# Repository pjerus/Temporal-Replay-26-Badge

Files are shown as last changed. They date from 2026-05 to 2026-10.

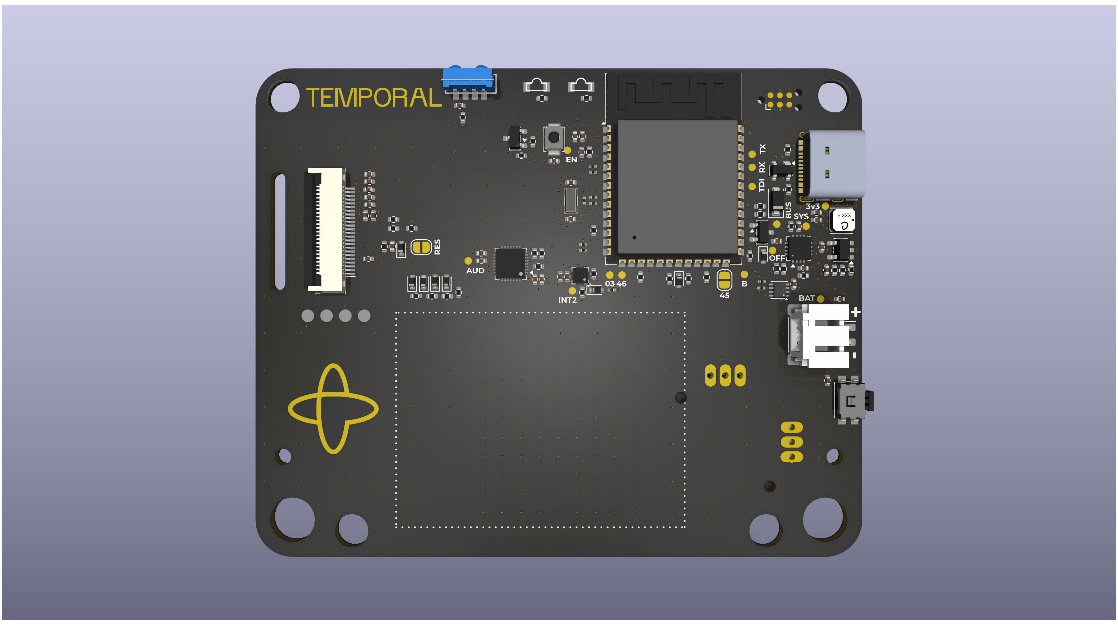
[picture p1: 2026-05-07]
hardware/BRAVO/export/V0_Temporal-BRAVO_Back.png

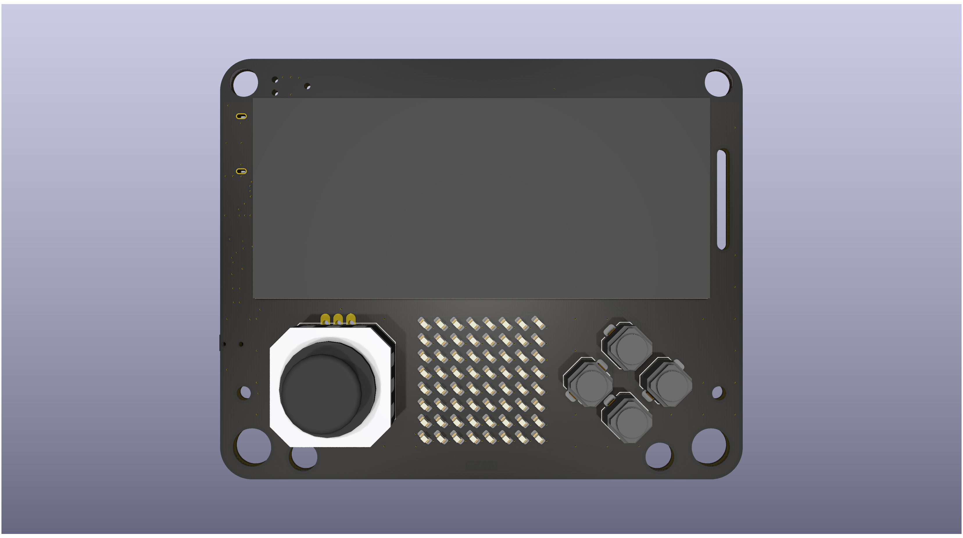
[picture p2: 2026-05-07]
hardware/BRAVO/export/V0_Temporal-BRAVO_Front.png

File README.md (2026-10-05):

# Temporal Badge

Conference badge for Temporal's events. The current build (`echo`) targets an
ESP32-S3-WROOM-1 (N16R8) on a custom board with a 128×64 SSD1309 OLED, IR TX/RX for
attendee pairing, joystick, tilt switch, and NVS-backed identity. (Earlier revisions —
see Hardware Targets below — used other modules; DELTA was an ESP32-S3-MINI-1 XIAO.)

## Hardware

- **MCU**: ESP32-S3 16r8, dual-core Xtensa LX7, 8 MB flash
- **Display**: SSD1309 128×64 OLED via hardware I2C (SDA=D4/GPIO5, SCL=D5/GPIO6)
- **IR**: NEC protocol TX (D2/GPIO3) + RX (D3/GPIO4)
- **Input**: 4 buttons (D7–D10), analog joystick (D0/D1), tilt switch (D6)

## Prerequisites

- Python 3.9+
- All other dependencies (PlatformIO, Temporal CLI, esptool) are installed by `ignition/setup.sh`

## Build & Flash (Ignition)

```bash
cd ignition
./setup.sh        # first time only — installs all dependencies
./start.sh        # build + flash all connected badges
./start.sh --build-and-flash  # explicit build + fresh filesystem + flash
./start.sh -y     # skip the pre-flash Enter prompt for a ready batch
```

Ignition treats each run as one connected hub batch. Temporal starts a parent
`FlashBadgesWorkflow` plus one human-readable `BadgeFlashWorkflow` child per
detected badge, so the UI shows per-badge flash/WiFi progress and results.

See [`ignition/README.md`](ignition/README.md) for full usage, including `--no-build`, `--build-only`, and `--firmware-dir` options.

## Build (Firmware)

```bash
cd firmware

# Echo badge (default)
./build.sh

# Charlie board
./build.sh charlie

# Non-interactive build (skip build-time network prompt)
./build.sh echo -n
```

Or directly via PlatformIO:
```bash
pio run -e echo
pio run -e charlie
```
Direct PlatformIO builds read `firmware/wifi.local.env` or `BADGE_*`
environment variables and fail if WiFi credentials or the server URL are
missing.

### Dev menu build

Normal firmware hides internal debug/test screens. To flash an Echo badge with
the dev menu enabled for diagnostics and badge-info editing:

```bash
cd firmware
pio run -e echo-dev -t upload --upload-port /dev/cu.usbmodem1101
```

`echo-dev` still uses the configured boop API; it only changes menu/debug
visibility. Use a local settings/server override if you need to avoid staging.

Normal firmware boots straight into the badge menu. Production builds show
Boop, Messages, Contacts, New Msg, Settings, and QR / Pair only while the
badge is unpaired; debug/test screens stay behind the dev menu build.

### MicroPython apps

MicroPython app source lives in `firmware/initial_filesystem/apps/` and is
embedded into firmware builds through `firmware/scripts/generate_startup_files.py`.
Use folder apps with a `main.py` entry point for anything larger than a demo.

Normal firmware does not show the generic Apps menu. Attendee-facing
MicroPython apps need a native `GUI.cpp` launcher and icon; diagnostics can
stay in the dev-menu Apps browser. See
[`firmware/initial_filesystem/apps/README.md`](firmware/initial_filesystem/apps/README.md)
for the full authoring, validation, and build workflow.

### Serial logging

To capture logs from every connected badge while testing hardware flows:

```bash
cd firmware
~/.platformio/penv/bin/python serial_log.py
```

The logger auto-detects USB serial ports, clears `firmware/logs/` by default,
and writes one log file per badge.

### Two-badge hardware test harness

The planned firmware hardware harness uses Ignition to build/flash two badges,
then drives them over USB serial for physical boop and clean-state tests.
See [`docs/hardware-test-harness.md`](docs/hardware-test-harness.md) and
[`specs/012-hardware-test-harness/tasks.md`](specs/012-hardware-test-harness/tasks.md).

## Power Management

The badge uses a 1000 mAh battery drawing ~10 mA in normal operation (~100 hours).
Power saving is tuned for multi-day conferences where WiFi reconnects (~400 mA
for several seconds) cost more than the deep sleep saves if triggered too often.

| State | Trigger | What happens |
|---|---|---|
| **Active** | Motion / button press | Full brightness, WiFi connected |
| **Dim** | 5 min no motion | LED matrix dims to brightness 3, WiFi stays connected |
| **Deep sleep** | 20 min no motion | 12 μA draw, WiFi disconnects, wakes on IMU motion |
| **Deep sleep (unpaired)** | 5 min no motion | Unpaired badges sleep sooner to save battery in storage |
| **Force sleep** | Hold **UP** button 5 seconds | Immediately enters deep sleep (disabled over USB) |

To wake from deep sleep, move or tilt the badge. After waking, WiFi reconnects
automatically.

## Configuration

Display, input, boop, and timing settings live in `settings.txt` on the
badge's FAT filesystem — no recompile needed. WiFi credentials and the server
URL are build-time secrets and are not written to the badge filesystem.

To configure a badge:
1. Copy `firmware/wifi.local.env.example` to `firmware/wifi.local.env`:
```
BADGE_WIFI_SSID=YourNetwork
BADGE_WIFI_PASS=YourPassword
BADGE_SERVER_URL=https://your-server.example.com
```
2. Build/flash from `firmware/`; the build embeds those values into the firmware.
3. Edit non-secret settings in `settings.txt` as needed:
```
[wifi]
ep_badge = /api/v1/badge
ep_boops = /api/v1/boops
```

`firmware/wifi.local.env` is ignored by git. Environment variables with the
same names override that file for one-off builds. Changing WiFi or backend URL
now requires rebuilding and reflashing the firmware.
Builds require `BADGE_WIFI_SSID`, `BADGE_WIFI_PASS`, and `BADGE_SERVER_URL`;
the badge depends on API connectivity for pairing, messaging, and schedule data.
Badge-facing API calls use MessagePack where supported. Schedule data uses a
compact MessagePack schema and is cached on-device with ETag sidecars. The
schedule app supports `MINE` and `ALL` modes, refreshes in the background on
open, and shows a ticket-page QR for editing an attendee's custom schedule.
Boop and ping list reads also use compact MessagePack arrays; see
[`firmware/src/README.md`](firmware/src/README.md#backend-wire-format) for the
wire contract and measured payload savings.

## Pairing QR

The on-device QR code encodes the badge's compact 12-character machine id,
uppercased for QR alphanumeric mode. The registration scanner uses that id to
attach the physical badge to an attendee record and the badge then fetches the
server-owned identity data.

## Serial Monitor

```bash
cd firmware
pio device monitor --port /dev/cu.usbmodem114101 --baud 115200
```

Or use `./flash.py` (default behavior) to flash and then auto-open monitor logs for one badge.

## Hardware Targets

| Target | Board | Defines file |
|---|---|---|
| `delta` | Temporal Badge DELTA (ESP32-S3-MINI-1, XIAO form factor) | `firmware/src/DeltaDefines.h` |
| `charlie` | Jumperless/Charlie board (ESP32-S3-DevKitC-1-N16R8V) | `firmware/src/CharlieDefines.h` |
| `echo` | Echo board production firmware | `firmware/src/EchoDefines.h` |
| `echo-dev` | Echo board with internal dev menu enabled | `firmware/src/EchoDefines.h` |

### Adding a new hardware target

1. Copy `firmware/src/DeltaDefines.h` → `firmware/src/MyBoardDefines.h`
2. Update pin numbers to match your schematic
3. Add `BADGE_HAS_*` flags for any optional peripherals your board has (see `firmware/src/CharlieDefines.h` for the full list)
4. Add a new `[env:myboard]` section to `firmware/platformio.ini` with `-DHARDWARE_MYBOARD`
5. Add `#include "MyBoardDefines.h"` to `firmware/src/HardwareConfig.h`

## Key Source Files

- [firmware/src/main.cpp](firmware/src/main.cpp) — setup() and loop()
- [firmware/src/HardwareConfig.h](firmware/src/HardwareConfig.h) — hardware target selector
- [firmware/src/DeltaDefines.h](firmware/src/DeltaDefines.h) — DELTA pin assignments
- [firmware/src/CharlieDefines.h](firmware/src/CharlieDefines.h) — Charlie pin assignments + feature flags
- [firmware/platformio.ini](firmware/platformio.ini) — build environments

## Repo Structure

| Directory | Contents |
|---|---|
| [`firmware/`](firmware/) | Arduino C++ firmware — active PlatformIO project |
| [`hardware/DELTA/`](hardware/DELTA/) | KiCad PCB — ESP32-S3-MINI-1 XIAO, SSD1309 OLED, IR, buttons |
| [`registrationScanner/`](registrationScanner/) | Quart + Temporal backend (badge enrollment + boop workflows) |
| [`specs/`](specs/) | Feature specs and implementation plans |
| [`assets/`](assets/) | Art and design resources |
| [`docs/`](docs/) | Design notes, photos, work log |

## Legacy Firmware

`firmware/Firmware-0308-modular/` and `firmware/Firmware-0308/` are previous Arduino IDE builds kept for reference. They use a different build system and are not maintained.

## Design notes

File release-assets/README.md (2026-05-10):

# Release-bundled assets

Files listed in [`manifest.json`](manifest.json) get attached to every
GitHub release of this repo as named assets, alongside the firmware
binary. They're served from a stable URL pattern that the badge's
Asset Library can fetch directly:

```
https://github.com/<owner>/<repo>/releases/latest/download/<name>
```

This is the right home for files that are **too large to bake into
the firmware image** (i.e. things `firmware/initial_filesystem/`
can't carry without inflating the OTA app slot — anything ≳ 100 KB,
realistically). The DOOM WAD lives here.

## Why not just initial_filesystem/?

`initial_filesystem/` files are embedded into the `.bin` via
`StartupFilesData.h` and ALSO copied to ffat on first boot. That's
fine for ≤ 100 KB things (a config file, a few PNGs). For a 4 MB
WAD it'd push the firmware off the OTA partition cliff. So we keep
the WAD out of the build, attach it to the release, and let the
badge pull it on demand into ffat.

## Adding a new bundled asset

1. Add an entry to `manifest.json`:

   ```json
   {
     "name": "soundpack-1.tar",
     "local_path": "firmware/data/soundpack-1.tar",
     "fallback_url": "",
     "registry_id": "soundpack-1",
     "description": "Optional sound pack for DOOM"
   }
   ```

   - `name`: the filename shown on the GitHub release (and the URL
     suffix the badge will GET).
   - `local_path`: where the file lives in the repo. Optional if
     `fallback_url` is set — CI will curl it instead.
   - `fallback_url`: used when `local_path` is missing (e.g. the
     file is gitignored). Optional.
   - `registry_id`: optional. If set, the staging script verifies
     that `registry/registry.json`'s entry with that id has a
     matching `sha256` and `size`. Mismatch fails the release build
     so you can't accidentally ship a stale manifest.

2. Add (or update) the matching entry in
   [`registry/registry.json`](../registry/registry.json) with the
   stable `/releases/latest/download/<name>` URL, the file's
   SHA-256, and its size in bytes.

3. PR + merge + cut a release. The
   [release-firmware.yml](../.github/workflows/release-firmware.yml)
   Action stages the file (local copy or download), verifies it
   against the registry, and uploads it to the release.

## Locally checking your changes

```
python3 scripts/stage_release_assets.py --check
```

`--check` runs the same verification CI does (sha256 / size match
between manifest, files, and registry) without writing any artifacts
or hitting the network if everything is local. Drop the `--check`
flag to actually stage files into `artifacts/release/`.

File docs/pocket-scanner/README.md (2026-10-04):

# Pocket Scanner

> Docs moved here from the retired `pjerus/temporal-badge-scanner` repo on 2026-10-04. Paths in the older specs, plans and checkpoints still say `upstream/firmware/...`; read that as `firmware/...` from the repo root.

A stripped-down fork of the Temporal Replay 26 badge firmware. Phase 1 ships a hardware-exercise demo that drives every I/O channel (joystick, buttons, IMU, OLED, 8×8 LED matrix). Phase 2 layers BLE / WiFi / IR scanning on top.

**Phase 1 status:** ✅ complete (4 commits on the `pocket-scanner-phase1` branch)

- **Spec:** `docs/pocket-scanner/superpowers/specs/2026-05-11-pocket-scanner-design.md`
- **Plan:** `docs/pocket-scanner/superpowers/plans/2026-05-11-pocket-scanner.md`
- **Upstream:** https://github.com/Architeuthis-Flux/Temporal-Replay-26-Badge (pinned to tag `0.2.4`)

## Hardware

ESP32-S3-WROOM-1 (16 MB flash, 8 MB octal PSRAM), 1.3" SSD1309 OLED on I²C, **8×8 IS31FL3731 monochrome LED matrix**, 2-axis analog joystick, 4 directional buttons, **LIS2DH12 3-axis IMU** (used as tilt/orientation sense), IR TX/RX (NEC), WiFi 2.4 GHz, Bluetooth 5 LE, 1000 mAh LiPo, USB-C.

## Build & flash

First-time setup (~5–10 min, ~500 MB):

```sh
cd ignition && ./setup.sh
```

Build + flash app partition:

```sh
cd firmware
~/.platformio/penv/bin/pio run -e echo-dev -t upload --upload-port /dev/cu.usbmodem2101
```

Flash FATFS data partition (required whenever `initial_filesystem/` changes — e.g. when adding or editing a MicroPython app):

```sh
~/.platformio/penv/bin/pio run -e echo-dev -t uploadfs --upload-port /dev/cu.usbmodem2101
```

Always use `~/.platformio/penv/bin/pio` directly — the system `pio` shim resolves to the wrong Python and fails with fatfs import errors.

## Restore to factory v0.2.4

```sh
~/Library/Arduino15/packages/esp32/tools/esptool_py/5.2.0/esptool \
  --port /dev/cu.usbmodem2101 --baud 921600 \
  write-flash 0x0 ../backups/firmware-v0.2.4/factory_echo_16MB.bin
```

This is a 16 MB full-chip image. Takes ~60 seconds. Wipes NVS-backed identity, so the badge boots as unpaired.

## What was changed from upstream

| Commit | Change |
|---|---|
| `feat(scanner)` | Added `/apps/scanner/main.py` — Phase 1 hardware demo |
| `chore: remove BADGE_HAS_DOOM` | Disabled DOOM build flag; deleted 4 MB `doom1.wad` |
| `feat: strip conference menu entries` | Removed Boop, Contacts, Badge Info, Map, Schedule, Sponsors, Credits |
| `feat: strip game menu entries` | Removed Draw, BreakSnake, Flappy, Synth, Tardigotchi |

Menu went from **24 curated + 6 dynamic** entries down to **12 curated + 6 dynamic**. Build size dropped from ~67.5% to ~60% of the OTA app slot (~290 KB saved on app + 4 MB on FATFS from the WAD).

Partition table is unchanged — upstream's CSV (`partitions_replay_16MB_doom.csv`) is OTA-frozen and must stay put for field-upgrade compatibility.

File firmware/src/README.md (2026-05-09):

# firmware/src — orientation map

The badge's C++ firmware. Domain-organized: each top-level folder owns one
subsystem. Pin / wire-protocol details and project-wide gotchas live in
`Temporal-Badge/CLAUDE.md`; this file is the "where do I look" map.

## Folder map

| Folder | Owns |
|---|---|
| `api/` | Explicit-only network helpers. `WiFiService.{h,cpp}` stays idle at boot and connects only when MicroPython `badge.http_get/post` asks for it. |
| `boops/` | Local IR contact exchange. Public facade in `BadgeBoops.h`. Implementation split: `BoopsJournal.cpp` (`/boops.json` + local writes), `BoopsProtocol.cpp` (state machine + frame codec), `BoopsHandlers.cpp` (per-type ops table for peer / exhibit / queue / kiosk / checkin / unknown), `BoopsFeedback.cpp` (marquee event ring, haptic/LED cues). `Internal.h` exposes intra-`boops/` symbols. |
| `hardware/` | Peripheral drivers + board-defines. `oled.cpp` (U8G2 wrapper), `LEDmatrix.{cpp,h}` + `LEDmatrixImages.h`, `Inputs.{cpp,h}`, `IMU.{cpp,h}`, `Haptics.{cpp,h}`, `Power.{cpp,h}`, `qrcode.{c,h}`, `HardwareConfig.h`, per-board `EchoDefines.h` / `CharlieDefines.h` / `DeltaDefines.h`. |
| `hw/` | Lower-level NEC IR protocol (RX/TX state machines, encoder/decoder). Used by `ir/BadgeIR.cpp`. Kept separate because the files are protocol-abstraction-pure with no other dependencies. |
| `identity/` | Per-badge state. `BadgeUID.{cpp,h}` (eFuse MAC + UUID v5), `BadgeInfo.{cpp,h}` (`/badgeInfo.json` defaults + read-only UI source), `BadgeVersion.h`. |
| `infra/` | Process plumbing. `Scheduler.{cpp,h}` (cooperative service loop), `Filesystem.{cpp,h}` (FAT helpers + atomic writes), `BadgeConfig.{cpp,h}` (settings + font-family table), `Bitops.h`, `DebugLog.h`. |
| `ir/` | High-level IR transport. `BadgeIR.{cpp,h}` (Core 0 task + python queue + multi-word frame API for boop pairing). |
| `led/` | Saved ambient LED matrix runtime. `LEDAppRuntime.{h,cpp}` owns the persisted LED mode, poster frames for OLED previews, native animations, Game of Life/custom patterns, and foreground override restoration. |
| `messaging/` | Reserved for future local messaging surfaces. Native ping-backed messaging was removed for the offline firmware. |
| `micropython/` | C++ side of the MicroPython bridge. `ReplayMicropythonAPI.cpp` (thin pump aggregator), `MicroPythonBridge.cpp` (lifecycle + GC around foreground app runs), `StartupFiles.{cpp,h}` (generated startup files provisioned onto the FatFS `ffat` partition). `badge_mp_api/` (subdir) holds the per-subsystem HAL: `mp_api_display.cpp` / `mp_api_input.cpp` / `mp_api_led.cpp` / `mp_api_imu.cpp` / `mp_api_haptics.cpp` / `mp_api_mouse.cpp` / `mp_api_ir.cpp` / `mp_api_badge_data.cpp` / `mp_api_dev.cpp` plus shared `Internal.h`. The Python-side usermod itself (QSTR table, MP_DEFINE_CONST_FUN_OBJ_*, and `matrix_app_*` ambient LED bridge) lives outside `firmware/src/` at `firmware/micropython/usermods/temporalbadge/`. |
| `screens/` | GUI screens. Base class in `Screen.{h,cpp}`; one TU per screen (`BoopScreen.cpp`, `TextInputScreen.cpp`, `LEDScreen.cpp`, etc.). `EmojiText.{h,cpp}` + `TextInputLayouts.{h,cpp}` are shared screen helpers. |
| `ui/` | Display rendering layer above hardware drivers. `GUI.{cpp,h}` (GUIManager + screen stack), `BadgeDisplay.{cpp,h}` (legacy render mode dispatch + nametag overlay), `OLEDLayout.{h,cpp}` (shared OLED bands, selected rows, footers, fit helpers), `ButtonGlyphs.{h,cpp}` (shape-based button hints), `QRCodePlate.{h,cpp}` (scan-friendly OLED QR plate), `FontCatalog.{cpp,h}` (u8g2 font tables), `Images.h`, `graphics.h`. |
| `main.cpp` | Setup + loop entry. Stays at root. |
| `BadgeGlobals.cpp` | Global instance definitions for `oled badgeDisplay`, `Inputs inputs`, etc. Stays at root. |

## Offline Runtime

The badge boots straight into the local UI. There is no QR pairing gate, no
background WiFi connection, no Replay API transport, and no ping polling.

Contacts exchanged over IR are written to `/boops.json`. The badge owner's
editable identity lives in `/badgeInfo.json`; the badge UI only reads it.
Users update it over USB and can read `https://badge.temporal.io` for update
instructions.

Schedule, map, visual assets, MicroPython apps, and explicit hacker HTTP helpers
remain available. Native HTTP is limited to MicroPython `badge.http_get()` and
`badge.http_post()` calls, which connect only when the app asks.

## How do I…

| Task | Files to touch |
|---|---|
| Add a new screen | `screens/Screen.h` (extend the base class), create `screens/<Name>Screen.{h,cpp}`, register in `ui/GUI.cpp:GUIManager::begin()`, add a `ScreenId` enum entry, hook into the main menu in `ui/GUI.cpp` if user-facing |
| Add a Python `badge.<thing>` API | `micropython/badge_mp_api/<category>.cpp` for the `temporalbadge_runtime_*` impl, then declare in `firmware/micropython/usermods/temporalbadge/temporalbadge_runtime.h`, wire the HAL pass-through in `temporalbadge_hal.{c,h}`, register the Python binding in `modtemporalbadge.c` (MP_DEFINE_CONST_FUN_OBJ_* + the globals table), and regenerate the MicroPython QSTR header if new Python-visible names were added |
| Add explicit MicroPython HTTP behavior | Keep it in `micropython/badge_mp_api/mp_api_http.cpp` or Python app code. Do not add background badge-owned API polling. |
| Add a native-backed Python UI helper | Put shared rendering in `ui/OLEDLayout.{h,cpp}`, `ui/ButtonGlyphs.{h,cpp}`, or `ui/QRCodePlate.{h,cpp}` first, expose a tiny `temporalbadge_runtime_ui_*` wrapper from `micropython/badge_mp_api/mp_api_display.cpp`, then make `initial_filesystem/lib/badge_ui.py` call that helper with a Python fallback |
| Add a new boop handler | Add a per-handler block in `boops/BoopsHandlers.cpp` (the `BOOP_HANDLER` macro takes Cap, lower, label, doFieldExchange), implement the four `<lower>_<callback>` functions, add a `BoopType` enum entry |
| Use the message keyboard | `screens/TextInputScreen.cpp` owns text entry, emoji pages, and joystick cursor movement over the keyboard |
| Change ambient LED behavior | `led/LEDAppRuntime.{h,cpp}` owns the persisted mode and restore path; `screens/LEDScreen.cpp` owns the OLED carousel/editor; MicroPython foreground drawing must use `led_override_begin()` / `led_override_end()` or `matrix_app_start()` |
| Bump a font / image | `ui/FontCatalog.cpp` for the font grid + flat catalog (the `fonts/` directory under `firmware/src/` is gone — fonts are u8g2 built-ins now), `ui/Images.h` for bitmaps |
| Debug IR/boops over serial | Flip `log_ir` or `log_boop` to `1` in `settings.txt`, then watch `firmware/serial_log.py` |
| Trace a runtime crash | Look at `[boot] reset_reason=N` on the next boot's serial. Decode addresses via `~/.platformio/penv/bin/pio device monitor` paired with `~/.platformio/packages/toolchain-xtensa-esp-elf/bin/xtensa-esp-elf-addr2line -pfiaC -e firmware/.pio/build/echo/firmware.elf <addrs…>` |

## Threading model

- **Core 0** runs `irTask` (which drives `boops/BoopsProtocol.cpp`'s state machine) and the IR low-level RMT decoders in `hw/ir/`.
- **Core 1** runs the Arduino `loop()` task — GUI, explicit MicroPython HTTP when requested, and journal saves. **24 KB stack** via `SET_LOOP_TASK_STACK_SIZE(24*1024)` in `main.cpp`; keep the headroom for MicroPython and optional HTTP paths.
- `LEDAppRuntime` is the single long-lived ambient LED owner. Foreground surfaces such as the keyboard and MicroPython apps enter an override, draw, and then release back to the saved LED app state.
- The MicroPython `mpy_service_pump()` (in `micropython/ReplayMicropythonAPI.cpp`) runs while Python code is sleeping or polling; it services inputs, OLED/LED ownership, the mouse overlay, IMU, and haptics so apps stay responsive.

## Build / flash

The Temporal flash worker is the authoritative compile gate (local `.pio/build/<env>/` cache has masked header-dep failures during multiple refactors):
```bash
cd ignition && yes '' | ./start.sh -e echo
```

For local sanity check before flashing, force a clean rebuild:
```bash
rm -rf firmware/.pio/build/{echo,charlie} && cd firmware && ./build.sh echo -n
```

## MicroPython app workflow

App source lives under `firmware/initial_filesystem/`, not `firmware/src/`.
When those files change, run:

```bash
cd firmware
black initial_filesystem/apps/<app> initial_filesystem/lib/badge_app.py initial_filesystem/lib/badge_ui.py
python3 -m py_compile initial_filesystem/apps/<app>/*.py initial_filesystem/lib/badge_app.py initial_filesystem/lib/badge_ui.py
python3 scripts/generate_startup_files.py
pio run -e echo
```

Commit the source files plus the generated
`src/micropython/StartupFilesData.h` and
`scripts/startup_hash_history.json`. Normal firmware does not show the generic
Apps menu; attendee-facing MicroPython apps need a `GUI.cpp` launcher and a
main-menu icon.

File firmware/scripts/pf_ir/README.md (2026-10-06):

# Power Functions over infrared

Scripts from the 2026-10-06 experiment: a badge drives LEGO Power Functions motors through a
LEGO IR receiver, commanded from the Mac over USB. Throwaway-grade, kept for reference.

Needs a badge flashed with the `echo-ir` build (no emotion BLE service; with it the IR receiver
has no memory to start). Run with PlatformIO's Python, which has pyserial:

    cd firmware/scripts/pf_ir
    ~/.platformio/penv/bin/python badge_exec.py ir_listen.py 100 > capture.txt   # press the LEGO remote at the badge
    ~/.platformio/penv/bin/python pf_decode.py capture.txt
    ~/.platformio/penv/bin/python pf_send.py 5 1500                              # both outputs, 1.5 s
    ~/.platformio/penv/bin/python badge_exec.py ir_selfcheck.py                  # badge hears its own echo

| File | What it does |
|---|---|
| `badge_exec.py` | Runs a Python file on the badge through its USB raw REPL. Waits 1.2 s after connecting: the firmware ignores input for 350 ms. No app may be open on the badge. |
| `ir_listen.py` | Runs on the badge. Records raw IR for 90 s or 60 frames. |
| `pf_decode.py` | Decodes a capture as Power Functions frames. |
| `ir_send_pf.py` | Runs on the badge (template filled in by `pf_send.py`). Sends "combo direct" frames every 90 ms, then coast. |
| `pf_send.py` | Mac-side wrapper for the above. |
| `ir_selfcheck.py` | Sends a coast frame and captures the badge's own reflection. |
| `example_capture.txt` | Pat's remote, channel 1. |

Found: the remote sends mode 1 (combo direct: each output forward, backward or coast) on channel 1,
repeating about every 100 ms; the receiver stops when frames stop. Transmit power must be raised
from the default 10% to 50% to reach a receiver inside a model. Aim the badge's top edge at the dome.

## Driving the tank base

    ~/.platformio/penv/bin/python pf_drive.py 5 5 1500           # both treads forward, speed 5, 1.5 s
    ~/.platformio/penv/bin/python pf_drive.py 5 -5 1000 0 0 300 -3 -3 800   # spin right, pause, back up

`pf_drive.py` (Mac side) fills in `ir_drive.py` (badge side). Speeds are -7..7 per tread, positive
forward. It uses the "combo PWM" mode: seven speed steps per output, and the receiver still stops
when frames stop.

Measured 2026-10-06 on Pat's base, treads off the ground: output A is the left tread, B the right;
the right side is flipped in `ir_drive.py` because the two motors face opposite ways; speed 3 is
the slowest that turns both treads (at 2 the left one stalls). Not yet tested on the floor.

Floor results, 2026-10-06 (carpet, no load on the platform, speed 4): about one foot in 1.5 s; the left tread runs
slower, corrected by `LEFT_TRIM = 1.09` in `ir_drive.py` (straight forward and in reverse);
a spin at 4 / -4 turns about 180 degrees per second, so 500 ms is a quarter turn. Fractional
speeds alternate between the two nearest steps frame by frame.

## Driving over Bluetooth (no cable)

Needs the badge on the `echo-drive` firmware. Set `ROCKY_TREAD_SECRET` to the badge's 8-character
shared secret first (it is the emotion channel's secret; do not put it in a file here).

    uv run --with bleak pf_ble_drive.py --status          # connect, print status and memory
    uv run --with bleak pf_ble_drive.py 4 4 1500          # forward, speed 4, 1.5 s

The script resends the command five times a second; each is valid for 0.6 s. If the script dies or
Bluetooth drops, the badge sends a stop and goes quiet, and the LEGO receiver stops by itself too.
Trim, right-side flip, channel and IR power are `tr_*` lines in the badge's `settings.txt`.
Status prints free internal memory now and the lowest since power-on; the badge refuses to drive
below 6 KB.

Hardware results, 2026-10-06. Free internal memory with a controller connected: 12.5 KB on USB
(lowest since power-on 7.25 KB), about 19 KB on battery. Driven cable-free on carpet: forward,
back, both quarter turns. Stops confirmed: script killed mid-move (stopped within a second) and
IR beam blocked (stops, resumes when uncovered). Bluetooth switched off mid-move was not tested.
The ten-minute soak has not been run. The battery percent in the status reads 0 on battery.

Two builds carry the drive service: `echo-drive` (spare badge, announces as "Rocky IR Tread",
shows a status line) and `echo-face-drive` (the face badge: face stays on screen, Bluetooth name
unchanged). To drive the face badge set `ROCKY_TREAD_NAME=TemporalBadge`.

`badge.dev("info")` over the USB REPL reads name|title|company; `badge.dev("info", "name", "")`
sets one field. Both badges were blanked this way.

## Drive app on the badge

Both drive builds have a DRIVE entry on the main menu: joystick steers (gentle push slow, full
push full speed), up/down buttons held = full speed forward/reverse, left/right buttons = a
timed quarter turn, up and down together = stop and exit. It feeds the same stop logic as the
Bluetooth drive, and Bluetooth drive commands are dropped while it is open. The heading shows
the badge's name (set with `badge.dev("info", "name", "...")`): the spare is "Rocky IR Tread",
the face badge "Rocky Face". Checked by Pat on the face badge 2026-10-06.

## Syma S107G helicopter

The same raw IR sender flies a Syma S107G indoor helicopter (38 kHz; 2000/2000 us header, 32 bits
of yaw, pitch, channel + throttle, trim; a frame every 120 ms on channel A). The frame is 34
pulses, so TX-only builds allow 40 per raw send. From the Mac over USB:
`s107.py <yaw> <pitch> <throttle> <ms>` (yaw and pitch 0..127 with 63 centred, throttle 0..127).
On the badge: the HELI menu entry on the drive builds. Up/down buttons step the throttle,
left/right trim, joystick turns and tilts, up and down together cuts the rotors and exits.
Settings `hl_chan`, `hl_trim`, `hl_step`. Rotors start near 30% throttle. Proven 2026-10-06 on
Rocky Face: rotors spin from the script and from the app. Stick and trim directions and real
flight are untested, and the screen still shows a sent/failed frame counter from that proving.

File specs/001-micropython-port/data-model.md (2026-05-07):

# Data Model: MicroPython Port for Temporal Badge DELTA

**Phase**: 1 | **Date**: 2026-03-10 | **Feature**: `001-micropython-port`

---

## Entities

### 1. Badge ID

| Field | Type | Source | Constraints |
|---|---|---|---|
| `uid_bytes` | `bytes` | `machine.unique_id()` | Always 6 bytes on ESP32-S3; zero-padded if shorter |
| `uid_hex` | `str` | derived | 12 lowercase hex characters; `uid_hex = ''.join(f'{b:02x}' for b in uid_bytes).ljust(12,'0')[:12]` |

**Used in**: boot welcome message, IR TX payload, display status text.

---

### 2. XBM Bitmap

| Field | Type | Value |
|---|---|---|
| Width | int | 128 pixels |
| Height | int | 64 pixels |
| Encoding | `framebuf.MONO_HLSB` | LSB-first, row-major (matches XBM format) |
| Size | bytes | 1024 bytes (128 × 64 / 8) |

**Sources**:
- **Live mode**: Fetched from `GET /api/v1/badge/<uuid>/qr.xbm` as raw XBM text, parsed by `_parse_xbm_response()`.
- **BYPASS mode**: `graphics.MOCK_QR` or `graphics.MOCK_NAMETAG` (pre-converted bytes literals).
- **Arrow sprites**: `graphics.DOWN_ARROW_FILLED`, `graphics.UP_ARROW_FILLED`, etc. (9×6, 12 bytes each).
- **Base graphic**: `graphics.GRAPHICS_BASE` (128×64, 1024 bytes) — used as main-mode background overlay.

**Validation**: Any fetched XBM blob MUST be ≥ 1024 bytes before rendering. Truncate at 1024 if longer.

**Rendering**:
```python
import framebuf
fb = framebuf.FrameBuffer(bytearray(xbm_bytes[:1024]), 128, 64, framebuf.MONO_HLSB)
display.blit(fb, 0, 0)
display.show()
```

---

### 3. Display Mode

| Mode | Constant | Trigger |
|---|---|---|
| Boot | `MODE_BOOT = 0` | Active during boot sequence |
| QR | `MODE_QR = 1` | After WiFi connect; timed 10 s; also BTN_DOWN cycle |
| Main | `MODE_MAIN = 2` | After nametag fetch; default interactive mode |

**State transitions**:
```
BOOT → QR (after QR bitmap ready) → MAIN (after 10 s + nametag fetch)
MAIN ←→ QR   (BTN_UP/BTN_DOWN cycle)
```

---

### 4. Button State

Each of the 4 directional buttons:

| Field | Type | Value |
|---|---|---|
| `pin` | GPIO | 8=UP, 9=DOWN, 10=LEFT, 11=RIGHT |
| `state` | bool | `False` = pressed (active-low), `True` = released |
| `last_reading` | bool | Previous raw GPIO value |
| `last_debounce_ms` | int | `utime.ticks_ms()` at last state transition |
| `indicator_x` | int | OLED x pixel for press indicator dot |
| `indicator_y` | int | OLED y pixel for press indicator dot |
| `debounce_ms` | int | 40 ms |

**Indicator positions** (from Firmware-0306):
```
BTN_UP    → (118, 48)
BTN_DOWN  → (118, 58)
BTN_LEFT  → (113, 53)
BTN_RIGHT → (123, 53)
```

**Action on press**: BTN_UP → trigger `irTransmitUID()`.

---

### 5. Joystick State

| Field | Type | Constraints |
|---|---|---|
| `raw_x` | int | 0–4095 (12-bit ADC, GPIO1) |
| `raw_y` | int | 0–4095 (12-bit ADC, GPIO2) |
| `norm_x` | float | ±1.0, clamped to unit circle |
| `norm_y` | float | ±1.0, clamped to unit circle |
| `dot_x` | int | OLED pixel x; center=100, radius=6 |
| `dot_y` | int | OLED pixel y; center=53, radius=6 |

**Poll interval**: 50 ms.

**Normalization**:
```python
nx = (raw_x - 2048) / 2048.0
ny = (raw_y - 2048) / 2048.0
dist = sqrt(nx**2 + ny**2)
if dist > 1.0:
    nx /= dist; ny /= dist
dot_x = 100 + round(nx * 6)
dot_y =  53 + round(ny * 6)
```

---

### 6. Tilt Switch State

| Field | Type | Value |
|---|---|---|
| `state` | bool | `False` = tilted (active-low), `True` = upright |
| `last_reading` | bool | Previous raw GPIO value |
| `last_debounce_ms` | int | `utime.ticks_ms()` at last transition |
| `debounce_ms` | int | 300 ms |

**Display**: When tilted (`state == False`), fill rect at (84, 48). When upright, fill rect at (84, 54).

---

### 7. IR NEC Frame

One transmitted/received unit of the NEC protocol:

| Field | Type | Value |
|---|---|---|
| `address` | uint8 | 0x42 (badge-to-badge protocol) |
| `command` | uint8 | One byte of the 6-byte badge UID |
| `address_inv` | uint8 | `~address & 0xFF` = 0xBD |
| `command_inv` | uint8 | `~command & 0xFF` |

**Full NEC frame bit pattern (MSB first in wire order, LSB first in RMT)**:
`leader_burst(9ms) + leader_space(4.5ms) + [address LSB→MSB] + [~address LSB→MSB] + [command LSB→MSB] + [~command LSB→MSB] + stop_burst(562µs)`

---

### 8. IR UID Transmission

One complete badge-ID transmission = 6 consecutive NEC frames.

| Field | Type | Value |
|---|---|---|
| Frames | int | 6 |
| Address | uint8 | 0x42 |
| Commands | bytes | `uid_bytes[0..5]` (6 MAC bytes) |
| Inter-frame gap | int | 50 ms |
| Total TX time | int | ~6 × 110 ms = ~660 ms plus gaps = ~960 ms |

---

### 9. IR UID Reception Buffer

State machine accumulating a 6-byte UID from incoming NEC frames:

| Field | Type | Value |
|---|---|---|
| `rx_buf` | list | 0–6 command bytes received so far |
| `rx_count` | int | 0–6 |
| `last_byte_ms` | int | `utime.ticks_ms()` of last received byte |
| `timeout_ms` | int | 500 ms — discard partial buffer on silence |

**State transitions**:
```
IDLE → receiving byte 1/6 (addr==0x42)
receiving → receiving byte N/6 (each new NEC frame with addr 0x42, < 500ms gap)
receiving → UID complete (6 bytes received → assemble hex string → post to _received_uids)
receiving → IDLE (500 ms gap with no new frame → discard rx_buf)
```

**Non-badge NEC**: Any NEC frame with `address != 0x42` is displayed as "IR: {protocol}" for 1 s, then returns to "IR: listening...".

---

### 10. VFS Python Files

Files copied to the badge VFS by `flash.sh`. Available to `import` at runtime.

| File | Description | Sensitive? |
|---|---|---|
| `config.py` | GPIO pins, timing constants, BYPASS flag | No — VFS-resident intentionally |
| `boot.py` | Boot sequence: WiFi, NTP, QR display | No |
| `main.py` | Main interactive loop; nametag mode | No |
| `ir_nec.py` | NEC TX/RX class implementations | No |
| `badge_sdk.py` | `Badge` class — public app SDK | No |
| `graphics.py` | XBM bytes literals from graphics.h | No |
| `creds.py` | WiFi SSID/PASS, SERVER_URL | **Yes — gitignored; never commit** |

---

### 11. Board Configuration Files

Files in `boards/TEMPORAL_BADGE_DELTA/` that define the MicroPython port:

| File | Purpose |
|---|---|
| `mpconfigboard.h` | Board name macro, USB-CDC, no BT stack |
| `mpconfigboard.cmake` | IDF target, sdkconfig layer order, frozen manifest path |
| `sdkconfig.board` | 8 MB QIO, SPIRAM, HMAC peripheral enable |
| `partitions.csv` | NVS(24KB) + factory(4MB) + vfs(4MB) |
| `manifest.py` | Freeze `ssd1306`, `urequests` |
| `pins.csv` | GPIO → `BOARD_*` name mapping (must match constitution table) |

---

## State Transitions: Boot Sequence

```
power-on
  └─→ [BOOT mode] display "Temporal / Badge DELTA / Starting..."
       ├─ BYPASS=True
       │    └─ delay BYPASS_DELAY_MS
       │         └─ display "Connected (bypass)"
       └─ BYPASS=False
            └─ WiFi connect (WIFI_TIMEOUT_MS=5000)
                 └─ on failure: display "WiFi failed", halt
                 └─ on success: display "Connected to <SSID>"
                      └─ NTP sync (BYPASS skips)
                           └─ fetch QR bitmap (BYPASS uses MOCK_QR)
                                └─ [QR mode] display QR for QR_DISPLAY_MS=10000
                                     └─ fetch nametag (BYPASS uses MOCK_NAMETAG)
                                          └─ [MAIN mode] main event loop (never returns)
```

---

## Config Constants (config.py)

| Name | Type | Default | Description |
|---|---|---|---|
| `I2C_SDA` | int | 5 | SSD1309 SDA |
| `I2C_SCL` | int | 6 | SSD1309 SCL |
| `I2C_FREQ` | int | 400000 | I2C frequency Hz |
| `BTN_UP` | int | 8 | Button GPIO (active-low) |
| `BTN_DOWN` | int | 9 | Button GPIO (active-low) |
| `BTN_LEFT` | int | 10 | Button GPIO (active-low) |
| `BTN_RIGHT` | int | 11 | Button GPIO (active-low) |
| `JOY_X_PIN` | int | 1 | Joystick X ADC GPIO |
| `JOY_Y_PIN` | int | 2 | Joystick Y ADC GPIO |
| `TILT_PIN` | int | 7 | Tilt switch GPIO (active-low) |
| `IR_TX_PIN` | int | 3 | IR transmit GPIO |
| `IR_RX_PIN` | int | 4 | IR receive GPIO (TSOP output) |
| `WIFI_TIMEOUT_MS` | int | 5000 | WiFi connect timeout |
| `QR_DISPLAY_MS` | int | 10000 | QR display duration |
| `BYPASS_DELAY_MS` | int | 3000 | BYPASS mode simulated delay |
| `TILT_SHOWS_BADGE` | bool | False | Future: tilt → nametag mode |
| `BYPASS` | bool | True | Dev flag; False for conference |

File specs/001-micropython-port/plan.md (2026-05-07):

# Implementation Plan: MicroPython Port for Temporal Badge DELTA

**Branch**: `001-micropython-port` | **Date**: 2026-03-10 | **Spec**: [spec.md](spec.md)
**Input**: Feature specification from `/specs/001-micropython-port/spec.md`

## Summary

Port the Arduino Firmware-0306 badge firmware to MicroPython targeting the ESP32-S3-MINI-1 (XIAO form factor). Deliverables: canonical `firmware/micropython-build/` directory with board definition, Python VFS files, NEC IR implementation via RMT, build script, and flash script. Badge ID sourced from `machine.unique_id()`. No eFuse/HMAC operations in scope.

## Technical Context

**Language/Version**: MicroPython v1.24.0 (Python 3.4 subset); ESP-IDF v5.2.3; build host macOS Apple Silicon
**Primary Dependencies**: `ssd1306` (frozen driver), `urequests` (frozen), `esp32.RMT` (built-in), `_thread` (built-in), `machine.ADC`, `machine.Pin`
**Storage**: 8 MB QIO flash. Partitions: NVS 24 KB, factory app 4 MB, VFS 4 MB. VFS holds Python files deployed via `mpremote`.
**Testing**: Manual only per constitution (no automated test runner). Verification: flash → USB REPL → OLED observation → two-badge IR test.
**Target Platform**: ESP32-S3-MINI-1 XIAO; board definition `TEMPORAL_BADGE_DELTA`. USB-CDC REPL at `/dev/cu.usbmodem*`.
**Project Type**: Embedded firmware (conference badge OS)
**Performance Goals**: Boot to main loop ≤ 10 s (BYPASS mode); main loop iteration ≤ 50 ms; IR RX non-blocking (runs on second thread).
**Constraints**: App binary ≤ 4 MB (partition limit); offline-capable BYPASS mode; no OTA; no debug-build watchdog.
**Scale/Scope**: 2,000 units; flashed once; no OTA path after manufacturing flash.

## Constitution Check

*GATE: Must pass before Phase 0 research. Re-checked after Phase 1 design.*

| Principle | Status | Notes |
|---|---|---|
| I. MicroPython-First | ✅ PASS | All application logic in Python. badge_crypto C module is **out of scope** for this spec — not built, not linked. Badge ID from `machine.unique_id()`, not eFuse. |
| II. Firmware-0306 Parity | ✅ PASS | This spec IS the parity port. Boot sequence, display modes, IR pairing (NEC 0x42), button/joystick/tilt behavior, and BYPASS mode all replicate Firmware-0306.ino exactly. |
| III. Credentials-at-Build | ✅ PASS | Prototyping exception active. WiFi creds in VFS `creds.py` (gitignored). `config.py` contains only GPIO pins and timing constants — no secrets. |
| IV. Backend Contract Compliance | ✅ PASS | This spec does not make HMAC-signed requests. Existing unsigned endpoints (`/qr.xbm`, `/info`) accessed via `urequests`. `badge_sdk.py` `ping()` → IR transmit only; no HTTP pings in scope. |
| V. Reproducible Build | ✅ PASS | Pinned: MP v1.24.0, IDF v5.2.3. Apple Silicon: `CFLAGS_EXTRA="-Wno-gnu-folding-constant"` (proven from prior work). sdkconfig layer order: base → usb → ble → sdkconfig.board. |
| VI. Hardware Safety | ✅ PASS | `pins.csv` MUST use the confirmed GPIO table from constitution (SDA=5, SCL=6, BTN_UP=8, BTN_DOWN=9, BTN_LEFT=10, BTN_RIGHT=11, JOY_X=1, JOY_Y=2, TILT=7, IR_TX=3, IR_RX=4). No eFuse operations. |

**Constitution verdict: ALL GATES PASS. Proceed to Phase 0.**

## Project Structure

### Documentation (this feature)

```text
specs/001-micropython-port/
├── plan.md              # This file (/speckit.plan command output)
├── research.md          # Phase 0 output (/speckit.plan command)
├── data-model.md        # Phase 1 output (/speckit.plan command)
├── quickstart.md        # Phase 1 output (/speckit.plan command)
├── contracts/           # Phase 1 output (/speckit.plan command)
│   └── badge_sdk.md     # badge_sdk.py public API contract
└── tasks.md             # Phase 2 output (/speckit.tasks command - NOT created by /speckit.plan)
```

### Source Code (repository root)

```text
firmware/micropython-build/          # canonical source directory (NEW — does not exist yet)
├── boards/
│   └── TEMPORAL_BADGE_DELTA/
│       ├── mpconfigboard.h          # board name, USB-CDC, PSRAM, no BT stack
│       ├── mpconfigboard.cmake      # IDF target esp32s3, sdkconfig layers, frozen manifest
│       ├── sdkconfig.board          # 8 MB QIO, HMAC peripheral, SPIRAM, partitions path
│       ├── partitions.csv           # NVS(24K) + factory(4M) + vfs(4M)
│       ├── manifest.py              # freeze ssd1306 + urequests (no _wifi_creds for this spec)
│       └── pins.csv                 # GPIO → board name (must match constitution table)
├── modules/                         # C extension directory (empty for this spec)
│   └── .gitkeep                     # keeps directory in git
├── config.py                        # GPIO pins, timing constants, BYPASS flag
├── boot.py                          # WiFi+NTP+QR display boot sequence
├── main.py                          # enrollment wait, nametag fetch, main interactive loop
├── ir_nec.py                        # NEC TX/RX via esp32.RMT; IRQRX thread
├── badge_sdk.py                     # Badge class: uid(), display(), ping(), pings()
├── graphics.py                      # Python bytes literals from graphics.h PROGMEM arrays
├── build.sh                         # reproducible build (pins MP v1.24.0 + IDF v5.2.3)
└── flash.sh                         # esptool erase+flash + mpremote VFS copy

```

**Structure Decision**: Single embedded-firmware project rooted at `firmware/micropython-build/`. No frontend/backend split. Python VFS files live at root level (copied verbatim to badge VFS by `flash.sh`). Board definition self-contained under `boards/TEMPORAL_BADGE_DELTA/`. The `modules/` directory is reserved for future badge_crypto C extension (a separate spec); this spec leaves it empty.

**Reference material used during design**: `firmware/shy-micropython-build/` (from `remotes/origin/shy-micropython`) provides validated board definition patterns (cmake layer order, manifest format, build.sh structure, mpy-cross flag). **Files from that directory MUST NOT be copied wholesale** — pin assignments are wrong and the firmware scope (HMAC, NVS UUID, enrollment) does not match this spec.

## Complexity Tracking

> No Constitution violations requiring justification.

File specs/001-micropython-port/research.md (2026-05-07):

# Research: MicroPython Port for Temporal Badge DELTA

**Phase**: 0 | **Date**: 2026-03-10 | **Feature**: `001-micropython-port`

This document resolves all NEEDS CLARIFICATION items from the Technical Context and documents design decisions with rationale.

---

## Decision 1: NEC IR TX via esp32.RMT

**Question**: How should NEC IR transmission be implemented on MicroPython v1.24.0 ESP32-S3?

**Decision**: Use `esp32.RMT` in TX mode with a 38 kHz carrier.

**Implementation sketch**:
```python
import esp32, machine

class NECTX:
    # RMT at 1 µs/tick: clock_div = 80 (80 MHz / 80 = 1 MHz)
    CLOCK_DIV = 80
    CARRIER_FREQ = 38_000   # Hz
    CARRIER_DUTY = 50       # %

    # NEC timing in µs (round to nearest tick)
    LEADER_BURST = 9000
    LEADER_SPACE = 4500
    BIT_BURST    = 562
    BIT_0_SPACE  = 562
    BIT_1_SPACE  = 1688
    END_BURST    = 562

    def __init__(self, pin_num):
        self._rmt = esp32.RMT(
            0,
            pin=machine.Pin(pin_num),
            clock_div=self.CLOCK_DIV,
            tx_carrier=(self.CARRIER_FREQ, self.CARRIER_DUTY, 1),
            idle_level=False,
        )

    def _encode_frame(self, address, command):
        """Return flat tuple of (high, low, high, low, ...) durations for one NEC frame."""
        pulses = [self.LEADER_BURST, self.LEADER_SPACE]
        byte_sequence = [address, ~address & 0xFF, command, ~command & 0xFF]
        for byte in byte_sequence:
            for bit in range(8):
                pulses.append(self.BIT_BURST)
                pulses.append(self.BIT_1_SPACE if (byte >> bit) & 1 else self.BIT_0_SPACE)
        pulses.append(self.END_BURST)
        pulses.append(0)   # trailing 0 stops the RMT
        return tuple(pulses)

    def send(self, address, command):
        self._rmt.write_pulses(self._encode_frame(address, command), start=1)
        self._rmt.wait_done(timeout=100)
```

**Rationale**: RMT is the correct hardware peripheral for generating precise IR timing. The `tx_carrier` parameter generates the 38 kHz modulation automatically — no software bit-banging needed. This matches how the Arduino `IRremote` library uses the same peripheral internally.

**Alternatives considered**:
- UART-based IR (as in shy-micropython-build): Does not generate carrier; only works if the IR LED driver circuits include their own oscillator. The DELTA hardware uses a raw LED + driver, so carrier must be generated in software/hardware. **Rejected**.
- Pure Python bit-banging: Timing jitter from MicroPython GIL and GC is too large for NEC (± few µs tolerance). **Rejected**.

---

## Decision 2: NEC IR RX via GPIO IRQ pulse measurement

**Question**: Should RX use `esp32.RMT` receive mode or GPIO interrupts?

**Decision**: Use `machine.Pin.irq` on both RISING and FALLING edges + `utime.ticks_us()` for pulse width measurement. This runs in a dedicated `_thread` thread.

**Rationale**: The IR_RX_PIN (GPIO4) connects to a **TSOP demodulator** which outputs an already-demodulated digital signal (active-low when carrier detected). The RMT receive mode in MicroPython v1.24.0 on ESP32-S3 has a known limitation: the Python-level `wait_done()` / `read_pulses()` API blocks until the RMT DMA buffer is full or a timeout occurs, which prevents real-time multi-frame reassembly. A GPIO IRQ approach:

1. Fires an ISR on every edge — records `(edge_type, ticks_us)`.
2. A second thread (not an ISR) drains the edge queue and decodes NEC timing.
3. This separates interrupt latency (ISR, must be fast) from NEC logic (thread, can block safely).

```python
import machine, utime, _thread

class NECRX:
    BIT_THRESHOLD_US = 1000  # < 1000 µs = bit 0, > 1000 µs = bit 1

    def __init__(self, pin_num, on_frame):
        self._pin = machine.Pin(pin_num, machine.Pin.IN)
        self._on_frame = on_frame   # callback(address, command)
        self._edges = []            # [(level, ticks_us)] — filled by ISR
        self._last_us = 0

        self._pin.irq(self._isr, machine.Pin.IRQ_RISING | machine.Pin.IRQ_FALLING,
                      hard=True)

    def _isr(self, pin):
        now = utime.ticks_us()
        self._edges.append((pin.value(), now))

    def decode_loop(self):
        """Call from a background thread. Drains edge queue and decodes NEC."""
        state = 'idle'
        bits  = []
        last_fall = 0
        while True:
            if self._edges:
                level, t = self._edges.pop(0)
                dt = utime.ticks_diff(t, self._last_us)
                self._last_us = t
                # NEC decode state machine (leader + 32 bits)
                # ... (detailed in ir_nec.py)
            utime.sleep_ms(1)
```

**Alternatives considered**:
- `esp32.RMT` receive: Simpler API but blocks per-frame; multi-frame reassembly requires polling a buffer. MicroPython v1.24.0 RMT receive does not expose per-frame callbacks, making the 500 ms timeout guard between UID bytes awkward to implement. **Acceptable but more complex than GPIO IRQ for multi-frame use case**.
- Single-thread polling (`Pin.value()` in a tight loop): Prevents the main loop from running, violates FR-013. **Rejected**.

**Thread safety**: The `_edges` list is modified in an ISR and consumed in a thread. MicroPython ISRs on ESP32 are micropython task preemptive; `list.append()` and `list.pop(0)` are individually atomic at the MicroPython level. For safety, a fixed-size ring buffer (using `bytearray`) is preferred in the final `ir_nec.py` implementation to avoid heap allocation in the ISR.

---

## Decision 3: XBM → Python bytes literal conversion

**Question**: How should `graphics.h` PROGMEM arrays be converted to `graphics.py` Python bytes?

**Decision**: Manual one-time conversion via a short Python script run during development. Output is a `graphics.py` file with named `bytes` literals checked into the repo.

**Rationale**: The conversion is a one-time operation. The PROGMEM arrays in `graphics.h` are already in the XBM byte format (LSB-first, row-major). The conversion is:

```python
# converter run once on dev machine (not part of badge runtime)
import re

def progmem_to_bytes(c_array_literal: str) -> bytes:
    hex_values = re.findall(r'0x[0-9a-fA-F]+', c_array_literal)
    return bytes(int(v, 16) for v in hex_values)
```

The resulting `graphics.py` contains:

```python
# graphics.py — XBM bitmaps translated from firmware/Firmware-0306/graphics.h
# All arrays are 1024 bytes (128×64 pixels, MONO_HLSB format) unless noted.

GRAPHICS_BASE = bytes([0x00, 0x00, ...])     # 1024 bytes
MOCK_QR       = bytes([...])                 # 1024 bytes
MOCK_NAMETAG  = bytes([...])                 # 1024 bytes

# Arrow sprites (small, used as OLED overlays)
DOWN_ARROW_FILLED = bytes([0x10, 0x00, 0x10, 0x00, 0x7c, 0x00,
                            0x38, 0x00, 0x10, 0x00, 0x00, 0x00])  # 9×6
DOWN_ARROW        = bytes([0x10, 0x00, 0x10, 0x00, 0x7c, 0x00,
                            0x38, 0x00, 0x10, 0x00, 0x00, 0x00])  # 9×6
UP_ARROW_FILLED   = bytes([0xef, 0x01, 0xc7, 0x01, 0x83, 0x01,
                            0xef, 0x01, 0xef, 0x01, 0xff, 0x01])  # 9×6
UP_ARROW          = bytes([0x10, 0x00, 0x38, 0x00, 0x7c, 0x00,
                            0x10, 0x00, 0x10, 0x00, 0x00, 0x00])  # 9×6
```

**Display rendering**: MicroPython `framebuf.FrameBuffer` with `framebuf.MONO_HLSB` is the correct format. XBM is LSB-first which matches `MONO_HLSB`. No bit-reversal needed.

**Alternatives considered**:
- Run-time XBM parsing (parse hex text): Slower and wastes RAM. The `graphics.h` arrays are already in binary; including them as bytes literals is zero-runtime-overhead. **Rejected**.
- Storing as `.bin` files on VFS: Adds flash.sh complexity and VFS file-open overhead at boot. Bytes literals in a frozen module would be better — but for BYPASS mode (development only), VFS is fine. **Acceptable but not chosen** — the spec says graphics.py is a VFS file (per FR-003), so bytes literal in a Python file is the right approach.

---

## Decision 4: Threading model for IR RX

**Question**: How should IR RX concurrency be structured (MicroPython threading options)?

**Decision**: `_thread.start_new_thread(ir_rx_loop, ())` launched from `main.py` before entering the main event loop. The IR RX loop runs on Core 0 (same as the main thread) with a 1 ms sleep yielding back to the MicroPython scheduler.

**Rationale**:
- MicroPython's `_thread` is cooperative on single-core configurations but preemptive on ESP32's dual-core (Core 0 / Core 1). The main loop runs on Core 1 by default; the IR thread can run on Core 0.
- This mirrors the Arduino `xTaskCreatePinnedToCore(irReceiveTask, ..., 0)` pattern exactly.
- Shared state between threads: a Python list `_received_uids` protected by a `_thread.allocate_lock()` mutex.

**Thread structure**:
```python
import _thread

_rx_lock = _thread.allocate_lock()
_received_uids = []   # protected by _rx_lock

def _ir_rx_loop(rx):
    """Runs on background thread. rx is a NECRX instance."""
    rx.decode_loop()   # loops forever; calls _on_frame callback

def start_ir_rx(ir_rx_pin):
    def on_frame(addr, cmd):
        if addr != 0x42:
            return
        # accumulate 6 bytes → uid string
        ...
        with _rx_lock:
            _received_uids.append(uid_hex)

    rx = NECRX(ir_rx_pin, on_frame)
    _thread.start_new_thread(_ir_rx_loop, (rx,))
```

**Alternatives considered**:
- `asyncio` (uasyncio): MicroPython's asyncio does not support true parallelism; a long IR decode loop would block the event loop. **Rejected**.
- Polling IR state in the main loop: Fails FR-013 ("run concurrently"). **Rejected**.

---

## Decision 5: `machine.unique_id()` format on ESP32-S3

**Question**: What does `machine.unique_id()` return on ESP32-S3-MINI-1, and is it always 6 bytes?

**Decision**: On ESP32-S3, `machine.unique_id()` returns 6 bytes derived from the MAC address base (same as `esp_efuse_mac_get_default`). Always 6 bytes on this chip. Badge ID = `''.join(f'{b:02x}' for b in machine.unique_id())` → 12 lowercase hex characters.

**Safety**: The spec says to zero-pad if fewer than 6 bytes are returned. Implement as:
```python
uid_bytes = machine.unique_id()
uid_hex = ''.join(f'{b:02x}' for b in uid_bytes).ljust(12, '0')[:12]
```

**Rationale**: Consistent with Firmware-0306 which reads `ESP_EFUSE_OPTIONAL_UNIQUE_ID` (a different eFuse field — 128-bit chip ID). However, since badge_crypto is out of scope, `machine.unique_id()` is used as a reasonable 6-byte device identifier available without a C module. The display messages show the 12-char hex ID. This is sufficient for the port's scope (IR pairing, display, BYPASS mode); HMAC-authenticated requests require the proper UUID from NVS, which is deferred to the badge_crypto spec.

---

## Decision 6: Joystick ADC normalization

**Question**: How to normalize the 12-bit ADC joystick readings to ±1.0?

**Decision**: `machine.ADC(pin, atten=machine.ADC.ATTN_11DB)` gives 0–4095. Center is ~2048. Normalize: `norm = (raw - 2048) / 2048.0`, then clamp to circle: if `sqrt(nx²+ny²) > 1.0`, scale down.

```python
import machine, math

joy_x = machine.ADC(machine.Pin(JOY_X_PIN), atten=machine.ADC.ATTN_11DB)
joy_y = machine.ADC(machine.Pin(JOY_Y_PIN), atten=machine.ADC.ATTN_11DB)

def read_joy():
    nx = (joy_x.read() - 2048) / 2048.0
    ny = (joy_y.read() - 2048) / 2048.0
    dist = math.sqrt(nx*nx + ny*ny)
    if dist > 1.0:
        nx /= dist
        ny /= dist
    return nx, ny
```

The display maps (nx, ny) to a 3×3 dot within a 6-pixel-radius circle centered at (100, 53) — matching the Arduino `JOY_CIRCLE_CX=100`, `JOY_CIRCLE_CY=53`, `JOY_CIRCLE_R=6`.

**Attenuation**: `ATTN_11DB` extends range to ~3.3V (full rail), needed if joystick rail voltage is 3.3V. If joystick center reads off-center due to component tolerances, the ±2048 normalization compensates adequately for display purposes (no calibration procedure required for the conference use case).

---

## Decision 7: BYPASS mode structure

**Question**: How should BYPASS mode be structured across boot.py / main.py?

**Decision**: `BYPASS = True/False` in `config.py` (VFS, not frozen). Boot.py and main.py both import it. When `BYPASS = True`:
- WiFi connect: skip, display "Connected (bypass)" after `BYPASS_DELAY_MS` ms
- NTP sync: skip
- QR fetch: skip, display `graphics.MOCK_QR` for `QR_DISPLAY_MS` ms
- Nametag fetch: skip, display `graphics.MOCK_NAMETAG`
- Badge ID: from `machine.unique_id()` as normal (still works offline)
- HTTP requests: skip all

This matches Firmware-0306's `if (BYPASS) { delay(BYPASS_DELAY_MS); ... }` pattern.

**Rationale**: BYPASS mode must be achievable without a network, server, or badge_crypto enrollment. Using a flag in config.py (VFS-resident) means the developer can toggle it without rebuilding firmware.

---

## Resolved unknowns summary

| Unknown | Resolution |
|---|---|
| NEC TX implementation | `esp32.RMT` with `tx_carrier` for 38 kHz modulation |
| NEC RX implementation | GPIO `machine.Pin.irq` + `_thread`, ring buffer for ISR safety |
| XBM conversion | One-time Python script → `graphics.py` bytes literals |
| IR concurrency | `_thread.start_new_thread` on Core 0; `allocate_lock()` for shared UID list |
| Badge ID source | `machine.unique_id()` → 6 bytes → 12-char hex, zero-padded if short |
| Joystick normalization | `machine.ADC` ATTN_11DB, 0–4095 → ±1.0, circle clamp |
| BYPASS mode | `config.py` flag, skips all network calls, uses `graphics.py` mock data |
| Board definition source | Adapt from `shy-micropython-build` patterns; re-verify all pins against constitution table |

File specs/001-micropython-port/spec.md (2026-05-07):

# Feature Specification: MicroPython Port for Temporal Badge DELTA

**Feature Branch**: `001-micropython-port`
**Created**: 2026-03-10
**Status**: Draft
**Input**: User description: "Convert the existing Arduino firmware (firmware/Firmware-0306/Firmware-0306.ino) to a MicroPython build targeting the Temporal Badge DELTA (ESP32-S3-MINI-1, XIAO form factor)."

## User Scenarios & Testing *(mandatory)*

### User Story 1 - Developer builds and flashes the badge (Priority: P1)

A firmware developer clones the repo, runs `build.sh`, then `flash.sh`, and ends up with a working badge that boots, connects to WiFi (or enters BYPASS mode), displays the splash graphic on the OLED, and responds to USB serial REPL commands.

**Why this priority**: This is the gate for all other work. Nothing else is testable until the badge is flashed and reachable over serial.

**Independent Test**: Run `build.sh`, then `flash.sh` on a freshly cloned repo. Connect to `/dev/cu.usbmodem*` with `screen` or `mpremote`. Verify the REPL prompt appears and `import machine` succeeds.

**Acceptance Scenarios**:

1. **Given** a clean checkout with correct host toolchain, **When** `build.sh` is run, **Then** `firmware-conference.bin` is produced with no errors and the script exits 0.
2. **Given** a badge connected via USB-C, **When** `flash.sh` is run, **Then** the device is erased, firmware written, VFS files copied, and after reboot a USB serial REPL is reachable at `/dev/cu.usbmodem*`.

---

### User Story 2 - Badge boots with full display sequence (Priority: P2)

On power-up the badge performs the same visual boot sequence as the Arduino reference: splash graphic, welcome message with badge ID, WiFi connect, QR code display for 10 seconds, nametag fetch, then main interactive display.

**Why this priority**: Preserves the conference attendee experience. Behaviorally identical output to the Arduino reference is the acceptance bar for the port.

**Independent Test**: Flash badge with `BYPASS = True` in 1`config.py`. Observe OLED: should cycle splash → welcome text → "Connected (bypass)" → QR mock bitmap for 10 s → nametag mock bitmap → main UI with joystick/button overlays.

**Acceptance Scenarios**:

1. **Given** `BYPASS = True`, **When** badge powers on, **Then** OLED shows splash with Temporal wordmark, then welcome text including the 12-hex-char badge ID derived from `machine.unique_id()`.
2. **Given** `BYPASS = True`, **When** boot sequence reaches QR step, **Then** mock QR bitmap (converted from `graphics.h` PROGMEM) fills the 128×64 display for 10 seconds.
3. **Given** `BYPASS = True`, **When** boot completes, **Then** main UI renders: base graphic, two text lines, joystick dot, tilt indicator, IR TX/RX arrows, and button state dots.
4. **Given** live WiFi credentials in `creds.py` and `BYPASS = False`, **When** badge powers on, **Then** WiFi connects within 5 seconds and NTP syncs before continuing boot.

---

### User Story 3 - IR badge-to-badge pairing (Priority: P3)

Pressing BTN_UP transmits the badge's 6-byte ID over IR (NEC protocol, address 0x42). A second badge in receive mode picks up the 6 bytes, reassembles the ID, and displays it on screen.

**Why this priority**: Core social/game mechanic. Depends on P1 and P2 being stable first.

**Independent Test**: Two flashed badges facing each other. Press BTN_UP on badge A. Badge B screen should show "RX UID: <12-char hex>". Badge A screen should show "IR TX: sent!".

**Acceptance Scenarios**:

1. **Given** two badges in range, **When** BTN_UP is pressed on badge A, **Then** badge A displays "IR TX: sending UID..." then "IR TX: sent!", and badge B displays each of 6 received bytes with a counter "UID 1/6"…"UID 6/6", then "RX UID: <hex>".
2. **Given** IR receive is listening, **When** a non-badge NEC signal is received, **Then** the decoded protocol name and command byte are displayed for 1 second, then display returns to "IR: listening...".
3. **Given** a partial UID is being received, **When** no further bytes arrive for 500 ms, **Then** the partial buffer is discarded and the display returns to "IR: listening...".

---

### User Story 4 - Button, joystick, and tilt inputs (Priority: P4)

All physical inputs work correctly: buttons debounced at 40 ms, joystick polled at 50 ms with normalized clamped output, tilt switch debounced at 300 ms.

**Why this priority**: Input peripherals are test-verifiable in isolation; needed before any interactive feature builds on them.

**Independent Test**: In main loop, observe screen indicators. Press each button — the corresponding dot should appear. Move joystick — the small square should track. Tilt badge — tilt indicator rect changes position.

**Acceptance Scenarios**:

1. **Given** main UI is displayed, **When** BTN_UP/DOWN/LEFT/RIGHT is held, **Then** the corresponding indicator dot is filled; releasing it clears the dot.
2. **Given** joystick at center, **When** joystick is pushed to an extreme, **Then** the position dot moves to the edge of the 6-pixel-radius circle and does not exceed it.
3. **Given** badge is upright, **When** badge is tilted past threshold, **Then** tilt indicator moves after 300 ms debounce with no false triggers during normal handling.

---

### Edge Cases

- What happens when WiFi credentials are present but the network is unreachable? → Boot continues after `WIFI_TIMEOUT_MS` (5 s); badge displays failure message and halts (mirrors Arduino behavior).
- What happens when the QR fetch fails (HTTP non-200 or network error)? → "QR unavailable, continuing..." message for 2 s; transitions directly to main loop.
- What happens when `machine.unique_id()` returns fewer than 6 bytes? → Pad to 6 bytes; badge ID is always 12 hex chars.
- What happens when IR TX is triggered while IR RX is active? → RX is temporarily suspended during the 6-frame TX burst, then re-enabled.

## Requirements *(mandatory)*

### Functional Requirements

- **FR-001**: The firmware MUST be buildable from source using `build.sh` with MicroPython v1.24.0 and ESP-IDF v5.2.3, producing a single `.bin` file flashable to the badge hardware.
- **FR-002**: The build system MUST define a custom board `TEMPORAL_BADGE_DELTA` with the exact GPIO assignments from `Firmware-0306`: I2C SDA=GPIO5, SCL=GPIO6; IR TX=GPIO3, RX=GPIO4; BTN_UP=GPIO8, DOWN=GPIO9, LEFT=GPIO10, RIGHT=GPIO11; JOY_X=GPIO1, JOY_Y=GPIO2; TILT=GPIO7.
- **FR-003**: `flash.sh` MUST erase flash, write the firmware binary, and copy all VFS Python files (`config.py`, `boot.py`, `main.py`, `ir_nec.py`, `badge_sdk.py`, `graphics.py`) to the device filesystem via `mpremote`.
- **FR-004**: After flashing, a USB serial REPL MUST be accessible at `/dev/cu.usbmodem*` without additional host configuration.
- **FR-005**: The badge MUST derive its ID from `machine.unique_id()` (6 bytes, hex-encoded to 12 lowercase characters) and use this ID throughout boot messages and IR transmission.
- **FR-006**: `config.py` MUST define all GPIO pin numbers, timing constants (`WIFI_TIMEOUT_MS`, `QR_DISPLAY_MS`, `BYPASS_DELAY_MS`, `TILT_SHOWS_BADGE`), and a `BYPASS` flag; it MUST NOT contain WiFi credentials or server URLs.
- **FR-007**: WiFi credentials (`SSID`, `PASS`) and `SERVER_URL` MUST be read from a VFS-resident `creds.py`; this file MUST be listed in `.gitignore` and deployed via `mpremote fs cp`.
- **FR-008**: When `BYPASS = True`, `boot.py`/`main.py` MUST skip live network calls and substitute mock XBM bitmaps (Python `bytes` literals translated from `graphics.h` PROGMEM arrays) for QR and nametag images.
- **FR-009**: `boot.py` MUST connect to WiFi (or simulate via BYPASS), optionally sync NTP, and display status messages on the SSD1309 OLED during boot.
- **FR-010**: `main.py` MUST replicate the full Arduino boot sequence: welcome message → WiFi connect → QR display (10 s) → nametag fetch → main interactive loop.
- **FR-011**: `main.py` MUST poll buttons (40 ms debounce), joystick (50 ms interval, 12-bit ADC, normalized ±1.0 clamped to circle radius), and tilt switch (300 ms debounce) on every main loop iteration.
- **FR-012**: `ir_nec.py` MUST implement NEC IR TX and RX using the ESP32 RMT peripheral; TX sends 6 NEC frames (address 0x42, one badge-ID byte per frame, 50 ms inter-frame gap); RX reassembles 6 consecutive frames with address 0x42 into a badge ID.
- **FR-013**: IR RX MUST run concurrently with the main loop (via a thread or equivalent); a partial UID buffer MUST be discarded after 500 ms of silence.
- **FR-014**: `badge_sdk.py` MUST provide a `Badge` class with methods: `uid()` → 12-char hex string, `display(line1, line2)`, `ping(target_uid)` → IR transmit, `pings()` → list of received UIDs since last call; no HMAC or eFuse usage.
- **FR-015**: The `boards/TEMPORAL_BADGE_DELTA/` board definition MUST freeze the `ssd1306` and `urequests` modules; it MUST NOT reference any files from `firmware/shy-micropython-build/`.
- **FR-016**: The build MUST enable USB-CDC for the serial REPL; Bluetooth support is NOT required for this spec.

### Key Entities

- **Badge ID**: 12-character lowercase hex string derived from `machine.unique_id()` (6 MAC bytes). Stable per device. Used in display messages, IR transmission, and future HTTP requests.
- **XBM Bitmap**: 128×64 monochrome bitmap (1024 bytes) displayed on the SSD1309. Sourced from server (live mode) or from `graphics.py` mock arrays (BYPASS mode).
- **VFS Python Files**: Files stored on the device filesystem and copied via `mpremote`: `config.py`, `boot.py`, `main.py`, `ir_nec.py`, `badge_sdk.py`, `graphics.py`, and `creds.py` (gitignored).
- **Board Definition**: MicroPython board directory (`boards/TEMPORAL_BADGE_DELTA/`) containing `mpconfigboard.h`, `mpconfigboard.cmake`, `sdkconfig.board`, `partitions.csv`, `manifest.py`, `pins.csv`.

## Success Criteria *(mandatory)*

### Measurable Outcomes

- **SC-001**: `build.sh` completes without errors on macOS (Apple Silicon) with the pinned toolchain and produces a flashable `.bin` in under 20 minutes.
- **SC-002**: After running `flash.sh`, the badge boots and a USB serial REPL is reachable within 30 seconds of device reset.
- **SC-003**: In BYPASS mode, the full boot sequence (splash → welcome → simulated WiFi → QR → nametag → main loop) completes without crashing, observable end-to-end via OLED and serial output.
- **SC-004**: Pressing BTN_UP on one badge causes a second badge to display the sender's badge ID within 2 seconds, verified by reading the receiver's OLED.
- **SC-005**: All four buttons, joystick, and tilt switch produce correct visual feedback in the main UI with no missed events during manual exercise of each input.
- **SC-006**: The firmware binary fits within the 4 MB app partition defined in `partitions.csv`.

## Assumptions

- Host build machine is macOS (Apple Silicon). `build.sh` applies `CFLAGS_EXTRA="-Wno-gnu-folding-constant"` for Clang 15+ compatibility; this is proven to work.
- `machine.unique_id()` on ESP32-S3 returns exactly 6 bytes (the MAC address base). If fewer bytes are returned, the badge ID is zero-padded to 12 hex chars.
- The SSD1309 OLED at I2C address 0x3C is compatible with the `ssd1306` MicroPython driver (same I2C protocol, different controller IC).
- NTP sync requires WiFi; in BYPASS mode it is skipped without error.
- A two-badge IR pairing test requires two physical DELTA rev badges; single-badge testing covers TX-only behavior via serial logging.
- `TILT_SHOWS_BADGE` defaults to `False` (matching Arduino reference), so tilt only changes the indicator widget; it does not switch to full nametag display mode.
- Mock XBM bitmaps in `graphics.py` are Python `bytes` literals directly translated from the PROGMEM byte arrays in `graphics.h` — no format conversion needed.

## Out of Scope

- `badge_crypto` C extension module (eFuse HMAC peripheral operations)
- eFuse key burning or badge enrollment workflow
- HMAC-signed HTTP requests to the backend
- Backend API changes (`registrationScanner/`)
- OTA firmware update
- BLE functionality

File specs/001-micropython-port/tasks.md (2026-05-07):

---

description: "Task list for MicroPython Port — Temporal Badge DELTA"
---

# Tasks: MicroPython Port for Temporal Badge DELTA

**Input**: Design documents from `/specs/001-micropython-port/`
**Prerequisites**: plan.md ✓, spec.md ✓, research.md ✓, data-model.md ✓, contracts/badge_sdk.md ✓, quickstart.md ✓

**Tests**: Manual only per project constitution. No automated test runner. Verification via flash → USB REPL → OLED observation → two-badge IR test.

**Organization**: Tasks grouped by user story to enable independent implementation and manual verification of each story.

## Format: `[ID] [P?] [Story?] Description`

- **[P]**: Can run in parallel (different files, no dependencies on incomplete tasks)
- **[Story]**: Which user story this task belongs to (US1, US2, US3, US4)
- All paths relative to repository root

---

## Phase 1: Setup (Shared Infrastructure)

**Purpose**: Create the `firmware/micropython-build/` directory tree and protect sensitive files

- [X] T001 Create `firmware/micropython-build/` directory tree: `boards/TEMPORAL_BADGE_DELTA/`, `modules/.gitkeep` (keeps modules dir in git for future badge_crypto C extension)
- [X] T002 [P] Add `firmware/micropython-build/creds.py` to `.gitignore` (WiFi SSID/PASS + SERVER_URL — never commit)

---

## Phase 2: Foundational (Board Definition — Blocking Prerequisites)

**Purpose**: Board definition files that MUST exist before `build.sh` can produce any firmware binary. All files are independent of each other.

**⚠️ CRITICAL**: No user story work can begin until this phase is complete — the board definition is the prerequisite for the MicroPython build system.

- [X] T003 [P] Create `firmware/micropython-build/boards/TEMPORAL_BADGE_DELTA/mpconfigboard.h`: define `MICROPY_HW_BOARD_NAME "TEMPORAL_BADGE_DELTA"`, `MICROPY_HW_MCU_NAME "ESP32S3"`, enable USB-CDC (`MICROPY_HW_USB_CDC 1`), disable Bluetooth stack (`MICROPY_PY_BLUETOOTH 0`), disable BLE (`MICROPY_BLUETOOTH_NIMBLE 0`)
- [X] T004 [P] Create `firmware/micropython-build/boards/TEMPORAL_BADGE_DELTA/mpconfigboard.cmake`: set IDF target `esp32s3`, sdkconfig layer order `base → usb → ble → sdkconfig.board`, set `MICROPY_FROZEN_MANIFEST` to `manifest.py`, do NOT set `USER_C_MODULES` here (passed via build.sh command line)
- [X] T005 [P] Create `firmware/micropython-build/boards/TEMPORAL_BADGE_DELTA/sdkconfig.board`: enable 8 MB QIO flash (`CONFIG_ESPTOOLPY_FLASHSIZE_8MB=y`, `CONFIG_ESPTOOLPY_FLASHMODE_QIO=y`), enable SPIRAM (`CONFIG_SPIRAM=y`), enable HMAC peripheral (`CONFIG_EFUSE_HMAC=y`), set custom partitions path (`CONFIG_PARTITION_TABLE_CUSTOM=y`, `CONFIG_PARTITION_TABLE_CUSTOM_FILENAME="partitions.csv"`)
- [X] T006 [P] Create `firmware/micropython-build/boards/TEMPORAL_BADGE_DELTA/partitions.csv`: NVS 24 KB at 0x9000, factory app 4 MB at 0x10000, vfs 4 MB following factory partition (no header row, standard ESP-IDF CSV format)
- [X] T007 [P] Create `firmware/micropython-build/boards/TEMPORAL_BADGE_DELTA/manifest.py`: freeze `ssd1306` from `$(MPY_LIB_DIR)/micropython/drivers/display/ssd1306`, freeze `urequests` from `$(MPY_LIB_DIR)/micropython/urequests`; do NOT reference any files from `firmware/shy-micropython-build/`
- [X] T008 [P] Create `firmware/micropython-build/boards/TEMPORAL_BADGE_DELTA/pins.csv`: no header row; `BOARD_NAME,GPIOx` format; include all 11 pins from constitution: I2C_SDA=GPIO5, I2C_SCL=GPIO6, IR_TX=GPIO3, IR_RX=GPIO4, BTN_UP=GPIO8, BTN_DOWN=GPIO9, BTN_LEFT=GPIO10, BTN_RIGHT=GPIO11, JOY_X=GPIO1, JOY_Y=GPIO2, TILT=GPIO7
- [X] T009 Create `firmware/micropython-build/config.py`: define all GPIO pin constants (`I2C_SDA=5`, `I2C_SCL=6`, `I2C_FREQ=400000`, `BTN_UP=8`, `BTN_DOWN=9`, `BTN_LEFT=10`, `BTN_RIGHT=11`, `JOY_X_PIN=1`, `JOY_Y_PIN=2`, `TILT_PIN=7`, `IR_TX_PIN=3`, `IR_RX_PIN=4`), timing constants (`WIFI_TIMEOUT_MS=5000`, `QR_DISPLAY_MS=10000`, `BYPASS_DELAY_MS=3000`), `TILT_SHOWS_BADGE=False`, `BYPASS=True`; NO WiFi credentials or SERVER_URL

**Checkpoint**: Board definition complete — `firmware/micropython-build/` is a valid MicroPython board directory. User story implementation can now begin.

---

## Phase 3: User Story 1 — Developer Builds and Flashes (Priority: P1) 🎯 MVP

**Goal**: `build.sh` produces a flashable firmware binary; `flash.sh` erases, flashes, and copies VFS files; USB serial REPL is accessible after reboot.

**Independent Test**: Run `./build.sh` → verify `firmware-conference.bin` ≤ 4 MB, exit 0. Connect badge via USB-C → `./flash.sh` → `mpremote connect /dev/cu.usbmodem*` → REPL prompt appears → `import machine` succeeds without error.

### Implementation for User Story 1

- [X] T010 [US1] Create `firmware/micropython-build/build.sh`: clone or use cached MicroPython v1.24.0 + ESP-IDF v5.2.3; set `CFLAGS_EXTRA="-Wno-gnu-folding-constant"` for Apple Silicon Clang 15+; build target `TEMPORAL_BADGE_DELTA` with `idf.py -DMICROPY_BOARD=TEMPORAL_BADGE_DELTA build`; output binary as `firmware-conference.bin`; print file size and fail with non-zero exit if > 4 MB
- [X] T011 [P] [US1] Create `firmware/micropython-build/flash.sh`: detect `/dev/cu.usbmodem*` port; `esptool.py erase_flash`; `esptool.py write_flash 0x0 firmware-conference.bin`; `mpremote fs cp config.py :config.py` for each VFS file (`config.py`, `boot.py`, `main.py`, `ir_nec.py`, `badge_sdk.py`, `graphics.py`); copy `creds.py` only if it exists; `mpremote reset`
- [X] T012 [P] [US1] Create `firmware/micropython-build/boot.py` (stub): try/except import of `creds` (set `BYPASS=True` in `config` namespace if `ImportError`); import `config`; initialize SSD1309 I2C display (`ssd1306.SSD1306_I2C(128, 64, machine.I2C(0, sda=machine.Pin(config.I2C_SDA), scl=machine.Pin(config.I2C_SCL), freq=config.I2C_FREQ))`); display "Temporal / Badge DELTA / Starting..." on OLED; no network calls in this stub
- [X] T013 [P] [US1] Create `firmware/micropython-build/main.py` (stub): `import config, utime`; compute `badge_uid` from `machine.unique_id()` with zero-padding to 12 hex chars (`''.join(f'{b:02x}' for b in machine.unique_id()).ljust(12,'0')[:12]`); infinite loop with `utime.sleep_ms(50)`
- [X] T014 [P] [US1] Create `firmware/micropython-build/badge_sdk.py` (stub): `Badge` class with `__init__` that reads `machine.unique_id()` and stores `self._uid`; `uid` property returning 12-char zero-padded hex string; `display_text(line1, line2)` raising `NotImplementedError`; `ping(target_uid)` raising `NotImplementedError`; `pings()` returning empty list
- [X] T015 [P] [US1] Create `firmware/micropython-build/ir_nec.py` (stub): `NECTX` class with `__init__(self, pin_num)` and `send(self, address, command)` raising `NotImplementedError`; `NECRX` class with `__init__(self, pin_num, on_frame)` and `decode_loop(self)` raising `NotImplementedError`
- [X] T016 [P] [US1] Create `firmware/micropython-build/graphics.py` (stub): `GRAPHICS_BASE = bytes(1024)`, `MOCK_QR = bytes(1024)`, `MOCK_NAMETAG = bytes(1024)`, arrow sprites as zero-filled bytes (`DOWN_ARROW_FILLED = bytes(12)`, `DOWN_ARROW = bytes(12)`, `UP_ARROW_FILLED = bytes(12)`, `UP_ARROW = bytes(12)`)

**Checkpoint**: `build.sh` exits 0, firmware-conference.bin is ≤ 4 MB. `flash.sh` succeeds. USB REPL is accessible and `import machine` works. User Story 1 is independently verified.

---

## Phase 4: User Story 2 — Boot Display Sequence (Priority: P2)

**Goal**: Full Arduino-parity boot sequence visible on OLED — splash → welcome text with badge ID → WiFi/BYPASS status → QR bitmap 10 s → nametag bitmap → main interactive display.

**Independent Test**: Set `BYPASS = True` in `firmware/micropython-build/config.py`. Flash badge. Observe OLED: splash Temporal wordmark → welcome text with 12-char hex badge ID → "Connected (bypass)" → mock QR bitmap for 10 s → mock nametag bitmap → main UI with joystick dot, tilt indicator, button dots. Serial REPL shows boot log.

### Implementation for User Story 2

- [X] T017 [US2] Replace `firmware/micropython-build/boot.py` stub with full implementation: BYPASS=True path: delay `BYPASS_DELAY_MS`, display "Connected (bypass)"; BYPASS=False path: `network.WLAN(network.STA_IF)`, connect with `WIFI_TIMEOUT_MS` timeout, on failure display "WiFi failed" and `raise SystemExit`; on success display "Connected to \<SSID\>"; NTP sync via `ntptime.settime()` (BYPASS skips); fetch QR XBM from `GET \<SERVER_URL\>/api/v1/badge/\<badge_uid\>/qr.xbm` (BYPASS uses `graphics.MOCK_QR`); display QR framebuf for `QR_DISPLAY_MS`; on HTTP failure display "QR unavailable, continuing..." for 2 s
- [X] T018 [P] [US2] Replace `firmware/micropython-build/graphics.py` stub with full conversion: parse `firmware/Firmware-0306/graphics.h` PROGMEM arrays using regex (`re.findall(r'0x[0-9a-fA-F]+', ...)`) on dev machine; output `GRAPHICS_BASE` (1024 bytes), `MOCK_QR` (1024 bytes), `MOCK_NAMETAG` (1024 bytes), `DOWN_ARROW_FILLED` (12 bytes), `DOWN_ARROW` (12 bytes), `UP_ARROW_FILLED` (12 bytes), `UP_ARROW` (12 bytes) as Python bytes literals; validate each 128×64 bitmap is exactly 1024 bytes
- [X] T019 [US2] Replace `firmware/micropython-build/main.py` stub with full display entry: fetch nametag XBM from `GET \<SERVER_URL\>/api/v1/badge/\<badge_uid\>/info` (BYPASS uses `graphics.MOCK_NAMETAG`); render nametag via `framebuf.FrameBuffer(bytearray(xbm[:1024]), 128, 64, framebuf.MONO_HLSB)`; implement `_parse_xbm_response(text)` to extract bytes from XBM text format; implement mode constants `MODE_BOOT=0`, `MODE_QR=1`, `MODE_MAIN=2`; `current_mode` starts at `MODE_MAIN` after boot; infinite main loop placeholder calling `utime.sleep_ms(50)`
- [X] T020 [US2] Update `firmware/micropython-build/badge_sdk.py`: replace stub with working `display` property returning `ssd1306.SSD1306_I2C` instance (128×64, I2C from `config.I2C_SDA/SCL/FREQ`); implement `display_text(line1, line2)` — `fill(0)`, `text(line1[:16], 0, 0)`, `text(line2[:16], 0, 16)`, `show()`; `Badge.__init__` must NOT crash when called before WiFi connects

**Checkpoint**: In BYPASS mode, full boot sequence runs without crashing. OLED shows all expected screens in order. Verifiable via OLED observation alone. User Story 2 independently verified.

---

## Phase 5: User Story 3 — IR Badge-to-Badge Pairing (Priority: P3)

**Goal**: BTN_UP on badge A transmits the 6-byte badge ID as 6 NEC frames (address 0x42). Badge B receives, reassembles, and displays the sender's UID. Non-badge NEC signals display protocol info for 1 s.

**Independent Test**: Two flashed badges facing each other at < 2 m. Press BTN_UP on badge A. Badge A OLED: "IR TX: sending UID..." → "IR TX: sent!". Badge B OLED: "IR: UID 1/6" through "IR: UID 6/6" → "RX UID: \<12-char hex\>". Single-badge test: press BTN_UP, confirm serial log shows TX attempt.

### Implementation for User Story 3

- [X] T021 [US3] Replace `firmware/micropython-build/ir_nec.py` stub with `NECTX` full implementation: `esp32.RMT(0, pin=machine.Pin(pin_num), clock_div=80, tx_carrier=(38000, 50, 1), idle_level=False)`; `_encode_frame(address, command)` → flat tuple of (burst_µs, space_µs) pairs: leader 9000/4500, 32 data bits (BIT_BURST=562, BIT_0_SPACE=562, BIT_1_SPACE=1688), end burst 562, trailing 0; `send(address, command)` calls `self._rmt.write_pulses(...)` then `self._rmt.wait_done(timeout=100)`
- [X] T022 [US3] Replace `firmware/micropython-build/ir_nec.py` `NECRX` stub with full implementation: fixed-size ring buffer (bytearray, length 256) for ISR-safe edge recording; `machine.Pin(pin_num, machine.Pin.IN).irq(self._isr, machine.Pin.IRQ_RISING | machine.Pin.IRQ_FALLING, hard=True)`; `_isr` records `(pin.value(), utime.ticks_us())` into ring buffer; `decode_loop()` runs in background thread, drains ring buffer, implements NEC state machine (idle → leader → 32 bits → frame complete), calls `on_frame(address, command)` on successful decode (depends on T021 for class structure)
- [X] T023 [US3] Add IR UID TX function to `firmware/micropython-build/main.py`: `irTransmitUID(tx, badge_uid_hex)` — decode hex to 6 bytes, iterate 6 bytes calling `tx.send(0x42, byte)` with `utime.sleep_ms(50)` inter-frame gap; update display "IR TX: sending UID..." before TX, "IR TX: sent!" after; temporarily disable RX thread during TX burst by setting a shared `_tx_active` flag checked in decode_loop
- [X] T024 [US3] Add IR RX thread to `firmware/micropython-build/main.py`: allocate `_rx_lock = _thread.allocate_lock()`, `_received_uids = []`; `on_frame(addr, cmd)` callback — if `addr == 0x42`: append `cmd` to `_rx_buf`, update `_last_byte_ms`; if `len(_rx_buf) == 6`: assemble hex string, append to `_received_uids` under `_rx_lock`, clear `_rx_buf`; if `addr != 0x42`: display "IR: \<addr hex\>" for 1 s; implement 500 ms partial buffer discard in decode loop; launch with `_thread.start_new_thread(_ir_rx_loop, (rx,))` before main loop (depends on T022)
- [X] T025 [P] [US3] Update `firmware/micropython-build/badge_sdk.py`: implement `ping(target_uid)` — validate `len(target_uid) == 12` and all hex chars (raise `ValueError` otherwise); decode to bytes; transmit 6 NEC frames via `NECTX.send(0x42, byte)` with 50 ms gaps; implement `pings()` — acquire `_rx_lock`, copy and clear `_received_uids`, release lock, return copy; `Badge.__init__` starts IR RX background thread via `_thread.start_new_thread`
- [X] T026 [US3] Wire BTN_UP press to IR TX in `firmware/micropython-build/main.py` main loop: on `BTN_UP` state-change to pressed, call `irTransmitUID(tx, badge_uid)` (depends on T023, T024)

**Checkpoint**: Two-badge IR pairing works end-to-end. Single-badge TX verified via serial log. Partial buffer discard verified by stopping mid-sequence and waiting 500 ms. User Story 3 independently verified.

---

## Phase 6: User Story 4 — Button, Joystick, and Tilt Inputs (Priority: P4)

**Goal**: All physical inputs produce correct on-screen feedback. Buttons debounced at 40 ms. Joystick normalized ±1.0 clamped to 6-pixel circle. Tilt debounced at 300 ms.

**Independent Test**: Flash badge in BYPASS mode. In main UI, press each button — corresponding indicator dot fills at correct OLED position. Move joystick to extremes — position dot reaches edge of circle without exceeding it. Tilt badge past threshold — tilt indicator rect changes position after 300 ms with no jitter.

### Implementation for User Story 4

- [X] T027 [US4] Implement button debounce in `firmware/micropython-build/main.py`: create 4 `machine.Pin` objects (GPIO 8–11, `Pin.IN`, `Pin.PULL_UP`); per-button debounce state: `last_reading`, `last_debounce_ms`, `state`; 40 ms debounce — only update `state` when `ticks_diff(ticks_ms(), last_debounce_ms) >= 40` and raw reading differs; draw indicator dots at confirmed positions: BTN_UP=(118,48), BTN_DOWN=(118,58), BTN_LEFT=(113,53), BTN_RIGHT=(123,53); fill dot when `state == False` (active-low pressed)
- [X] T028 [US4] Implement joystick ADC polling in `firmware/micropython-build/main.py`: `machine.ADC(machine.Pin(JOY_X_PIN), atten=machine.ADC.ATTN_11DB)` and same for Y; poll every 50 ms; normalize: `nx = (raw_x - 2048) / 2048.0`, same for Y; clamp to unit circle: `dist = math.sqrt(nx*nx + ny*ny); if dist > 1.0: nx /= dist; ny /= dist`; compute dot pixel: `dot_x = 100 + round(nx * 6)`, `dot_y = 53 + round(ny * 6)`; draw 3×3 fill_rect at dot position (depends on T027 — same file, write after button implementation)
- [X] T029 [US4] Implement tilt switch debounce in `firmware/micropython-build/main.py`: `machine.Pin(TILT_PIN, Pin.IN, Pin.PULL_UP)`; 300 ms debounce (same pattern as buttons); when tilted (`state == False`): `display.fill_rect(84, 48, 4, 4, 1)`; when upright: `display.fill_rect(84, 54, 4, 4, 1)` (depends on T028 — same file)
- [X] T030 [US4] Integrate all inputs into main loop render cycle in `firmware/micropython-build/main.py`: each loop iteration: `display.fill(0)`; blit `GRAPHICS_BASE` via framebuf; draw all button indicator dots; draw joystick position dot; draw tilt indicator rect; draw IR TX/RX arrow sprites from `graphics.py` at correct positions; `display.show()`; total loop ≤ 50 ms (depends on T027, T028, T029)

**Checkpoint**: All 4 buttons, joystick, and tilt switch produce correct visual feedback with no missed events during manual exercise. Main loop iteration ≤ 50 ms observable via serial timing. User Story 4 independently verified.

---

## Phase 7: Polish & Cross-Cutting Concerns

**Purpose**: Final validation, cleanup, and edge case handling that spans multiple stories

- [X] T031 [P] Verify `.gitignore` covers `firmware/micropython-build/creds.py` — run `git check-ignore -v firmware/micropython-build/creds.py`; also confirm build artifacts (`.bin`, `build/` dirs) are excluded
- [X] T032 Run complete quickstart.md walkthrough end-to-end: fresh clone → `./build.sh` (verify binary ≤ 4 MB, exit 0) → `./flash.sh` → BYPASS mode boot sequence (all 6 OLED screens) → main UI inputs → IR TX (BTN_UP) → confirm all SC-001 through SC-006 success criteria pass
- [X] T033 Add edge case guards to `firmware/micropython-build/main.py` and `boot.py`: WiFi present but unreachable → display "WiFi failed" and halt after `WIFI_TIMEOUT_MS`; QR HTTP non-200 or network error → "QR unavailable, continuing..." for 2 s then proceed; `machine.unique_id()` < 6 bytes → zero-pad (already in data model formula; verify it's applied everywhere `badge_uid` is computed)

---

## Dependencies & Execution Order

### Phase Dependencies

- **Setup (Phase 1)**: No dependencies — start immediately
- **Foundational (Phase 2)**: Depends on Phase 1 — **BLOCKS all user stories**
- **User Story 1 (Phase 3)**: Depends on Phase 2 — cannot build without board definition
- **User Story 2 (Phase 4)**: Depends on Phase 3 — requires build + flash infrastructure working
- **User Story 3 (Phase 5)**: Depends on Phase 4 — IR TX/RX UI relies on main loop from US2
- **User Story 4 (Phase 6)**: Depends on Phase 3 (can start after US1 — inputs don't depend on display content from US2/US3, but same main.py file makes parallel work conflict-prone)
- **Polish (Phase 7)**: Depends on all user stories complete

### User Story Dependencies

- **US1 (P1)**: After Foundational — build/flash infrastructure is self-contained
- **US2 (P2)**: After US1 — requires working flash/REPL to verify OLED output
- **US3 (P3)**: After US2 — IR display messages integrate into the main UI from US2
- **US4 (P4)**: After US1 — inputs are independent but all edits land in `main.py`, so sequential after US2/US3 to avoid conflicts

### Within Each User Story

- Board definition files (Phase 2): all independent, write in parallel
- US1 files: all independent (different files), write in parallel
- US2: boot.py and graphics.py are parallel; main.py display entry is sequential after graphics.py
- US3: NECTX before NECRX (same file); RX thread before BTN_UP wiring (same file); badge_sdk.py update is parallel
- US4: buttons → joystick → tilt → integrate (all in main.py; sequential to avoid conflicts)

### Parallel Opportunities (Within Phase)

- Phase 2: T003–T009 can all run in parallel (7 separate files)
- Phase 3 US1: T010–T016 can all run in parallel (7 separate files)
- Phase 4 US2: T017 (boot.py) and T018 (graphics.py) in parallel; T020 (badge_sdk.py) in parallel; T019 (main.py) after T018
- Phase 5 US3: T021+T022 (ir_nec.py, sequential) in parallel with T025 (badge_sdk.py)

---

## Parallel Example: Phase 2 (Foundational)

```bash
# All 7 board definition files can be written simultaneously:
Task T003: boards/TEMPORAL_BADGE_DELTA/mpconfigboard.h
Task T004: boards/TEMPORAL_BADGE_DELTA/mpconfigboard.cmake
Task T005: boards/TEMPORAL_BADGE_DELTA/sdkconfig.board
Task T006: boards/TEMPORAL_BADGE_DELTA/partitions.csv
Task T007: boards/TEMPORAL_BADGE_DELTA/manifest.py
Task T008: boards/TEMPORAL_BADGE_DELTA/pins.csv
Task T009: config.py
```

## Parallel Example: Phase 3 (User Story 1)

```bash
# All US1 files are independent — write simultaneously:
Task T010: build.sh
Task T011: flash.sh
Task T012: boot.py (stub)
Task T013: main.py (stub)
Task T014: badge_sdk.py (stub)
Task T015: ir_nec.py (stub)
Task T016: graphics.py (stub)
```

---

## Implementation Strategy

### MVP First (User Story 1 Only)

1. Complete Phase 1: Setup (T001–T002)
2. Complete Phase 2: Foundational (T003–T009) — **CRITICAL gate**
3. Complete Phase 3: User Story 1 (T010–T016)
4. **STOP and VALIDATE**: Run `build.sh` and `flash.sh`, verify REPL accessible
5. Proceed to US2 only after US1 is verified

### Incremental Delivery

1. Setup + Foundational → board definition ready
2. US1 (build + flash + stubs) → REPL accessible, binary flashing verified (MVP!)
3. US2 (boot sequence + display) → full visual boot experience verified
4. US3 (IR pairing) → two-badge interaction working
5. US4 (inputs) → all hardware inputs verified
6. Polish → quickstart walkthrough passes all success criteria

### Single-Developer Sequence (Recommended)

```
Phase 1 → Phase 2 (all parallel) → Phase 3 (all parallel) → verify build
→ Phase 4 → verify OLED → Phase 5 → verify IR → Phase 6 → verify inputs
→ Phase 7 (quickstart walkthrough)
```

---

## Notes

- `[P]` tasks touch different files — safe to write concurrently
- Story labels trace each task to the user story it enables
- No automated tests — verification is manual flash → observe → interact
- `BYPASS = True` in `config.py` enables development without WiFi/server/second badge
- `firmware/shy-micropython-build/` is reference-only — do NOT copy files from it
- Pin assignments are authoritative from `Firmware-0306` — always cross-check against `constitution` table before writing `pins.csv` or `config.py`
- Commit after each verified checkpoint (US1 verified → commit; US2 verified → commit; etc.)

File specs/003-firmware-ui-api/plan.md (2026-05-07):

# Implementation Plan: Firmware UI & API Integration

**Branch**: `003-firmware-ui-api` | **Date**: 2026-03-10 | **Spec**: [spec.md](spec.md)
**Input**: Feature specification from `/specs/003-firmware-ui-api/spec.md`

## Summary

Five user stories spanning flash tool reliability, hardware UI verification, WiFi boot path, badge API client, and live nametag display. The largest new artifact is `badge_api.py` — a self-contained HTTP client module with a single transport function and named endpoint functions. Supporting changes: `flash.sh` interrupt and confirmation fixes, `boot.py` refactored to use `badge_api`, `boot.py` sleep loops broken into Ctrl+C-interruptible chunks, and a firmware rebuild to bake in the `_boot.py` auto-format fix.

## Technical Context

**Language/Version**: MicroPython v1.24.0 (Python 3.4 subset)
**Primary Dependencies**: `ssd1306` (frozen), `urequests` (frozen), `machine` (built-in), `esp32` (built-in), `mpremote` (dev toolchain)
**Storage**: VFS FAT partition on 8 MB QIO flash (4 MB factory app + 4 MB VFS)
**Testing**: Manual only — flash → REPL → observe boot → exercise inputs; no automated runner
**Target Platform**: ESP32-S3-MINI-1 running MicroPython v1.24.0, board `TEMPORAL_BADGE_DELTA`
**Project Type**: Embedded firmware (MicroPython VFS application)
**Performance Goals**: Display refresh ≤ 50 ms per frame; WiFi connect within `WIFI_TIMEOUT_MS` (5 s default); API calls complete within reasonable wall time on conference WiFi
**Constraints**: ≤ 240 KB available heap on device; no threads for HTTP (single-threaded urequests); flash.sh --vfs-only must complete in < 60 s
**Scale/Scope**: ~2,000 units; 5 VFS Python files modified; 1 new file (badge_api.py); 1 firmware rebuild

## Constitution Check

*GATE: Must pass before Phase 0 research. Re-checked after Phase 1 design.*

| Principle | Check | Notes |
|---|---|---|
| **I. MicroPython-First** | ✅ PASS | All new code is Python. No new C required. |
| **II. Firmware-0306 Parity** | ✅ PASS | Boot sequence (splash → WiFi → QR → nametag → main loop) preserved. Nametag source changes from raw server XBM to JSON-parsed text — this is a bugfix not a deviation (the /info endpoint returns JSON, not XBM). IR pairing unchanged. |
| **III. Credentials-at-Build** | ✅ PASS | `badge_api.py` reads `SERVER_URL` from `creds` module (VFS prototyping path). No credentials hardcoded in module. |
| **IV. Backend Contract Compliance** | ✅ PASS | All five endpoint functions match the API table in spec. QR generated on-device via `uQR.py` (no `/qr.xbm` call). HMAC insertion point designed into transport layer. |
| **V. Reproducible Build** | ✅ PASS | Firmware rebuild uses existing `build.sh` with pinned MicroPython v1.24.0 + ESP-IDF v5.2.3. No version changes. |
| **VI. Hardware Safety** | ✅ PASS | No GPIO changes. `pins.csv` unchanged. No eFuse operations in this spec. |

**Gate result: PASS — proceed to Phase 0.**

## Project Structure

### Documentation (this feature)

```text
specs/003-firmware-ui-api/
├── plan.md              # This file
├── research.md          # Phase 0 output
├── data-model.md        # Phase 1 output
├── quickstart.md        # Phase 1 output
├── contracts/
│   └── badge_api.md     # Phase 1 output — badge_api.py public interface
└── tasks.md             # Phase 2 output (/speckit.tasks command)
```

### Source Code (repository root)

```text
firmware/micropython-build/
├── badge_api.py         # NEW — HTTP client, transport layer, 5 endpoint functions
├── boot.py              # MODIFY — use badge_api; break sleeps into loops; JSON nametag
├── flash.sh             # MODIFY — fix echo-before-copy; remove VFS mount exec; per-file confirm
├── config.py            # MODIFY if needed — remove BYPASS/BYPASS_DELAY_MS now config is cleaned
├── graphics.py          # MODIFY if needed — display functions for nametag layout
├── main.py              # MODIFY if needed — fix any hardware UI issues found during verification
├── badge_sdk.py         # MODIFY if needed — align uid property naming, wire to badge_api
├── ir_nec.py            # MODIFY if needed
└── uQR.py               # MODIFY if needed
```

**Structure Decision**: Single embedded firmware directory. No backend changes (deferred). No test subdirectory (manual-only verification).

## Complexity Tracking

> No constitution violations — section intentionally empty.

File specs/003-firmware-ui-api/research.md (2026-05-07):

# Research: Firmware UI & API Integration

**Branch**: `003-firmware-ui-api` | **Date**: 2026-03-10

---

## R-001: mpremote Ctrl+C interrupt behavior vs. MicroPython sleep

**Decision**: Break all `utime.sleep_ms(N)` calls in `boot.py` that are > ~100 ms into loops of `utime.sleep_ms(50)` within a `for` range.

**Rationale**: `utime.sleep_ms(N)` is a single C-level call that holds the GIL for its entire duration. MicroPython can only service a Ctrl+C (KeyboardInterrupt) between bytecode instructions — not mid-C-call. When mpremote connects it sends one or two `\x03` (Ctrl+C) bytes, but if the badge is inside `sleep_ms(2000)` at the moment of connection, the interrupt is not received until the sleep returns. Breaking into `for _ in range(N // 50): utime.sleep_ms(50)` makes Ctrl+C deliverable on every 50 ms boundary, guaranteeing interrupt within 50–100 ms of mpremote connecting.

**Affected sleeps in boot.py**:
- `utime.sleep_ms(2000)` after splash → `for _ in range(20): utime.sleep_ms(100)`
- `utime.sleep_ms(1500)` after WiFi connect → `for _ in range(15): utime.sleep_ms(100)`
- `utime.sleep_ms(config.QR_DISPLAY_MS)` (10000 ms) → `for _ in range(100): utime.sleep_ms(100)`
- `utime.sleep_ms(2000)` after nametag → `for _ in range(20): utime.sleep_ms(100)`
- `utime.sleep_ms(config.BYPASS_DELAY_MS)` (3000 ms) → `for _ in range(30): utime.sleep_ms(100)`

**Alternatives considered**:
- Hardware button to skip boot (BTN_DOWN held → immediate REPL): more robust but requires GPIO polling in boot.py, more complex, and doesn't fix the shell script confirmation issue.
- `machine.soft_reset()` before copy session: causes mpremote reconnect timing problem; two-session approach reintroduces the "can't enter raw repl" race.
- No change to boot.py; only change flash.sh to wait longer: unreliable, sleep_ms is never interruptible within its window.

---

## R-002: flash.sh --vfs-only exec VFS mount necessity

**Decision**: Remove the `exec "import os,esp32; bdev=..."` mount command from the `--vfs-only` session. Rely exclusively on `_boot.py` (frozen) to mount the VFS before `boot.py` runs.

**Rationale**: The `_boot.py` frozen module always attempts `os.mount(bdev, '/')` on every boot, treating EBUSY (already mounted) as success and ENODEV (unformatted) as a format trigger. When the badge is running normally, VFS is already mounted. When mpremote connects and interrupts the badge, `_boot.py` has already executed — the VFS is mounted. The manual `exec` mount was added to handle cases where _boot.py wasn't doing this correctly; that bug is now fixed in source. The exec also requires the badge to be in a state where it can evaluate an import statement before boot.py runs, which is a race condition. Dropping it simplifies the flow to: `Ctrl+C → raw REPL → fs cp` directly.

**Alternatives considered**:
- Keep exec mount for safety: adds race condition risk; if VFS already mounted, the exec may fail or double-mount; cleaner to trust the frozen module.
- Use `mpremote exec "import os; os.listdir('/')"` to verify mount first: unnecessary round-trip; adds complexity.

---

## R-003: flash.sh per-file confirmation strategy

**Decision**: Switch `--vfs-only` from a single chained mpremote session to individual `mpremote connect PORT fs cp SRC :DST` invocations per file. Print the file name AFTER checking the exit code of each invocation.

**Rationale**: The chained session `mpremote connect PORT + fs cp a + fs cp b + reset` cannot provide per-file confirmation because all output is interleaved in a single session exit. Individual invocations let the shell check `$?` (exit code) after each copy and print either `  -> filename  OK` or `  ERROR: filename copy failed`. Each mpremote fs cp session connects, interrupts boot.py (now interruptible thanks to R-001), copies one file, and disconnects. The reconnect overhead per file is acceptable for a developer tool (< 2 s per file on USB).

**Alternatives considered**:
- Parse mpremote session output for per-file success markers: mpremote does not emit structured per-file status; parsing stdout is fragile.
- Single session with `+` separators but echo after: Bash executes all `echo` commands during array construction, before mpremote runs. There is no way to interleave bash echoes with mid-session mpremote output without external process communication.
- Use Python script wrapping mpremote: over-engineered; bash with per-invocation exit codes is sufficient.

---

## R-004: urequests JSON parsing in MicroPython

**Decision**: Use `r.json()` method provided by `urequests` (frozen). This calls `ujson.loads(r.text)` internally. No additional import needed.

**Rationale**: The frozen `urequests` module exposes a `.json()` method on the response object that delegates to MicroPython's built-in `ujson`. This is the idiomatic approach, consistent with the CPython requests API. The `/api/v1/badge/{uuid}/info` endpoint returns `application/json` with keys `name`, `title`, `company`, `attendee_type`.

**Key finding — boot.py bug**: The current `boot.py` calls `_parse_xbm(r.text)` on the `/info` response, treating it as XBM binary data. This is incorrect — `/info` returns JSON. This bug silently produces garbage on the OLED. The fix is to use `badge_api.get_badge_info()` which correctly calls `.json()`.

**Alternatives considered**:
- `ujson.loads(r.text)` directly: equivalent but bypasses urequests abstraction; `r.json()` is cleaner.
- Manual JSON parsing with `re`: unnecessary complexity; ujson is available.

---

## R-005: badge_api.py transport layer design

**Decision**: Implement a single `_request(method, path, body=None)` internal function. All named endpoint functions call `_request`. Authentication headers (X-Badge-ID, X-Timestamp, X-Signature) will be added exclusively inside `_request` when the HMAC module is available, with zero changes to endpoint functions.

**Rationale**: FR-018 requires a single transport function for auth insertion. The design: `_request` reads `SERVER_URL` from the `creds` module (imported lazily on first call). It builds the URL, sets Content-Type for POST, calls `urequests.request(method, url, headers=headers, data=ujson.dumps(body))`, closes the response, and returns the parsed JSON or None. Named functions (`get_badge_info`, `create_boop`, etc.) are thin wrappers over `_request`.

**HMAC insertion point**: When HMAC signing is added in a future spec, only `_request` changes:
```python
def _request(method, path, body=None):
    headers = {"Content-Type": "application/json"}
    # FUTURE: add X-Badge-ID, X-Timestamp, X-Signature here
    ...
```
No endpoint function or caller (boot.py, main.py, badge_sdk.py) requires modification.

**Error handling contract**:
- HTTP 2xx: return parsed JSON dict (or True for DELETE/no-body responses)
- HTTP 404: return `None`
- HTTP other non-2xx: return `None` (log the status code)
- Network exception (OSError, etc.): return `None` (log the exception)
- Always: `r.close()` in a `finally` block

**Alternatives considered**:
- Class-based client (BadgeApiClient): unnecessary for 5 functions with no shared mutable state; module-level functions are simpler and work better in MicroPython's import model.
- Async urequests: not available in MicroPython standard urequests; would require uasyncio integration which conflicts with the IR _thread loop.

---

## R-006: Nametag display layout

**Decision**: Display nametag using three `display.text()` calls at fixed y-positions after `display.fill(0)`, with each field truncated to 16 characters. No call to `draw_base()` during nametag display (full-screen nametag, matching Firmware-0306 behavior).

**Rationale**: The constitution (Principle II) specifies a distinct "nametag" display mode separate from the main UI chrome. In Firmware-0306, the nametag is a full-screen display. Three text lines at y=10, y=26, y=42 give comfortable 16-pixel spacing. Truncation at 16 chars (matching `display.text()` 8×8 font × 16 chars = 128 px full width) prevents overflow. Null/missing fields render as empty string via `str(info.get('name') or '')[:16]`.

**Response field mapping**:
- `name` → line 1, y=10
- `title` → line 2, y=26
- `company` → line 3, y=42

**Alternatives considered**:
- Scrolling text for long fields: complex, not in spec, deferred.
- Using `draw_mock_nametag` as a template: that function uses a border frame and hardcoded text; replacing it with JSON data requires rewriting it anyway.

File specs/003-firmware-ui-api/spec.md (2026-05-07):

# Feature Specification: Firmware UI & API Integration

**Feature Branch**: `003-firmware-ui-api`
**Created**: 2026-03-10
**Status**: Draft
**Input**: User description: "Create spec 002-firmware-ui-and-api for the Temporal Badge DELTA MicroPython firmware — flash tool reliability, hardware UI verification, WiFi boot path, badge API client, live nametag from server."

## User Scenarios & Testing *(mandatory)*

### User Story 1 — Reliable Badge Update Tool (Priority: P1)

A developer needs to update Python files on a running badge without performing a full firmware reflash. Currently the update tool fails silently: file names appear in the terminal before any copy actually happens, and the tool cannot interrupt the badge's startup sequence. The developer cannot trust whether files were actually updated.

**Why this priority**: All subsequent development depends on being able to reliably push code changes to the badge. Without a working update tool, every change requires a full firmware flash cycle, blocking iteration on all other user stories.

**Independent Test**: Developer runs `./flash.sh --vfs-only` on a powered-on badge; every file name appears in the terminal only after that file is confirmed copied; the badge responds normally afterward.

**Acceptance Scenarios**:

1. **Given** the badge is powered on and running its startup sequence, **When** the developer runs `./flash.sh --vfs-only`, **Then** the tool reliably interrupts the badge and enters copy mode within 10 seconds.
2. **Given** the tool has entered copy mode, **When** a file is successfully copied, **Then** the file name is printed to terminal; if copy fails, an error is printed instead (not the file name).
3. **Given** `./flash.sh --vfs-only` completes, **When** the badge restarts, **Then** the VFS filesystem mounts cleanly without format errors.

---

### User Story 2 — Verified Hardware Inputs & Display (Priority: P2)

A hardware engineer needs confidence that all physical inputs on the badge (buttons, joystick, tilt sensor) produce the correct visual feedback on the OLED display. The display uses procedural drawing functions rather than stored images.

**Why this priority**: Hardware verification must happen before adding network features. A badge with broken button or display logic cannot be used at a conference regardless of backend connectivity.

**Independent Test**: Tester exercises each input on a live badge and observes the OLED; no backend connection required.

**Acceptance Scenarios**:

1. **Given** a powered badge in the main UI loop, **When** each of the 4 directional buttons is pressed individually, **Then** a filled dot appears at the correct position in the d-pad area of the display (active-low logic: dot shows when button is physically held).
2. **Given** the main UI is running, **When** the joystick is moved in any direction, **Then** a dot tracks within a 6-pixel radius circle on the display.
3. **Given** the badge is tilted, **When** the tilt sensor holds a new state for 300 ms, **Then** a visual indicator on the display changes position to reflect the new orientation.
4. **Given** the badge is idle, **When** an IR signal is transmitted or received, **Then** directional arrows animate on the display for the duration of the event.
5. **Given** any display state, **When** `draw_base()` renders the chrome layer, **Then** the TEMPORAL header, status bar, joystick circle, and d-pad crosshair all appear at expected positions with no rendering artifacts.

---

### User Story 3 — WiFi Connection at Startup (Priority: P3)

An attendee powers on their badge at the conference venue. The badge automatically connects to the venue WiFi using stored credentials, syncs the clock, and shows the connection status on the OLED before loading the main UI.

**Why this priority**: WiFi connectivity is the prerequisite for all server-connected features. Without it, the badge operates in offline-only mode and cannot display live attendee data.

**Independent Test**: Badge with valid credentials powers on; OLED shows "Connected to \<SSID\>" and the system clock is confirmed synced in the REPL.

**Acceptance Scenarios**:

1. **Given** credentials are stored on the badge, **When** the badge powers on, **Then** it attempts WiFi connection within the configured timeout and displays progress on the OLED.
2. **Given** valid credentials and a reachable access point, **When** connection succeeds, **Then** the OLED shows "Connected to \<SSID\>" and the system clock is synchronized.
3. **Given** invalid credentials or an unreachable access point, **When** the connection attempt exceeds the configured timeout, **Then** the OLED shows "WiFi failed" and the badge halts without proceeding to server-dependent features.

---
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

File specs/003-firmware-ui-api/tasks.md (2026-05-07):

# Tasks: Firmware UI & API Integration

**Input**: Design documents from `/specs/003-firmware-ui-api/`
**Prerequisites**: plan.md ✓, spec.md ✓, research.md ✓, data-model.md ✓, contracts/badge_api.md ✓, quickstart.md ✓

**Tests**: Manual only — no automated test runner on device. Verification steps from quickstart.md.

**Organization**: Tasks grouped by user story for independent implementation and verification.
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

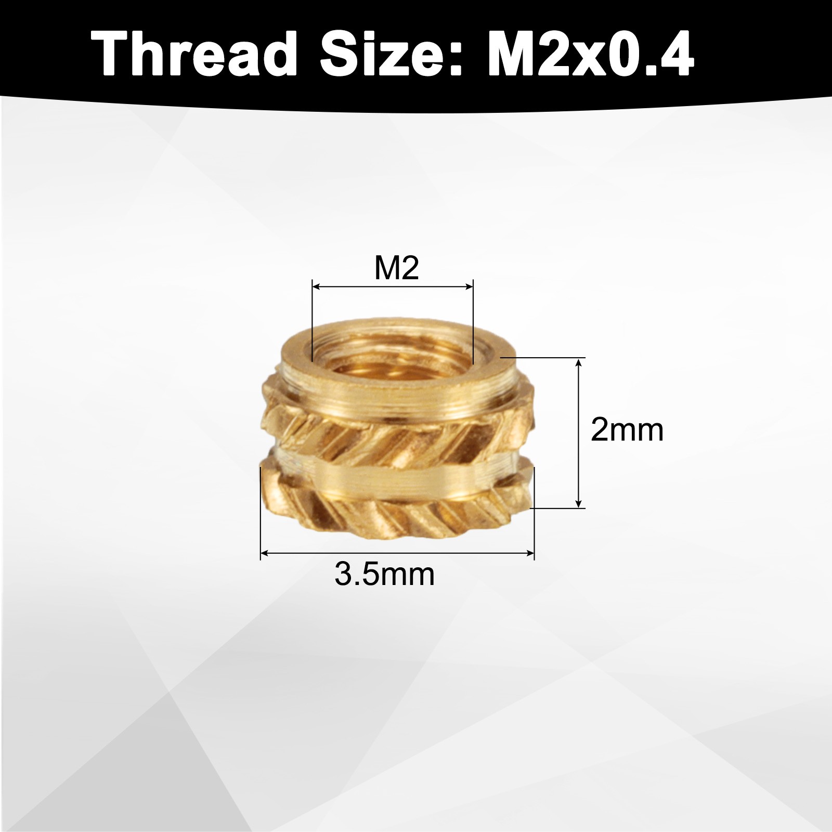
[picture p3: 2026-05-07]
hardware/BRAVO/assets/M2x2_INSERT.jpg

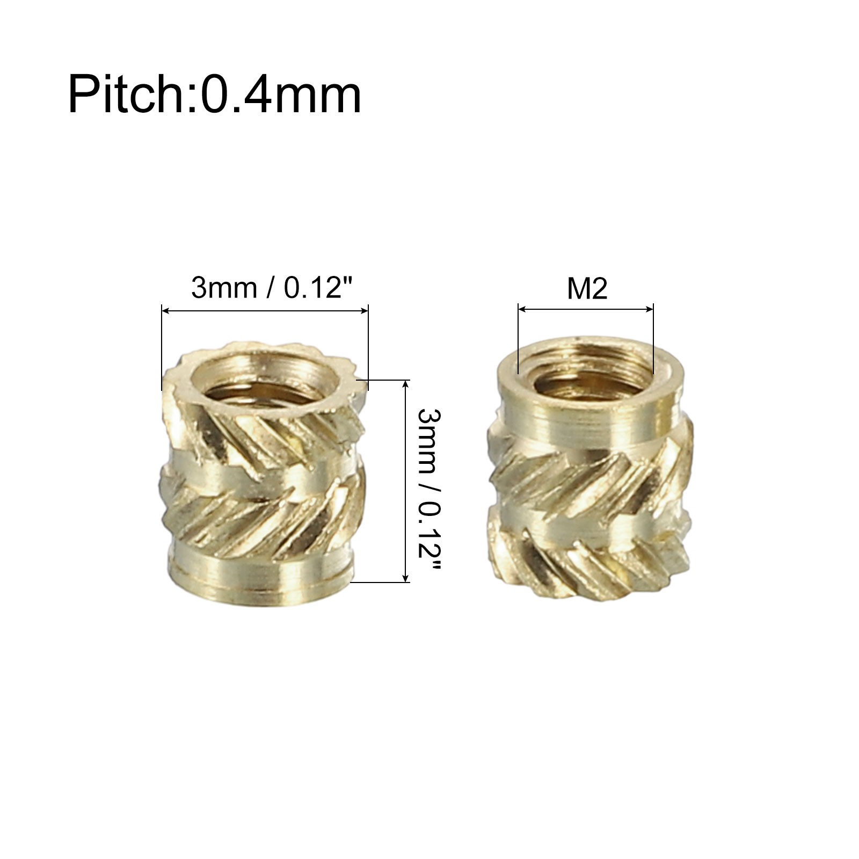
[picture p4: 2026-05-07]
hardware/BRAVO/assets/M2x3_INSERT.jpg

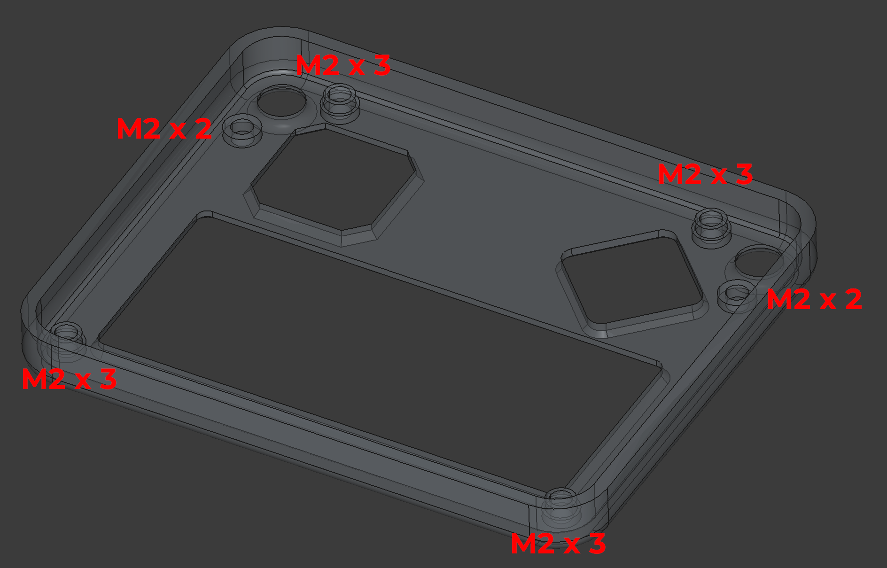
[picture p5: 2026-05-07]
hardware/BRAVO/assets/BRAVO_INSERT_REF.png

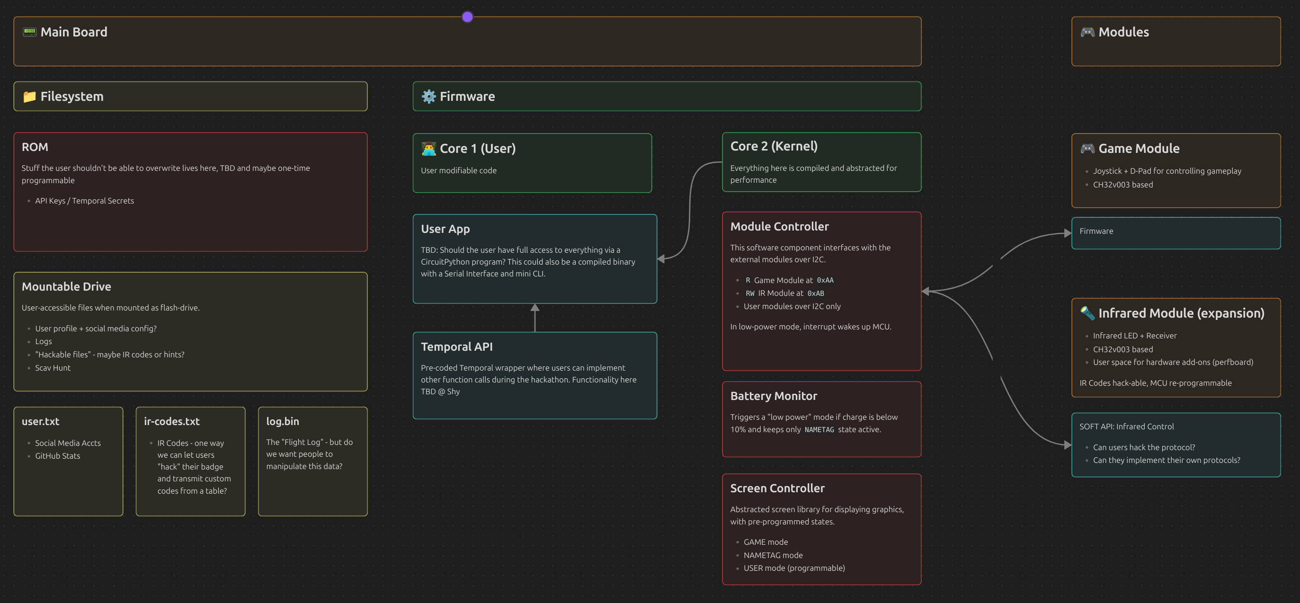
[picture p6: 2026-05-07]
docs/rough-architecture.png

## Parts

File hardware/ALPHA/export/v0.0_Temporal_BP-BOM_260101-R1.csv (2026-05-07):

Designator | Comment | Footprint | LCSC
C1,C33,C40,C41 | 22uF | Capacitor_SMD:C_0402_1005Metric | C3845593
C2,C3,C4,C6,C7 | 0.1uF | Capacitor_SMD:C_0402_1005Metric | C1525
C5,C8,C24,C43 | 1uF | Capacitor_SMD:C_0402_1005Metric | C14445
C25 | 10uF | Capacitor_SMD:C_0402_1005Metric | C315248
C34 | 470 nF | Capacitor_SMD:C_0402_1005Metric | C92361
C37 | 100nF | Capacitor_SMD:C_0402_1005Metric | C1525
C38 | 22pF | Capacitor_SMD:C_0402_1005Metric | C76960
D1,D2 | D_Schottky | Diode_SMD:D_SOD-323 | C60580
D3,D4,D5 | D_TVS | Diode_SMD:D_SOD-523 | C3008120
D6,D7 | WS2812B | LED_SMD:LED_WS2812B_PLCC4_5.0x5.0mm_P3.2mm | C114586
D8,D9,D10 | D_Schottky | Diode_SMD:D_SOD-523 | C917006
D14,D15 | VSMY14940 | Temporal:vsmy14940 | C511069
J1 | USB C 2.0 | Connector_USB:USB_C_Receptacle_Palconn_UTC16-G | C2765186
J2,J4 | Qwiic | Connector_JST:JST_SH_SM04B-SRSS-TB_1x04-1MP_P1.00mm_Horizontal | C51940130
J3 | JST PH | Connector_JST:JST_PH_S2B-PH-SM4-TB_1x02-1MP_P2.00mm_Horizontal | C295747
J8 | Micro-SD | Temporal:MicroSD | C381082
L5 | 2.2uF | Inductor_SMD:L_Coilcraft_LPS3010 | C2926400
Q1 | DMN2058UW / 2N3904 | Package_TO_SOT_SMD:SOT-23 | C54879
Q3 | AO3401A | Package_TO_SOT_SMD:SOT-23 | C15127
Q4 | L2N7002SDW | Package_TO_SOT_SMD:SOT-23 | C383163
R1,R2,R3,R4,R5,R11,R12,R13,R17 | 0 | Resistor_SMD:R_0402_1005Metric | C106231
R6,R38 | 10K | Resistor_SMD:R_0402_1005Metric | C60490
R7,R8 | 4.7K | Resistor_SMD:R_0402_1005Metric | C105871
R9,R10,R18 | 5.1K | Resistor_SMD:R_0402_1005Metric | C25905
R14 | 680K | Resistor_SMD:R_0402_1005Metric | C163456
R15 | 150K | Resistor_SMD:R_0402_1005Metric | C93947
R16 | 1K | Resistor_SMD:R_0402_1005Metric | C106235
R19,R22,R34 | 100K | Resistor_SMD:R_0402_1005Metric | C60491
R20,R23 | 220K | Resistor_SMD:R_0402_1005Metric | C25767
R30,R31 | 470K | Resistor_SMD:R_0402_1005Metric | C137976
R36,R37 | 39 | Resistor_SMD:R_0402_1005Metric | C185420
R39 | 150 | Resistor_SMD:R_0402_1005Metric | C138054
R40 | 10 | Resistor_SMD:R_0402_1005Metric | C138066
SW1 | Reset | Button_Switch_SMD:Panasonic_EVQPUL_EVQPUC | C79174
SW2 | BOOT | Button_Switch_SMD:Panasonic_EVQPUL_EVQPUC | C79174
SW3 | Latch | Button_Switch_SMD:SW_SPST_B3U-1000P-B | C49234121
U1 | ESP32-S3-MINI-1 | RF_Module:ESP32-S2-MINI-1 | C3013906
U5 | BQ25185 | Package_SON:WSON-10-1EP_4x3mm_P0.5mm_EP2.2x2mm | C19725033
U10 | SY8089 | Package_TO_SOT_SMD:SOT-23-5 | C79313
Y1 | 32.768KHz | Crystal:Crystal_SMD_3215-2Pin_3.2x1.5mm | C97606

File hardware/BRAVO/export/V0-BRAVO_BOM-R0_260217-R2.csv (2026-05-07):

Designator | Qty | Value | DNP | Exclude from BOM | Exclude from Board | Footprint | Datasheet | LCSC | Description
C1,C33,C40,C41 | 4 | 22uF |  |  |  | Capacitor_SMD:C_0402_1005Metric | ~ | C3845593 | Unpolarized capacitor,Unpolarized capacitor, small symbol
C1-1,C1-2,C1-3,C1-4,C1-5,C1-6,C1-7,C1-8,C2-1,C2-2,C2-3,C2-4,C2-5,C2-6,C2-7,C2-8,C3-1,C3-2,C3-3,C3-4,C3-5,C3-6,C3-7,C3-8,C4-1,C4-2,C4-3,C4-4,C4-5,C4-6,C4-7,C4-8,C5-1,C5-2,C5-3,C5-4,C5-5,C5-6,C5-7,C5-8,C6-1,C6-2,C6-3,C6-4,C6-5,C6-6,C6-7,C6-8,C7-1,C7-2,C7-3,C7-4,C7-5,C7-6,C7-7,C7-8,C8-1,C8-2,C8-3,C8-4,C8-5,C8-6,C8-7,C8-8 | 64 | LED0603_NOOUTLINE |  |  |  | Adafruit IS31FL3731 CharliePlex Grid:CHIPLED_0603_NOOUTLINE | ~ | C19171390 | Light emitting diode
C2,C11,C12,C14,C29,C37 | 6 | 100nF |  |  |  | Capacitor_SMD:C_0402_1005Metric | ~ | C1525 | Unpolarized capacitor,Unpolarized capacitor, small symbol
C3,C4,C6,C7,C16 | 5 | 0.1uF |  |  |  | Capacitor_SMD:C_0402_1005Metric | ~ | C1525 | Unpolarized capacitor
C5,C15,C17,C18,C19,C20,C21,C22,C23,C24,C25,C26 | 12 | 1uF |  |  |  | Capacitor_SMD:C_0402_1005Metric | ~ | C14445 | Unpolarized capacitor,Unpolarized capacitor, small symbol
C9,C10 | 2 | 4.7uF |  |  |  | Capacitor_SMD:C_0402_1005Metric | ~ | C315248 | Unpolarized capacitor, small symbol
C9-1,C9-2,C9-3,C9-4,C9-5,C9-6,C9-7,C9-8 | 8 | LED0603_NOOUTLINE | DNP | Excluded from BOM |  | Adafruit IS31FL3731 CharliePlex Grid:CHIPLED_0603_NOOUTLINE | ~ |  | Light emitting diode
C13,C27 | 2 | 10uF |  |  |  | Capacitor_SMD:C_0402_1005Metric | ~ | C315248 | Unpolarized capacitor, small symbol
C38 | 1 | 22pF |  |  |  | Capacitor_SMD:C_0402_1005Metric | ~ | C76960 | Unpolarized capacitor, small symbol
D1,D3,D4,D5,D6,D7,D8,D9 | 8 | D_Schottky |  |  |  | Diode_SMD:D_SOD-523 | ~ | C917006 | Schottky diode
D2 | 1 | DSS24 / 1N5819WS |  |  |  | Diode_SMD:D_SOD-123F | ~ | C511865 | Schottky diode
D10 | 1 | PRTR5V0U2X |  |  |  | Package_TO_SOT_SMD:SOT-143 | https://assets.nexperia.com/documents/data-sheet/PRTR5V0U2X.pdf | C5180302 | Ultra low capacitance double rail-to-rail ESD protection diode, SOT-143
D14,D15 | 2 | VSMY14940 |  |  |  | Temporal:vsmy14940 | ~ | C511069 | Light emitting diode
J1 | 1 | USB C 2.0 |  |  |  | Connector_USB:USB_C_Receptacle_Palconn_UTC16-G | https://www.usb.org/sites/default/files/documents/usb_type-c.zip | C2765186
J2 | 1 | I2C |  |  |  | Connector_PinSocket_2.54mm:PinSocket_1x04_P2.54mm_Vertical | ~ |  | Generic connector, single row, 01x04, script generated
J3 | 1 | JST PH |  |  |  | Connector_JST:JST_PH_S2B-PH-SM4-TB_1x02-1MP_P2.00mm_Horizontal | ~ | C295747 | Generic connectable mounting pin connector, single row, 01x02, script generated (kicad-library-utils/schlib/autogen/connector/)
J4 | 1 | TC2030 | DNP | Excluded from BOM |  | Connector:Tag-Connect_TC2030-IDC-NL_2x03_P1.27mm_Vertical | https://www.tag-connect.com/wp-content/uploads/bsk-pdf-manager/TC2030-CTX_1.pdf |  | Tag-Connect ARM Cortex SWD JTAG connector, 6 pin, no legs
JP1,JP2 | 2 | Jumper_2_Open | DNP | Excluded from BOM |  | Jumper:SolderJumper-2_P1.3mm_Open_RoundedPad1.0x1.5mm | ~ |  | Jumper, 2-pole, open
L5 | 1 | 2.2uh |  |  |  | Inductor_SMD:L_Coilcraft_LPS3010 | https://www.lcsc.com/datasheet/lcsc_datasheet_2410121211_YJYCOIN-YHNR4020-2R2M_C2926400.pdf | C2926400 | Inductor
Q2 | 1 | MMBT3904 |  |  |  | Package_TO_SOT_SMD:SOT-23 | https://www.onsemi.com/pdf/datasheet/pzt3904-d.pdf | C916374 | 0.2A Ic, 40V Vce, Small Signal NPN Transistor, SOT-23
Q3 | 1 | DMN2058U |  |  |  | Package_TO_SOT_SMD:SOT-23 | http://www.diodes.com/assets/Datasheets/DMN2058U.pdf | C461001 | 4.6A Id, 20V Vds, N-Channel MOSFET, SOT-23
R1,R2,R3,R4,R5,R11,R12,R13,R30,R46 | 10 | 0 |  |  |  | Resistor_SMD:R_0201_0603Metric | ~ | C106228 | Resistor
R6,R16,R17,R18,R21,R24,R28,R29,R32,R35,R38,R43,R44,R45 | 14 | 10K |  |  |  | Resistor_SMD:R_0402_1005Metric | ~ | C60490 | Resistor
R7,R8 | 2 | 4.7K |  |  |  | Resistor_SMD:R_0402_1005Metric | ~ | C105871 | Resistor
R9,R10 | 2 | 5.1K |  |  |  | Resistor_SMD:R_0402_1005Metric | ~ | C25905 | Resistor
R14,R22 | 2 | 680K |  |  |  | Resistor_SMD:R_0402_1005Metric | ~ | C163456 | Resistor
R15 | 1 | 150K |  |  |  | Resistor_SMD:R_0402_1005Metric | ~ | C93947 | Resistor
R19,R20 | 2 | 1.8 |  |  |  | Resistor_SMD:R_0402_1005Metric | ~ | C203083 | Resistor
R23,R25 | 2 | 100K |  |  |  | Resistor_SMD:R_0402_1005Metric | ~ | C60491 | Resistor
R26,R34 | 2 | 10K | DNP |  |  | Resistor_SMD:R_0402_1005Metric | ~ | C25767,C60490 | Resistor
R27 | 1 | 220 |  |  |  | Resistor_SMD:R_0402_1005Metric | ~ | C112291 | Resistor
R31,R41,R42 | 3 | 1K |  |  |  | Resistor_SMD:R_0402_1005Metric | ~ | C106235 | Resistor
R33,R39 | 2 | 150 |  |  |  | Resistor_SMD:R_0402_1005Metric | ~ | C138054 | Resistor
R36,R37 | 2 | 24 |  |  |  | Resistor_SMD:R_0402_1005Metric | ~ | C270625 | Resistor
R40 | 1 | 10 |  |  |  | Resistor_SMD:R_0402_1005Metric | ~ | C138066 | Resistor
SW1 | 1 | Reset |  |  |  | Button_Switch_SMD:SW_SPST_B3U-1000P-B | ~ | C231329 | Push button switch, generic, two pins
SW2 | 1 | BOOT |  |  |  | Button_Switch_SMD:Panasonic_EVQPUM_EVQPUD | ~ | C79174 | Push button switch, generic, two pins
SW4,SW5,SW6,SW7 | 4 | SW_Push |  |  |  | Button_Switch_SMD:SW_Push_1TS009xxxx-xxxx-xxxx_6x6x5mm | ~ | C25168849 | Push button switch, generic, two pins
U1 | 1 | ST LIS2DH12TR |  |  |  | Package_LGA:LGA-12_2x2mm_P0.5mm | https://www.st.com/resource/en/datasheet/lis2DE12.pdf | C110926 | 3-Axis Accelerometer, 2/4/8/16g range, I2C/SPI interface
U2 | 1 | BQ24079RGT |  |  |  | Package_DFN_QFN:VQFN-16-1EP_3x3mm_P0.5mm_EP1.6x1.6mm | http://www.ti.com/lit/ds/symlink/bq24079.pdf | C2876751 | USB-Friendly Li-Ion Battery Charger and Power-Path Management, VQFN-16
U3 | 1 | ESP32-S3-WROOM-1 |  |  |  | RF_Module:ESP32-S3-WROOM-1 | https://www.espressif.com/sites/default/files/documentation/esp32-s3-wroom-1_wroom-1u_datasheet_en.pdf | C2913202 | RF Module, ESP32-S3 SoC, Wi-Fi 802.11b/g/n, Bluetooth, BLE, 32-bit, 3.3V, onboard antenna, SMD
U4 | 1 | IS31FL3731-QF |  |  |  | Package_DFN_QFN:QFN-28-1EP_4x4mm_P0.4mm_EP2.3x2.3mm | http://www.issi.com/WW/pdf/31FL3731.pdf | C191206 | 9x16 LED matrix driver with 8-bit PWM and breathing, QFN-28
U5 | 1 | ST7305 |  |  |  |  |  | C262643
U6 | 1 | p2765 | DNP |  |  | P2765 | https://www.adafruit.com/product/2765
U8 | 1 | TSOP75338 |  |  |  | LyndLabs-Module:TSOP753 |  | C499550
U9 | 1 | MAX17048 |  |  |  | Package_DFN_QFN:TDFN-8-1EP_2x2mm_P0.5mm_EP0.8x1.2mm |  | C2682616
U10 | 1 | SY8089 |  |  |  | Package_TO_SOT_SMD:SOT-23-5 | https://lcsc.com/product-detail/DC-DC-Converters_Silergy_SY8088AAC_SY8088AAC_C79313.html | C79313
Y1 | 1 | 32.768KHz |  |  |  | Crystal:Crystal_SMD_3215-2Pin_3.2x1.5mm | ~ | C97606 | Two pin crystal

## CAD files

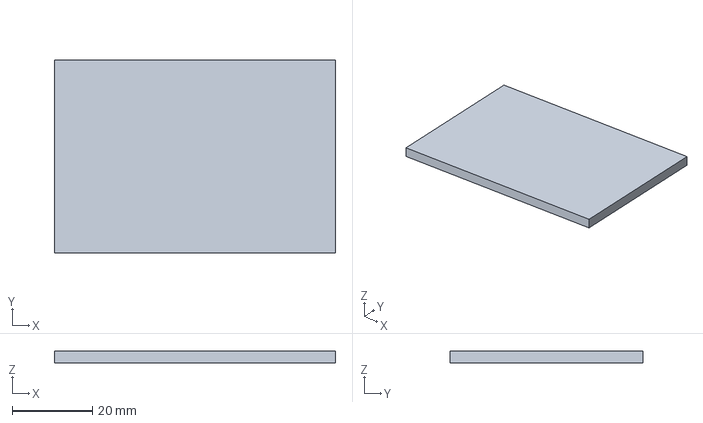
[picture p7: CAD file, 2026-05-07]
assets/SSD1309-devboard.step
70.2 x 48.1 x 3.00 mm

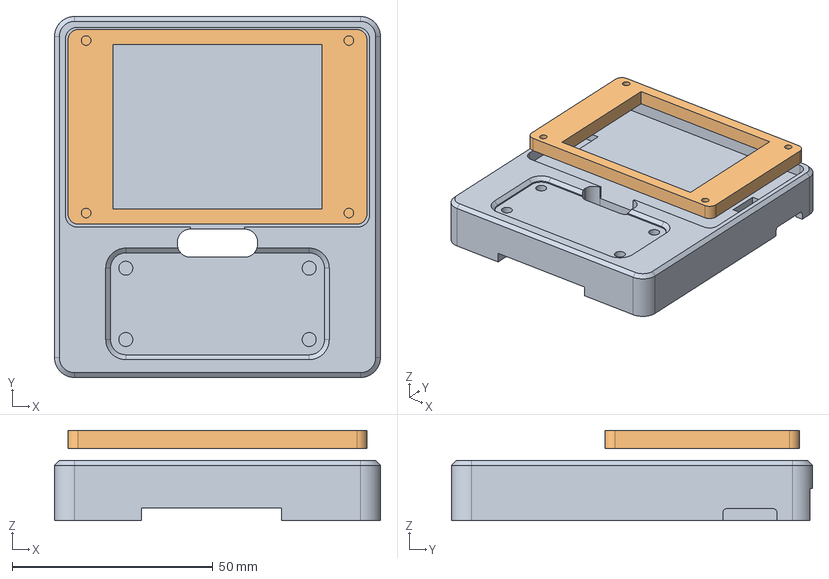
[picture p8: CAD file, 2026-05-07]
hardware/ALPHA/Temporal-Badge-Prototype.FCStd
81.3 x 90.0 x 22.5 mm

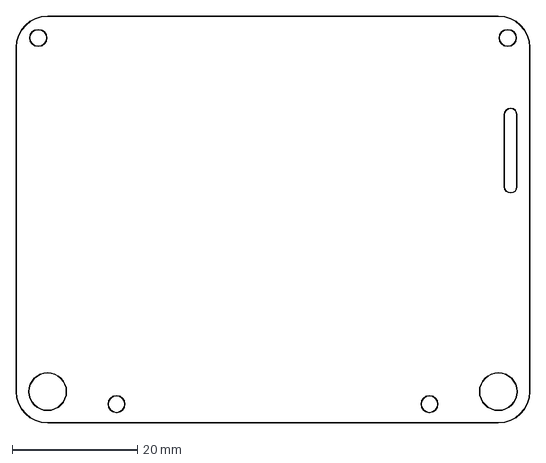
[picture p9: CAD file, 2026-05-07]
hardware/BRAVO/assets/BRAVO-Outline-R1.dxf
82.0 x 65.0 mm

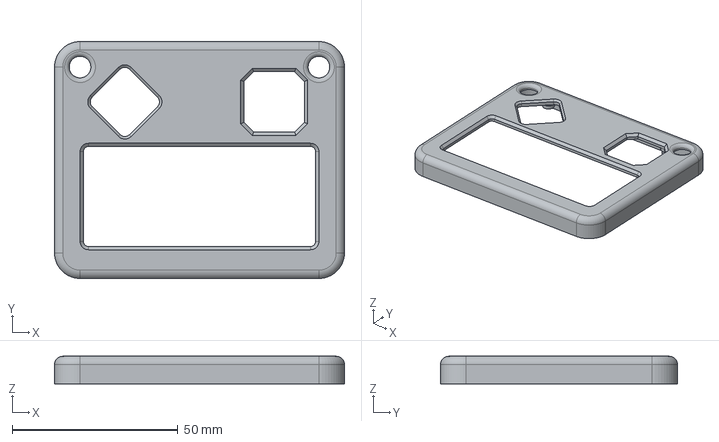
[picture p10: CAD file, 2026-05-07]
hardware/BRAVO/export/V0-BRAVO_ENCLOSURE-R0_260217.step
87.4 x 71.4 x 8.30 mm

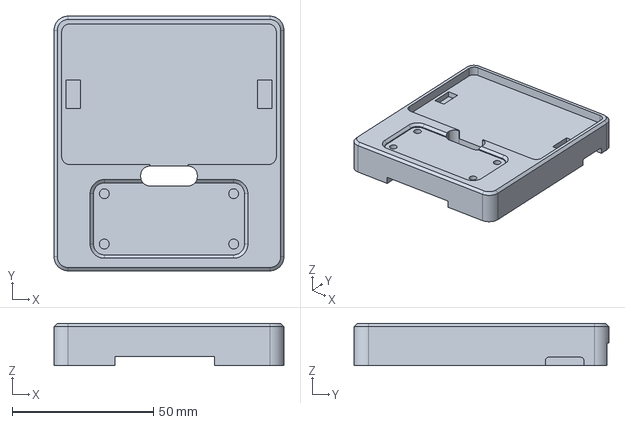
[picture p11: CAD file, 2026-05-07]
hardware/BRAVO/pcb/Temporal-Badge-Prototype.FCStd
81.3 x 90.0 x 15.0 mm

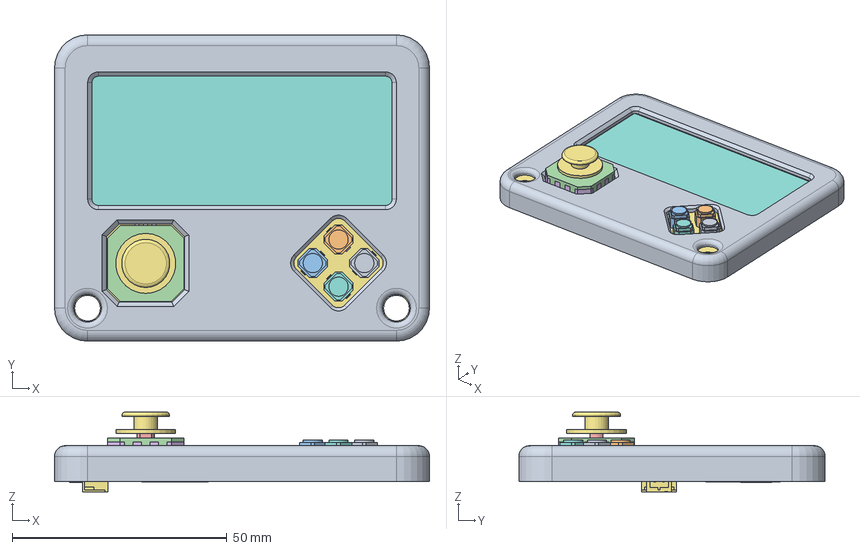
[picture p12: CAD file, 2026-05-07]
hardware/BRAVO/V0-BRAVO_ENCLOSURE-R0.FCStd
87.4 x 71.4 x 18.6 mm
LED_0603_1608Metric
LED_0603_1608Metric001
LED_0603_1608Metric002
LED_0603_1608Metric003
LED_0603_1608Metric004
LED_0603_1608Metric005
LED_0603_1608Metric006
pin_1
pin_2
LED_0603_1608Metric007
LED_0603_1608Metric008
LED_0603_1608Metric009
LED_0603_1608Metric010
LED_0603_1608Metric011
LED_0603_1608Metric012
LED_0603_1608Metric013
LED_0603_1608Metric014
JOYSTICK_ANALOG_MINITHM
JOYSTICK_ANALOG_MINITHM001
JOYSTICK_ANALOG_MINITHM002
JOYSTICK_ANALOG_MINITHM003
LED_0603_1608Metric015
LED_0603_1608Metric016
LED_0603_1608Metric017
LED_0603_1608Metric018
LED_0603_1608Metric019
LED_0603_1608Metric020
LED_0603_1608Metric021
FPC-24
FPC-025
FPC-026
FPC-027
FPC-028
FPC-029
FPC-030
FPC-031
FPC-032
FPC-033
FPC-034
FPC-035
FPC-036
FPC-037
FPC-038
FPC-039
FPC-040
ST7305
LED_0603_1608Metric022
LED_0603_1608Metric023
LED_0603_1608Metric024
LED_0603_1608Metric025
LED_0603_1608Metric026
LED_0603_1608Metric027
LED_0603_1608Metric028
LED_0603_1608Metric029
LED_0603_1608Metric030
LED_0603_1608Metric031
LED_0603_1608Metric032
LED_0603_1608Metric033
LED_0603_1608Metric034
LED_0603_1608Metric035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

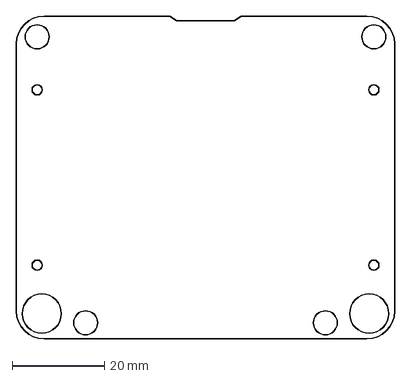
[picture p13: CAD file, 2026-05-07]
hardware/CHARLIE/assets/V0-CHARLIE_PCB-Outline-R2.dxf
82.0 x 70.0 mm

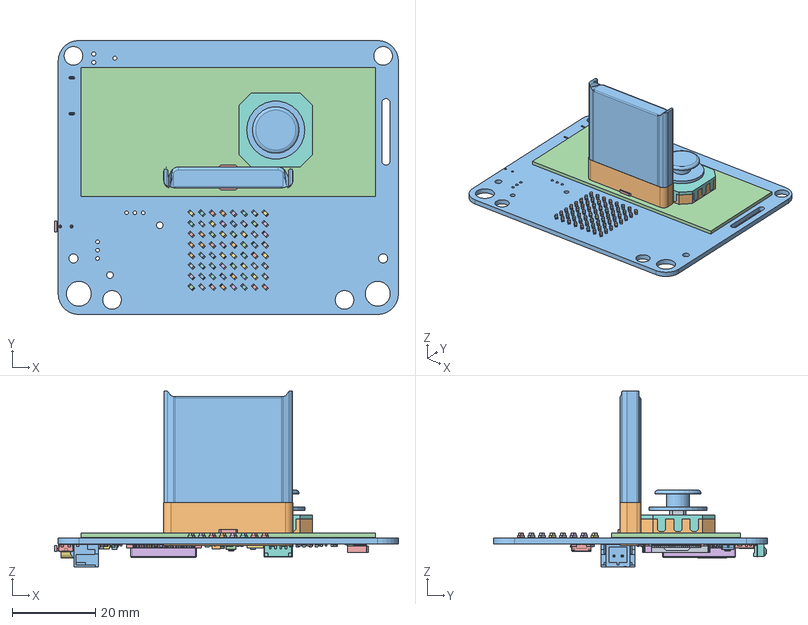
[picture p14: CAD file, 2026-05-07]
hardware/CHARLIE/enclosure/V0-CHARLIE_ENCLOSURE-R0.FCStd
82.9 x 66.0 x 42.4 mm
LED_0603_1608Metric
Kapton Tape
Battery Cell
Board Part 1
PCB
Board Part 2
LED_0603_1608Metric001
LED_0603_1608Metric002
LED_0603_1608Metric003
LED_0603_1608Metric004
LED_0603_1608Metric005
LED_0603_1608Metric006
pin_1
pin_2
LED_0603_1608Metric007
LED_0603_1608Metric008
LED_0603_1608Metric009
LED_0603_1608Metric010
LED_0603_1608Metric011
LED_0603_1608Metric012
LED_0603_1608Metric013
LED_0603_1608Metric014
JOYSTICK_ANALOG_MINITHM
JOYSTICK_ANALOG_MINITHM001
JOYSTICK_ANALOG_MINITHM002
JOYSTICK_ANALOG_MINITHM003
LED_0603_1608Metric015
LED_0603_1608Metric016
LED_0603_1608Metric017
LED_0603_1608Metric018
LED_0603_1608Metric019
LED_0603_1608Metric020
LED_0603_1608Metric021
FPC-24
FPC-025
FPC-026
FPC-027
FPC-028
FPC-029
FPC-030
FPC-031
FPC-032
FPC-033
FPC-034
FPC-035
FPC-036
FPC-037
FPC-038
FPC-039
FPC-040
ST7305
LED_0603_1608Metric022
LED_0603_1608Metric023
LED_0603_1608Metric024
LED_0603_1608Metric025
LED_0603_1608Metric026
LED_0603_1608Metric027
LED_0603_1608Metric028
LED_0603_1608Metric029
LED_0603_1608Metric030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

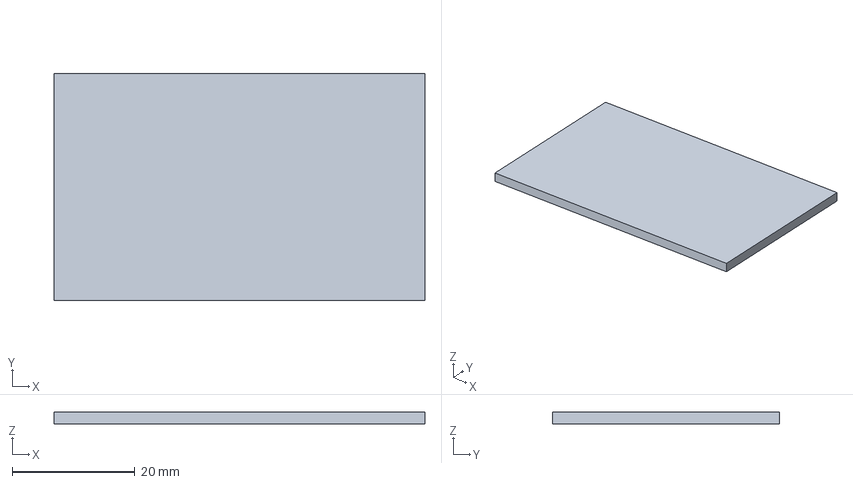
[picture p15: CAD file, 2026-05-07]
assets/SSD1309-Mockup.step
60.5 x 37.0 x 2.00 mm

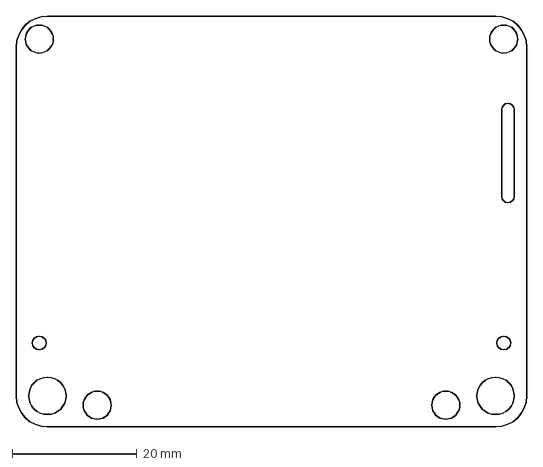
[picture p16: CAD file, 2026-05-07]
hardware/BRAVO/assets/BRAVO-Outline-R5.dxf
82.0 x 66.0 mm

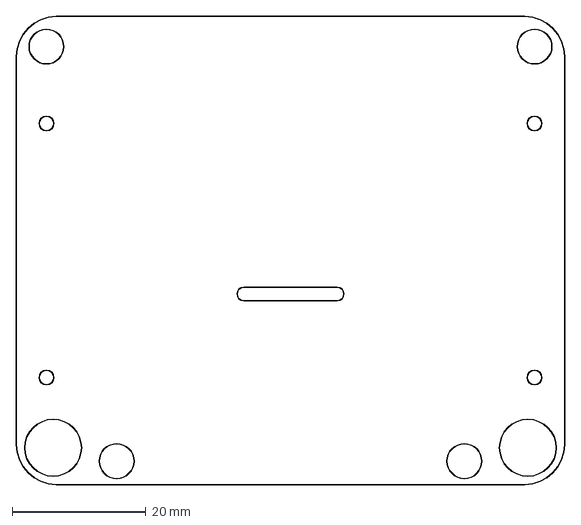
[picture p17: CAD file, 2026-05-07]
hardware/CHARLIE/assets/V0-CHARLIE_PCB-Outline-R3.dxf
82.0 x 70.0 mm

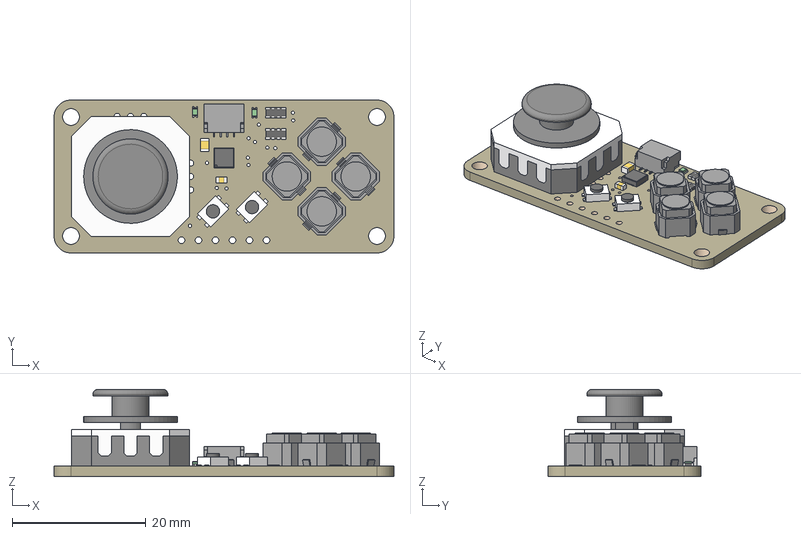
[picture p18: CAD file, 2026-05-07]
assets/5743 Mini Gamepad STEMMA QT.step
50.8 x 22.9 x 13.1 mm
Board
KMR2 x 2
0.1uF
10K Pack x 2
STEMMA_I2C_QT
Red x 2
10uF
ATTINY8X6_QFN
SJ_BUTTON x 4
JOYSTICK_ANALOG_XY

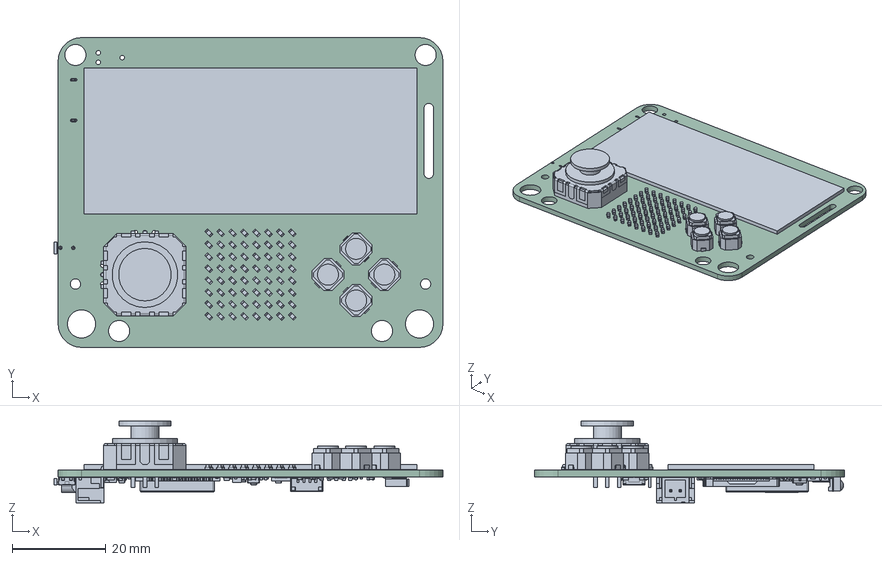
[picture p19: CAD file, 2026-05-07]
hardware/BRAVO/assets/v0_Temporal-Badge-BRAVO-R2.step
82.9 x 66.0 x 17.4 mm
LED_0603_1608Metric x 64
pin_1 x 4
pin_2 x 4
P2765
FPC-24
ST7305
R_0402_1005Metric x 36
C_0402_1005Metric x 32
SOT-23 x 2
Panasonic_EVQPUM_EVQPUD
D_SOD-523 x 8
R_0201_0603Metric x 10
ESP32-S3-WROOM-1
SOT-143
JST - PH - SMD (R) - 2Pin - 2.00mm
QFN-28-1EP_4x4mm_P0.4mm_EP2.4x2.4mm
56F6E7FA-7C16-416F-93ED-149845DA8218
56F6E7FA-7C16-416F-93ED-149845DA8219
56F6E7FA-7C16-416F-93ED-149845DA8220
56F6E7FA-7C16-416F-93ED-149845DA8221
56F6E7FA-7C16-416F-93ED-149845DA8222
56F6E7FA-7C16-416F-93ED-149845DA8223
56F6E7FA-7C16-416F-93ED-149845DA8224
56F6E7FA-7C16-416F-93ED-149845DA8225
56F6E7FA-7C16-416F-93ED-149845DA8226
56F6E7FA-7C16-416F-93ED-149845DA8227
56F6E7FA-7C16-416F-93ED-149845DA8228
SW_SPST_B3U-1000P-B
QFN-16-1EP_3x3mm_P0.5mm_EP1.7x1.7mm
SOT-23-5
Crystal_SMD_3215-2Pin_3.2x1.5mm
USB-C
LGA-12_2x2mm_P0.5mm
D_SOD-123F
82672Heimdall
Coilcraft-LPS3010
Temporal-Badge-BRAVO_PCB

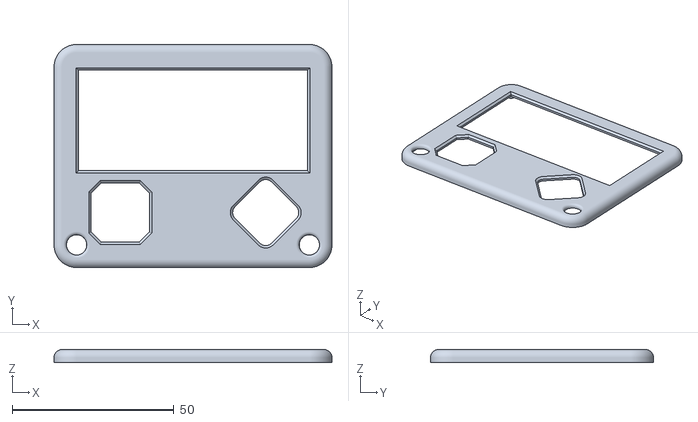
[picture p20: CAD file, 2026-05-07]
hardware/BRAVO/v0_BRAVO-Front-R0.stl
86.0 x 69.0 x 4.00

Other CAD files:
hardware/CHARLIE/assets/V0-CHARLIE_PCB-Outline.FCStd
assets/ST7305.step
hardware/BRAVO/assets/v0_Temporal-Badge-BRAVO-R1.step
assets/Joystick-Outline.FCStd
assets/Joystick-Outline.dxf
assets/OLED 2.42 V1.1 SSD1309.STEP
assets/Temporal-Badge.step
hardware/BRAVO/assets/BETA-Outline-R0.FCStd
hardware/BRAVO/assets/BETA-Outline-R0.dxf
hardware/BRAVO/assets/BRAVO-Outline-R2.dxf
hardware/BRAVO/assets/BRAVO-Outline-R3.dxf
hardware/BRAVO/assets/BRAVO-Outline-R4.dxf
hardware/BRAVO/assets/v0_Temporal-Badge-BRAVO.step
hardware/BRAVO/assets/v0_Temporal-Badge-BRAVO_260219.step
hardware/CHARLIE/assets/V0-CHARLIE_PCB-Outline-R1.dxf
hardware/CHARLIE/assets/V0-CHARLIE_PCB-Outline.dxf

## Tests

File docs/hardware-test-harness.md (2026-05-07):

# Two-Badge Hardware Test Harness

Status: planned, not implemented yet. Use this document plus
`specs/012-hardware-test-harness/spec.md` and
`specs/012-hardware-test-harness/tasks.md` when implementing or resuming after
context compaction.

## Purpose

The hardware harness is for firmware feature development. It should automate as
much of a two-badge physical test pass as possible:

- build and multi-flash the badges;
- control each badge through USB serial and the MicroPython REPL;
- capture raw C++ `Serial` logs and MicroPython output;
- prepare backend state through the sibling `registrationScanner` repo;
- run real physical IR boop tests through the UI path;
- preserve logs and summaries for later review.

The backend test suite already covers backend correctness. These tests should
verify that badge firmware works against the backend and on physical hardware.

## Repos and Targets

- Firmware repo: `Temporal-Badge`
- Backend dependency: sibling repo `../registrationScanner`
- Backend target for integration tests: `https://brooklyn.party`
- Default firmware env: `echo-dev`
- Default flash path: Ignition multi-flash
- Direct PlatformIO upload: fallback only

## Required Hardware Setup

- Two Temporal badges connected over USB serial.
- Badges should be close enough for IR in both directions.
- No external power relay is required for the baseline harness.
- No sacrificial/destructive hardware testing is in scope.

## Flashing Policy

Use Ignition for normal multi-badge flashing:

```bash
cd /Users/shy/Documents/Temporal/replayBadgeOmni/Temporal-Badge/ignition
./start.sh -e echo-dev
```

Useful smoke commands:

```bash
# Verify the Ignition build path without flashing.
cd /Users/shy/Documents/Temporal/replayBadgeOmni/Temporal-Badge/ignition
./start.sh -e echo-dev --build-only

# Flash the already-built image to all connected badges.
cd /Users/shy/Documents/Temporal/replayBadgeOmni/Temporal-Badge/ignition
./start.sh -e echo-dev --no-build

# Verify watch/plug-and-flash behavior for exactly two badges.
cd /Users/shy/Documents/Temporal/replayBadgeOmni/Temporal-Badge/ignition
./start.sh -e echo-dev --watch --no-build --watch-max-badges 2
```

Ignition starts local Temporal and a flash worker, detects all connected badges,
then flashes firmware and the filesystem image in parallel. Review workflow
history at `http://localhost:8233`.

Before flashing, close any serial monitors or harness serial readers. Serial
logging and flashing compete for the same USB ports.

Direct PlatformIO upload remains useful for isolating a single bad port:

```bash
cd /Users/shy/Documents/Temporal/replayBadgeOmni/Temporal-Badge/firmware
/Users/shy/.platformio/penv/bin/pio run -e echo-dev --upload-port /dev/cu.usbmodemXXXX -t upload
```

## Harness Layout

Planned implementation path:

```text
firmware/hardware_tests/
  README.md
  conftest.py
  pytest.ini
  harness/
    backend.py
    ignition.py
    flashing.py
    ports.py
    serial_repl.py
    timeline.py
  test_smoke.py
  test_boop_physical.py
  test_clean_state.py
```

Run shape once implemented:

```bash
cd /Users/shy/Documents/Temporal/replayBadgeOmni/Temporal-Badge/firmware
uv run --with pytest --with pyserial python -m pytest hardware_tests -m hardware
```

Expected options:

- `--env echo-dev`
- `--no-flash`
- `--no-build`
- `--badge-a-port /dev/cu...`
- `--badge-b-port /dev/cu...`

Do not assume PlatformIO's Python can run the pytest harness. It has pyserial
available on this machine, but not pytest. The harness should own or document a
small Python test environment that includes both `pytest` and `pyserial`.

## Serial Control Model

Each badge gets a long-lived serial reader. The serial reader must write every
raw line before trying to parse command responses. C++ logs and MicroPython REPL
responses share the same stream.

Use framed command output:

```python
token = "hb_000123"
send("print('__HB_BEGIN:%s__')" % token)
send("print(repr(badge.dev('uid')))")
send("print('__HB_END:%s__')" % token)
```

Bring the REPL into a known state before each command batch:

1. Open the serial port at 115200 baud.
2. Send `Ctrl-C` twice, then `\r\n`.
3. Wait briefly, then send `import badge`.
4. Use unique sentinels for each command and capture only lines between those
   sentinels.

Do not parse by searching the whole accumulated log from the beginning. Keep a
per-badge cursor or snapshot mark for each wait, otherwise old successful lines
can satisfy a new assertion. The raw log remains the source of truth when the
command capture gets noisy.

Initial firmware control surface in `echo-dev`:

- `badge.dev("uid")`
- `badge.dev("help")`
- `badge.dev("btn", "up|down|left|right")`
- `badge.dev("fb")`
- `badge.dev("send", peer_uid_hex, peer_ticket_uuid, peer_name, body)`

Feature work may add additional `badge.dev(...)` commands behind
`BADGE_ENABLE_MP_DEV` when the test needs to verify protocol/storage behavior
without depending on menu focus. For example, the 1D Chess work used
dev-only `chess_challenge`, `chess_move`, and `chess_resign` helpers to prove
ping/state behavior over USB, while keeping the production `echo` image free of
those hooks.

Useful normal MicroPython functions:

- `my_uuid()`
- `boops()`
- `ir_start()`, `ir_stop()`, `ir_send()`, `ir_read()`
- `ir_send_words()`, `ir_read_words()`, `ir_flush()`

Add new C++ dev commands only when tests cannot be reliable through the current
surface. Always verify both builds:

```bash
cd /Users/shy/Documents/Temporal/replayBadgeOmni/Temporal-Badge/firmware
/Users/shy/.platformio/penv/bin/pio run -e echo-dev
/Users/shy/.platformio/penv/bin/pio run -e echo
```

### USB Serial Lessons From 1D Chess

- `echo-dev` exposes `badge.dev(...)`; normal `echo` does not. If a serial test
  needs dev hooks, flash and verify `echo-dev` on both badges.
- After every flash, reopen the ports and assert `badge.dev("help")` on both
  badges. A stale image on one badge can masquerade as a firmware bug.
- Use explicit ports when known, for example `/dev/cu.usbmodem101` and
  `/dev/cu.usbmodem1101`. Auto-detect is fine only when exactly two candidate
  badge ports are present.
- `badge.dev("fb")` dumps `FB BEGIN`, eight `P0`-`P7` hex rows, then `FB END`.
  This is useful for screenshots/assertions but should not replace state/log
  assertions for protocol tests.
- UI driving with synthetic button presses is appropriate for acceptance tests,
  but it is brittle for deep protocol debugging because menu focus, tutorial
  state, completed rows, and notification screens can change the path. Prefer
  feature-specific dev hooks for deterministic protocol tests, then keep a
  separate UI smoke that opens the real screen and exercises the visible flow.
- Polling pings can take 30 seconds unless a foreground screen has pushed the
  faster Wi-Fi poll interval. Serial tests should wait on log evidence such as
  `route one_d_chess ... actionable=1` rather than fixed sleeps.
- Backend pings persist. Clearing a local game store, especially the `seen`
  list, can make old backend pings reappear. Clean backend rows for the selected
  seed tickets when possible, or send/ingest a terminal ping so stale lower-seq
  events cannot revive an active game.
- For turn-based games, the harness should assert both the HTTP send log
  (`[OneDChess] send ... http=200 ok=1`) and the receiver route log
  (`[WiFi] route one_d_chess ... actionable=...`), then read the on-device JSON
  file to confirm final state.
- Take the receiver's log cursor before issuing the sender command. In the
  full-game 1D Chess QA pass, the peer sometimes routed the ping before the
  sender-side HTTP wait finished, so a cursor taken afterward missed the real
  route line.
- A full-game protocol QA should play until a terminal result, not only through
  resign. The 1D Chess serial pass completed at `seq=6`, `next=255`,
  `result=2` (`BlackMate`), with matching terminal JSON on both badges.
- Local JSON stores use ArduinoJson arenas and may need explicit
  `garbageCollect()` after removes/reorders. Treat `json gc ... reclaimed ...`
  logs as useful evidence that the tested path exercised compaction.
- Opening a MicroPython REPL over USB interrupts app code enough to change
  timing. Keep readers passive whenever possible, and only enter REPL when
  issuing framed commands.

## Log Artifacts

Default log root:

```text
firmware/logs/hardware/
  latest -> runs/<timestamp>/
  runs/<timestamp>/
    manifest.json
    BADGE-A_<usb-serial>.raw.log
    BADGE-B_<usb-serial>.raw.log
    timeline.log
    commands.jsonl
    junit.xml
```

At the start of every test pass, replace `latest` and wipe the current pass's
logs. Preserve older `runs/` unless the user explicitly asks to delete them.

`manifest.json` should include:

- firmware env and git SHA if available;
- Ignition command/result;
- badge ports and USB serial identifiers;
- hardware UID from `badge.dev("uid")`;
- normalized backend badge UUID;
- seed ticket UUIDs used by the test pass;
- backend URL target.

## Backend State Setup

Use the sibling backend repo as the source of truth:

```text
/Users/shy/Documents/Temporal/replayBadgeOmni/registrationScanner
```

Call backend helpers through `uv run` subprocesses from that repo. Do not copy
backend DB config or secrets into the firmware repo.

Known helpers:

- `workflows._shared.normalize_badge_id`
- `workflows.activities.link_badge_to_ticket`
- `workflows.activities.unlink_badge`
- `db.sync_fetchrow`
- `db.sync_execute`

Use TESTREPLAY75 seed tickets from `registrationScanner/seed.sql`. Tests may
reset those seed rows as needed. For physical boop acceptance, do not pre-create
the `badge_boops` row; let the badges create it through the real IR/API path.

For ping-backed feature tests, backend cleanup should remove pings scoped to the
selected seed tickets before a fresh run. When a backend delete helper is not
available, the firmware protocol should have a terminal/dismissed state and the
test should use that terminal event instead of repeatedly clearing local state.

## Required Test Groups

### Preflight

1. Run Ignition `echo-dev` build/multi-flash unless disabled.
2. Detect exactly two badges or use explicit ports.
3. Open serial readers and confirm `badge.dev("help")`.
4. Record distinct badge UIDs.
5. Confirm backend bridge can link and unlink a seed ticket.

### IR Canary

Before physical boop tests, prove badge placement and IR hardware:

1. Badge A receives while badge B sends a simple IR frame.
2. Badge B receives while badge A sends a simple IR frame.
3. Fail or skip physical boop tests with a clear placement/IR message if either
   direction fails.

### Physical Boop Acceptance

1. Link badge A and badge B to two distinct TESTREPLAY75 tickets.
2. Reboot/wait until both badges are paired and on the main menu.
3. Send RIGHT to both badges to enter the first menu item, `Boop`.
4. Wait for `GUI: BoopScreen entered, IR enabled` on both serial logs.
5. Send UP to both badges in a short window.
6. Wait for both badges to reach boop success.
7. Assert `boops()` on both badges includes the peer.
8. Assert backend `badge_boops` has an active row for the two linked tickets.

### Clean-State Acceptance

1. Start with a badge linked and holding non-empty contact/boop state.
2. Unlink the badge in backend state.
3. Reboot or wait for firmware pairing poll.
4. Assert the badge returns to unpaired/QR state.
5. Assert stale `/boops.json` and pending boop API files are removed or reset.

Known firmware gap to check: the current unpair path clears NVS and
`/badgeInfo.txt`, but may leave `/boops.json` and pending boop API journals.

### Ping-Backed Feature Acceptance

For features that use `/api/v1/pings`, such as turn-based games:

1. Start with two linked seed tickets and a known pair/boop relationship.
2. Clean or terminally close prior ping-backed state for those tickets.
3. Drive the user-visible entry path far enough to confirm the screen is
   reachable.
4. Use dev-only protocol hooks, when available, for the deterministic send,
   receive, and end-of-game path.
5. Assert sender HTTP status, receiver route log, local JSON state on both
   badges, notification counts, and absence of unexpected active games.
6. Leave completed state, not active state, so future runs are not blocked by
   the one-active-game-per-peer rule.

## Future-Agent Bootstrap

When resuming this work:

1. Read this document.
2. Read `specs/012-hardware-test-harness/spec.md`.
3. Read `specs/012-hardware-test-harness/plan.md`.
4. Continue from `specs/012-hardware-test-harness/tasks.md`.
5. Check `git status --short` and do not revert unrelated user work.
6. Run Ignition build-only before editing harness code:

```bash
cd /Users/shy/Documents/Temporal/replayBadgeOmni/Temporal-Badge/ignition
./start.sh -e echo-dev --build-only
```

7. If two badges are available and the user is ready to flash, run:

```bash
cd /Users/shy/Documents/Temporal/replayBadgeOmni/Temporal-Badge/ignition
./start.sh -e echo-dev
```

8. Capture all harness output under `firmware/logs/hardware/`.

## Troubleshooting

- Serial open fails: stop `firmware/serial_log.py`, PlatformIO monitor, or any
  prior harness process using the same ports.
- Flashing fails after serial logging: close serial readers before Ignition and
  re-detect ports after flashing.
- Ignition worker fails: inspect `/tmp/temporal-badge-worker.log` and Temporal
  workflow history at `http://localhost:8233`. Start with the parent
  `FlashBadgesWorkflow`, then open the failed badge's `BadgeFlashWorkflow`
  child for the per-badge flash/WiFi result and bounded WiFi log.
- Temporal server fails: inspect `/tmp/temporal-badge-server.log`.
- IR canary fails: move badges closer, align IR sides, and rerun only canary
  before running physical boop acceptance.
- Backend seed exhaustion: reset TESTREPLAY75 seed rows in `registrationScanner`
  or choose explicit seed tickets from `seed.sql`.
- Dev command missing from one badge: confirm that badge was flashed with the
  latest `echo-dev`, then re-run `badge.dev("help")` on both ports.
- A receiver logs an actionable ping but no game appears in its local JSON:
  inspect the incoming payload parsing path for required fields getting
  overwritten during state initialization, then confirm the store save did not
  prune the object as invalid.
- A send succeeds but the peer never reacts: confirm the peer's ticket UUID
  matches the backend-linked ticket, confirm Wi-Fi polling is enabled, and wait
  on the peer's `getPings(type)` log rather than the sender log.

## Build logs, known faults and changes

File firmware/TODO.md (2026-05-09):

TV remote / general IR / copy send app
JumperIDE doom1.wad upload
Credits
3D printed screen retainer
arbitrary QR
Shared drawings / pixchat
All badge chat room
More internet shit

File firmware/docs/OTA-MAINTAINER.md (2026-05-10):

# OTA, Community Apps & Filesystem Sync — Maintainer Guide

This guide explains what a maintainer needs to do to keep firmware
OTA, the Community Apps registry, and the diff-sync engine working
for badges in the field. The three systems share this doc because
they share the same HTTP + SHA-256 transport plumbing, but they're
independent — none of them depends on the others.

> **Heads up**: the registry was renamed from "Asset Library" to
> "Community Apps" in firmware v0.2. The old `asset_registry_url`
> setting + `registry/registry.json` v1 schema still work; new
> badges fetch `registry/community_apps.json` (schema v2) by
> default. See § 4 below for the migration story.

> **Storage model preflight**: read
> [`STORAGE-MODEL.md`](STORAGE-MODEL.md) before changing anything in
> this doc — it explains which tier (NVS / FATFS / app0) each kind
> of flash touches, and which user state survives where.

> **Audience**: you are publishing firmware releases or asset files
> for a fleet of Temporal Replay 2026 badges. Badge users do not need
> any of this; they just need WiFi.

> **Security stance**: this is open-source firmware with no secrets to
> protect. There is no image signing, no certificate pinning, no
> auth. SHA-256 hashes are corruption checks only. The threat model is
> "don't brick the badge", which is mitigated by a battery guard and
> bootloader rollback — not by cryptography. If you want a hardened
> fleet, you'll need to fork the OTA module and bring your own keys.

---

## 1. How firmware OTA works end-to-end

```
┌──────────────────────────────────────────────────────┐
│ Maintainer cuts a GitHub release tag, e.g. v0.2.0.   │
└──────────────────────────────────────────────────────┘
                         │
                         ▼
┌──────────────────────────────────────────────────────┐
│ release-firmware.yml runs:                           │
│   pip install platformio                             │
│   pio run -e echo                                    │
│   upload firmware.bin -> firmware.bin release asset  │
└──────────────────────────────────────────────────────┘
                         │
                         ▼
┌──────────────────────────────────────────────────────┐
│ Badge (any time after, on WiFi):                     │
│   GET api.github.com/repos/<owner>/<repo>/           │
│       releases/latest                                │
│   Compare tag_name vs FIRMWARE_VERSION (semver).     │
│   If newer + matching asset present → cache it.      │
│   Status bar shows down-arrow glyph.                 │
│   Home tile flips to "UPDATE".                       │
└──────────────────────────────────────────────────────┘
                         │
                         ▼
┌──────────────────────────────────────────────────────┐
│ User opens "FW UPDATE" tile → Confirm.               │
│ Badge streams the .bin into the inactive OTA slot,   │
│ ESP.restart()s, and the bootloader picks the new     │
│ image. If the new image fails to boot the bootloader │
│ rolls back automatically.                            │
└──────────────────────────────────────────────────────┘
```

### The naming contract

The badge looks for an asset whose `name` field exactly matches the
`OTA_ASSET_NAME` define in `firmware/platformio.ini`. The default is
`firmware.bin` — same as the local PlatformIO build product, so
JumperIDE and other external tooling can point at the release URL
directly without renaming. If the release has no asset with that
exact name, the badge silently reports `NoMatchingAsset` and the
indicator stays dark — that's the safe failure mode.

### What the version comparison does

`BadgeOTA::compareSemver()` parses both tags as `<major>.<minor>.<patch>`
(stripping a leading `v` if present). Pre-release suffixes like
`-rc1` are ignored — `1.2.3` and `1.2.3-rc1` compare equal. If you
need stricter pre-release ordering, edit `parseSemver` in
`firmware/src/ota/BadgeOTA.cpp`.

### Releasing a new firmware version

1. Bump `firmware/VERSION`:
   ```
   cd firmware && ./scripts/bump_version.sh 0.2.0
   ```
   (or just edit the file by hand).
2. Commit and push.
3. Create a GitHub release tagged `0.2.0` (the leading `v` is
   optional — both work).
4. The `release-firmware.yml` Action runs automatically; within a
   few minutes the release will have a `firmware.bin` asset.
5. Badges in the field will pick it up the next time they hit their
   24h check, or immediately if a user opens **FW UPDATE → Check now**.

If something goes wrong with the Action:

- Check the **Actions** tab on GitHub for failure details.
- You can re-run the Action manually from `workflow_dispatch` —
  pass the existing tag name.
- As a last-ditch fallback, build locally and drop the `.bin` onto
  the release manually:
  ```
  cd firmware && pio run -e echo
  # then upload .pio/build/echo/firmware.bin via the GitHub release
  # UI (must be uploaded with the literal name "firmware.bin").
  ```

### Forking the firmware (different repo / different asset name)

In your fork, edit `firmware/platformio.ini` `[env:echo] build_flags`:

```ini
'-DOTA_GITHUB_REPO="YourOrg/YourBadgeFork"'
'-DOTA_ASSET_NAME="firmware-yourfork.bin"'
```

Update the Action to upload an asset with the matching name. Done.

---

## 2. Asset Registry (DOOM WAD, etc.)

The asset registry is a single JSON file (`registry/registry.json`)
that lists files the badge can fetch on demand. Schema docs are in
[`registry/README.md`](../../registry/README.md).

### Default hosting (no infrastructure)

The firmware's `settings.txt.example` ships with:

```
asset_registry_url = https://raw.githubusercontent.com/Architeuthis-Flux/Temporal-Replay-26-Badge/main/registry/registry.json
```

Anyone with PR access can add an entry. Badges pick up changes within
24 hours of their next refresh.

### Where the actual asset bytes live

There are two normal hosting paths, in order of preference:

1. **GitHub Release attachments via the release-assets pipeline**
   (recommended for files ≳ 100 KB — DOOM WAD lives here). The repo's
   [`release-assets/manifest.json`](../../release-assets/manifest.json)
   declares which files the release Action attaches to every GitHub
   release; the registry's `url` field then points at the stable
   `https://github.com/<owner>/<repo>/releases/latest/download/<name>`
   pattern, which automatically resolves to whatever was attached to
   the most recent release. See
   [`release-assets/README.md`](../../release-assets/README.md) for
   the manifest schema and add-a-new-asset workflow.
2. **External HTTPS host** (Cloudflare R2, your own server, etc.) for
   things you don't want in the GitHub repo at all. See
   [Hosting on Cloudflare](#3-hosting-on-cloudflare) below.

### Adding a new asset (release-bundled path)

1. Drop the file at a sensible local path (or note a `fallback_url`
   that CI can curl). For files committed to the repo, anywhere works
   — for things like the DOOM WAD that we don't want in git history,
   just add a `.gitignore` line pointing at the local copy.
2. Compute the SHA-256:
   ```
   sha256sum path/to/file.bin
   ```
3. Append an entry to
   [`release-assets/manifest.json`](../../release-assets/manifest.json):
   ```json
   {
     "name": "file.bin",
     "local_path": "firmware/data/file.bin",
     "fallback_url": "",
     "registry_id": "my-asset"
   }
   ```
4. Append the matching entry to `registry/registry.json` with
   `url` set to the stable release URL pattern:
   ```json
   {
     "id": "my-asset",
     "name": "My Asset",
     "version": "1.0",
     "url": "https://github.com/Architeuthis-Flux/Temporal-Replay-26-Badge/releases/latest/download/file.bin",
     "sha256": "<hex from step 2>",
     "size": 1234567,
     "dest_path": "/my_asset.bin",
     "min_free_bytes": 1500000,
     "description": "What this is and why I'd want it"
   }
   ```
5. Verify locally before pushing:
   ```
   python3 scripts/stage_release_assets.py --check
   ```
   The script confirms the manifest's files match the registry's
   `sha256` / `size` / `url` fields. Drift = build failure with a
   clear "you forgot to update X" message.
6. PR + merge + cut a release. The release Action attaches the file
   to the release alongside `firmware.bin`. Badges in the field see
   the new entry within 24 h of the next refresh.

### Adding a new asset (external-host path)

Same as the release-bundled path, except step 3 is omitted, the
`url` in step 4 points at your external host, and the release Action
doesn't have to do anything. Use this for files you don't want in the
GitHub repo or that change on a different cadence than firmware
releases.

### Pushing an updated version of an existing asset

Bump the `version` field on the existing registry entry. If the
file's bytes changed, also bump the `sha256` and `size`. The release
Action's `--check` step will catch drift between the file and the
registry on the next release. Badges that already have the asset
installed see the entry flip to "Update" and the user can re-install
over the top.

---

## 3. Hosting on Cloudflare

Cloudflare's free tier covers everything we need: a static
`registry.json` and large binary asset downloads, both with global
edge caching. You have two reasonable options.

### Option A: R2 (object storage) — best for big files

R2 is S3-compatible object storage with **no egress fees**. The
DOOM WAD is 4 MB and a fleet of badges hitting it weekly is well
under a free-tier quota.

1. **Create an R2 bucket.** In the Cloudflare dashboard:
   `R2 → Create bucket → name it e.g. `temporal-badge-assets``.
2. **Make it publicly readable.** R2 buckets are private by default.
   Either:
   - Connect a custom domain (`assets.example.com`) under the bucket
     settings → "Public access". Cloudflare will issue a TLS cert
     automatically and serve the bucket at
     `https://assets.example.com/<key>`.
   - Or enable the auto-generated `r2.dev` subdomain (good for
     testing, has rate limits).
3. **Upload the asset.** Drag a file into the bucket UI, or use
   `wrangler` / `rclone` / any S3-compatible client. The file's
   public URL is `https://<your-domain>/<filename>`.
4. **Update `registry.json`.** Point the entry's `url` at the public
   URL.
5. **(Optional) Configure cache headers.** In the R2 bucket's
   "Settings → Public access → Edit CORS" you can also set
   `Cache-Control` policies. The default 4-hour edge cache is fine
   for assets that change rarely.

### Option B: Cloudflare Pages — best for the registry JSON itself

Pages hosts a static site directly from a Git repo, so you can
serve `registry.json` from a repo that's separate from the firmware
if you want assets to update without touching firmware history.

1. **Create a new repo** with just `registry.json` (and any other
   static files you want to expose).
2. **Cloudflare dashboard** → `Pages → Create project → connect to
   Git → pick your repo`. Build command: leave blank. Output
   directory: `.` (or `/`).
3. **Pages will deploy on every push** to the configured branch.
   The default URL is `<project>.pages.dev`; you can attach a
   custom domain under `Pages → your project → Custom domains`.
4. **Set the badge `asset_registry_url`** (in `settings.txt`) to
   `https://<your-pages-host>/registry.json`.

### Option C: Workers — for advanced routing

If you want per-badge personalization, A/B rollouts, or analytics,
write a Cloudflare Worker that proxies the registry and inspects
the badge's `User-Agent` (`TemporalBadge-OTA/1.0`). Outside the
scope of this doc — see Cloudflare's Workers tutorials.

### A note on caching

Both R2 (with public access) and Pages serve files through
Cloudflare's edge cache by default. If you push a new
`registry.json` and the badge is still seeing the old one:

- **Pages:** purge the project's cache (`Pages → project →
  Caching → Purge cache`) or wait for the default TTL (~30 min).
- **R2 with custom domain:** add a `Cache-Control: max-age=300`
  header at upload time, or use Cloudflare's
  "Cache Rules → Bypass" for that specific URL while iterating.
- The badge ignores HTTP cache headers — it has its own 24h
  cooldown — so the cache only matters when a user hits
  "Refresh" from the Asset Library screen.

### Verifying it works

From any browser:

```
curl -i https://your-host/registry.json
```

Should return `200 OK`, `Content-Type: application/json`, and the
JSON body. If the badge is still ignoring it, check on-device serial
logs for `[registry]` lines — they include the URL fetched and the
parse result.

---

## 4. Bootstrapping the very first release

The current 0.1.4 release predates this OTA work and won't have a
`firmware.bin` asset. To get badges actually upgrading:

1. **Either** cut a 0.1.5+ tag — the new Action will publish the
   `.bin` automatically.
2. **Or** manually attach `firmware.bin` to the existing 0.1.4
   release via the GitHub web UI.

Until one of those happens, badges on 0.1.4 will silently report
`NoMatchingAsset` against 0.1.4 and the update indicator stays dark
— which is the correct, safe behavior.

---

## 5. Partition layout (16 MB flash)

There are **two partition layouts** in the tree. Which one a badge
uses is determined entirely at flash time — neither layout is OTA-
upgradable to the other (the partition table itself lives at flash
offset 0x8000 and is never rewritten by an OTA app-slot install).

### Default — `partitions_replay_16MB_doom.csv` (production, OTA path)

| Region | Offset | Size | Purpose |
|---|---|---|---|
| boot+ptab | 0x000000  | 36 KB | bootloader + partition table |
| nvs | 0x009000  | 20 KB | preferences (incl. `badge_ota`) |
| otadata | 0x00E000  | 8 KB | bootloader's slot pointer |
| **app0**  | 0x010000  | **3.84 MB** | OTA slot A (currently ~74 % full) |
| **app1**  | 0x3F0000  | **3.84 MB** | OTA slot B |
| **ffat**  | 0x7D0000  | **6 MB** | user filesystem |
| (gap) | 0xDD0000  | 2 MB | unused — reserved for future bumps |
| coredump  | 0xFD0000  | 64 KB | panic dumps |

**This is what every shipped badge runs and what `firmware.bin` on
the GitHub release is built against.** Keep it that way unless you
also want to manage a parallel asset stream — `[env:echo]` in
[firmware/platformio.ini](../platformio.ini) points at this file and
the release Action builds for this layout exclusively.

### Opt-in — `partitions_replay_16MB_ver2.csv` (expanded, USB only)

| Region | Offset | Size | Purpose |
|---|---|---|---|
| boot+ptab | 0x000000  | 36 KB | bootloader + partition table |
| nvs | 0x009000  | 20 KB | |
| otadata | 0x00E000  | 8 KB | |
| **app0**  | 0x010000  | **4.5 MB**  | OTA slot A (currently ~64 % full)  |
| **app1**  | 0x490000  | **4.5 MB**  | OTA slot B |
| **ffat**  | 0x910000  | **6.875 MB** | user filesystem |
| coredump  | 0xFF0000  | 64 KB | |

Bigger OTA slots (more headroom for future firmware bloat) and a
larger ffat (more room for assets / contacts). Reclaims the 2 MB gap.

### How a user opts in

The partition table is at flash offset 0x8000 and `pio run -t upload`
only writes the OTA app slot — it doesn't rewrite the partition
table. So the only safe way to switch a badge from `_doom` to `_ver2`
is a full chip erase + reflash over USB:

```
cd firmware && ./scripts/erase_and_flash_expanded.sh
```

The script triple-confirms because it wipes everything (contacts,
nametag, settings, WAD, WiFi credentials). After the reflash, the
user re-enters WiFi via Settings → WiFi Setup, and downloaded assets
re-fetch from the Asset Library tile.

### What about OTA after opting in?

**For now, opting in means leaving the OTA path.** The release Action
publishes one asset (`firmware.bin`) built for the `_doom` layout. An
expanded badge that pulls that asset would mis-align ffat and possibly
overflow into the wrong region — definitely a bricking risk.

**Detection:** the badge's `BADGE_PARTITIONS_EXPANDED` build symbol
identifies expanded firmware at compile time, and at runtime
`ffatPartitionBytes()` returns the actual partition size. The OTA
module currently doesn't consume this — `installCached()` just
streams whatever URL is cached. Future work, in priority order:

1. **Fail-safe gate (cheapest)**: in `BadgeOTA::installCached()`,
   compare the running build's partition size against a constant
   baked into the asset (or a value embedded in a sidecar
   `manifest.json`) and refuse to install when they disagree. Today
   an expanded badge would silently flash a `_doom`-built asset.
2. **Dual-asset OTA (full fix)**: the release Action builds both
   `pio run -e echo` and `pio run -e echo-expanded`, uploads
   `firmware.bin` and `firmware-expanded.bin`. The badge picks based
   on `#ifdef BADGE_PARTITIONS_EXPANDED` (which would override
   `OTA_ASSET_NAME`). Cost: ~2× the Action time and a manifest
   update.

Until either of those ships, a badge that runs the expanded build
should stay on the build it was flashed with — communicate this to
opt-in users.

### "Expand storage" affordance

The FW UPDATE screen has a latent "Expand storage" prompt (press X)
that triggers when the FATFS volume is meaningfully smaller than the
partition. With the current setup it doesn't fire on either layout
(both ffat volumes match their partitions on a fresh flash). It's
kept for future scenarios where a partition bump *is* OTA-deliverable
(see "Dual-asset OTA" above) or where a different partition table
ships with a wider ffat than the existing FAT volume header.

### Initial-filesystem footnote

The contents of `firmware/initial_filesystem/` get baked into the
firmware binary as `StartupFilesData.h` (so they take app-slot space)
AND copied to ffat by `provisionStartupFiles()` on first boot (so
they take ffat space too). It's accepted overhead — trades flash
space for a guaranteed-good first-boot filesystem even if ffat is
wiped.

## 5a. Factory FATFS provisioning via uploadfs

Every badge needs a populated FATFS partition before users can run
apps, see docs, browse images, or play DOOM. There are two ways to
get there at flash time:

```bash
# Single-badge dev flow:
cd firmware
~/.platformio/penv/bin/pio run -e <env> -t uploadfs

# Batch / factory flow:
cd firmware
python3 flash_loop_gui2.py <env>
```

`pio run -t uploadfs` writes a `fatfs.bin` built from `firmware/data/`
(itself a generated mirror of `firmware/initial_filesystem/`) and
flashes it to the `ffat` partition. Everything in the source tree
ships, including:

- `/lib/*.py`  (bake set + `badge_kv.py`)
- `/matrixApps/*.py`
- `/apps/<app>/**`
- `/docs/*.md`, `/images/*.png`, `/messages.json`
- `/API_REFERENCE.md`
- `/doom1.wad`  ← 4 MB; this is the canonical install path. Excluded
  from `manifest.json` because pushing 4 MB over the raw REPL takes
  forever — but `uploadfs` writes it directly. Users without
  PlatformIO can also pull it from `Community Apps → DOOM 1
  Shareware WAD` over WiFi.

> **Critical: use the bundled `pio` binary.** The macOS / micromamba /
> pyenv shim path frequently resolves `pio` to a Python without
> `platformio` installed. Always invoke
> `~/.platformio/penv/bin/pio` directly (or `cd ignition && ./start.sh`
> which handles the path itself). Symptom: `ModuleNotFoundError: No
> module named 'platformio'`.

After a factory uploadfs the FATFS tree is byte-identical to
`firmware/data/` — `badge_sync diff` should show zero missing/stale
entries.

## 5b. Filesystem diff-sync (`badge_sync.py`)

`firmware/scripts/badge_sync.py` is the canonical engine for getting
non-baked files (apps, docs, images) onto a badge **without** doing
a `fatfs.bin` reflash. It's used by:

| Caller | Invocation |
|---|---|
| Operator CLI | `python3 -m badge_sync sync /dev/cu.usbmodemXXXX` |
| PlatformIO | `pio run -t fssync` *(planned target)* |
| flash_loop_gui2 | add `--post-sync` flag to the existing GUI |
| Ignition | `sync_badge_filesystem` Temporal activity (registered in `flash_worker/worker.py`) |
| JumperIDE | "Sync Filesystem" button (TS port of the same protocol) |

All five paths consume the **same** `firmware/data/manifest.json`
generated by `scripts/generate_startup_files.py`. The wire protocol
is the MicroPython raw REPL (Ctrl-A / Ctrl-D), the same protocol
mpremote and JumperIDE already speak.

### How it works

1. `list_badge(port)` → enters raw REPL, sends a 25-line walker that
   prints `f|<path>|<size>|0xFNV` for every file on `/`.
2. `diff(badge, manifest)` → buckets paths into
   `missing` / `stale` / `unchanged` / `extras`.
3. `push_files(...)` → for each path, base64-chunks the bytes and
   feeds them to a small `_put(path)` script via `input()`. Atomic
   write via `<path>.tmp` → `os.rename`.
4. Optional `clear_paths(...)` → `os.remove(path)` over the same REPL.

### When operators should run it

- **Refresh flashes** that only update `app0` (e.g. `./start.sh`):
  the FATFS partition is untouched, so user uploads survive — but
  any new files added to `firmware/data/` since the badge was last
  factory-flashed are missing. Run sync to top them up.
- **Recovery flashes** after a corrupted FATFS or accidental
  `os.remove("/lib/...")`: the bake set + sync gets you back to a
  full filesystem.
- **Field demos** where re-uploading `fatfs.bin` (which wipes user
  files) is too aggressive.

### When operators should *not* run it

- **Factory flashes via `flash_loop_gui2.py`** already write
  `fatfs.bin` in the same `esptool` batch as the firmware. Running
  sync afterwards is redundant unless you've changed `firmware/data/`
  since `pio run -t buildfs` last ran.

### NVS state is invariant

Crucially, `badge_sync` only touches FATFS — never NVS. Operator
state (badge UID, contacts, badgeInfo, `badge.kv` saves) is preserved
across every sync, even `--clear-extras`.

---

## 6. Things that go wrong (and what to do)

| Symptom (on badge serial) | Likely cause | Fix |
|---|---|---|
| `wifi unavailable` | No WiFi credentials, or auth failed | Settings → WiFi Setup → re-enter |
| `http status 404` | Asset URL changed | Update `registry/community_apps.json` |
| `community_apps_url not configured` | Settings cleared the URL | Restore via Settings or re-flash defaults |
| badge_sync `could not enter raw REPL` | App still running, or REPL is wedged | Press Ctrl+C in JumperIDE, retry |
| badge_sync `manifest path not on disk: ...` | `firmware/data/manifest.json` is stale | Re-run `scripts/generate_startup_files.py` |
| `release X has no 'firmware-...'` | Action didn't run, or asset name mismatch | Re-run Action / fix `OTA_ASSET_NAME` |
| `sha256 mismatch` | File served by host changed without version bump | Re-upload + bump `version` |
| `Update.begin failed: ...` | Image larger than the OTA partition (4 MB) | Trim build / reduce features |
| `battery too low — plug in` | Battery <30% and no charger | Plug in USB |
| `stream short N/M` | Bad WiFi mid-flash | Try again |

The Update screen surfaces the underlying error message verbatim, so
users can include it in bug reports.

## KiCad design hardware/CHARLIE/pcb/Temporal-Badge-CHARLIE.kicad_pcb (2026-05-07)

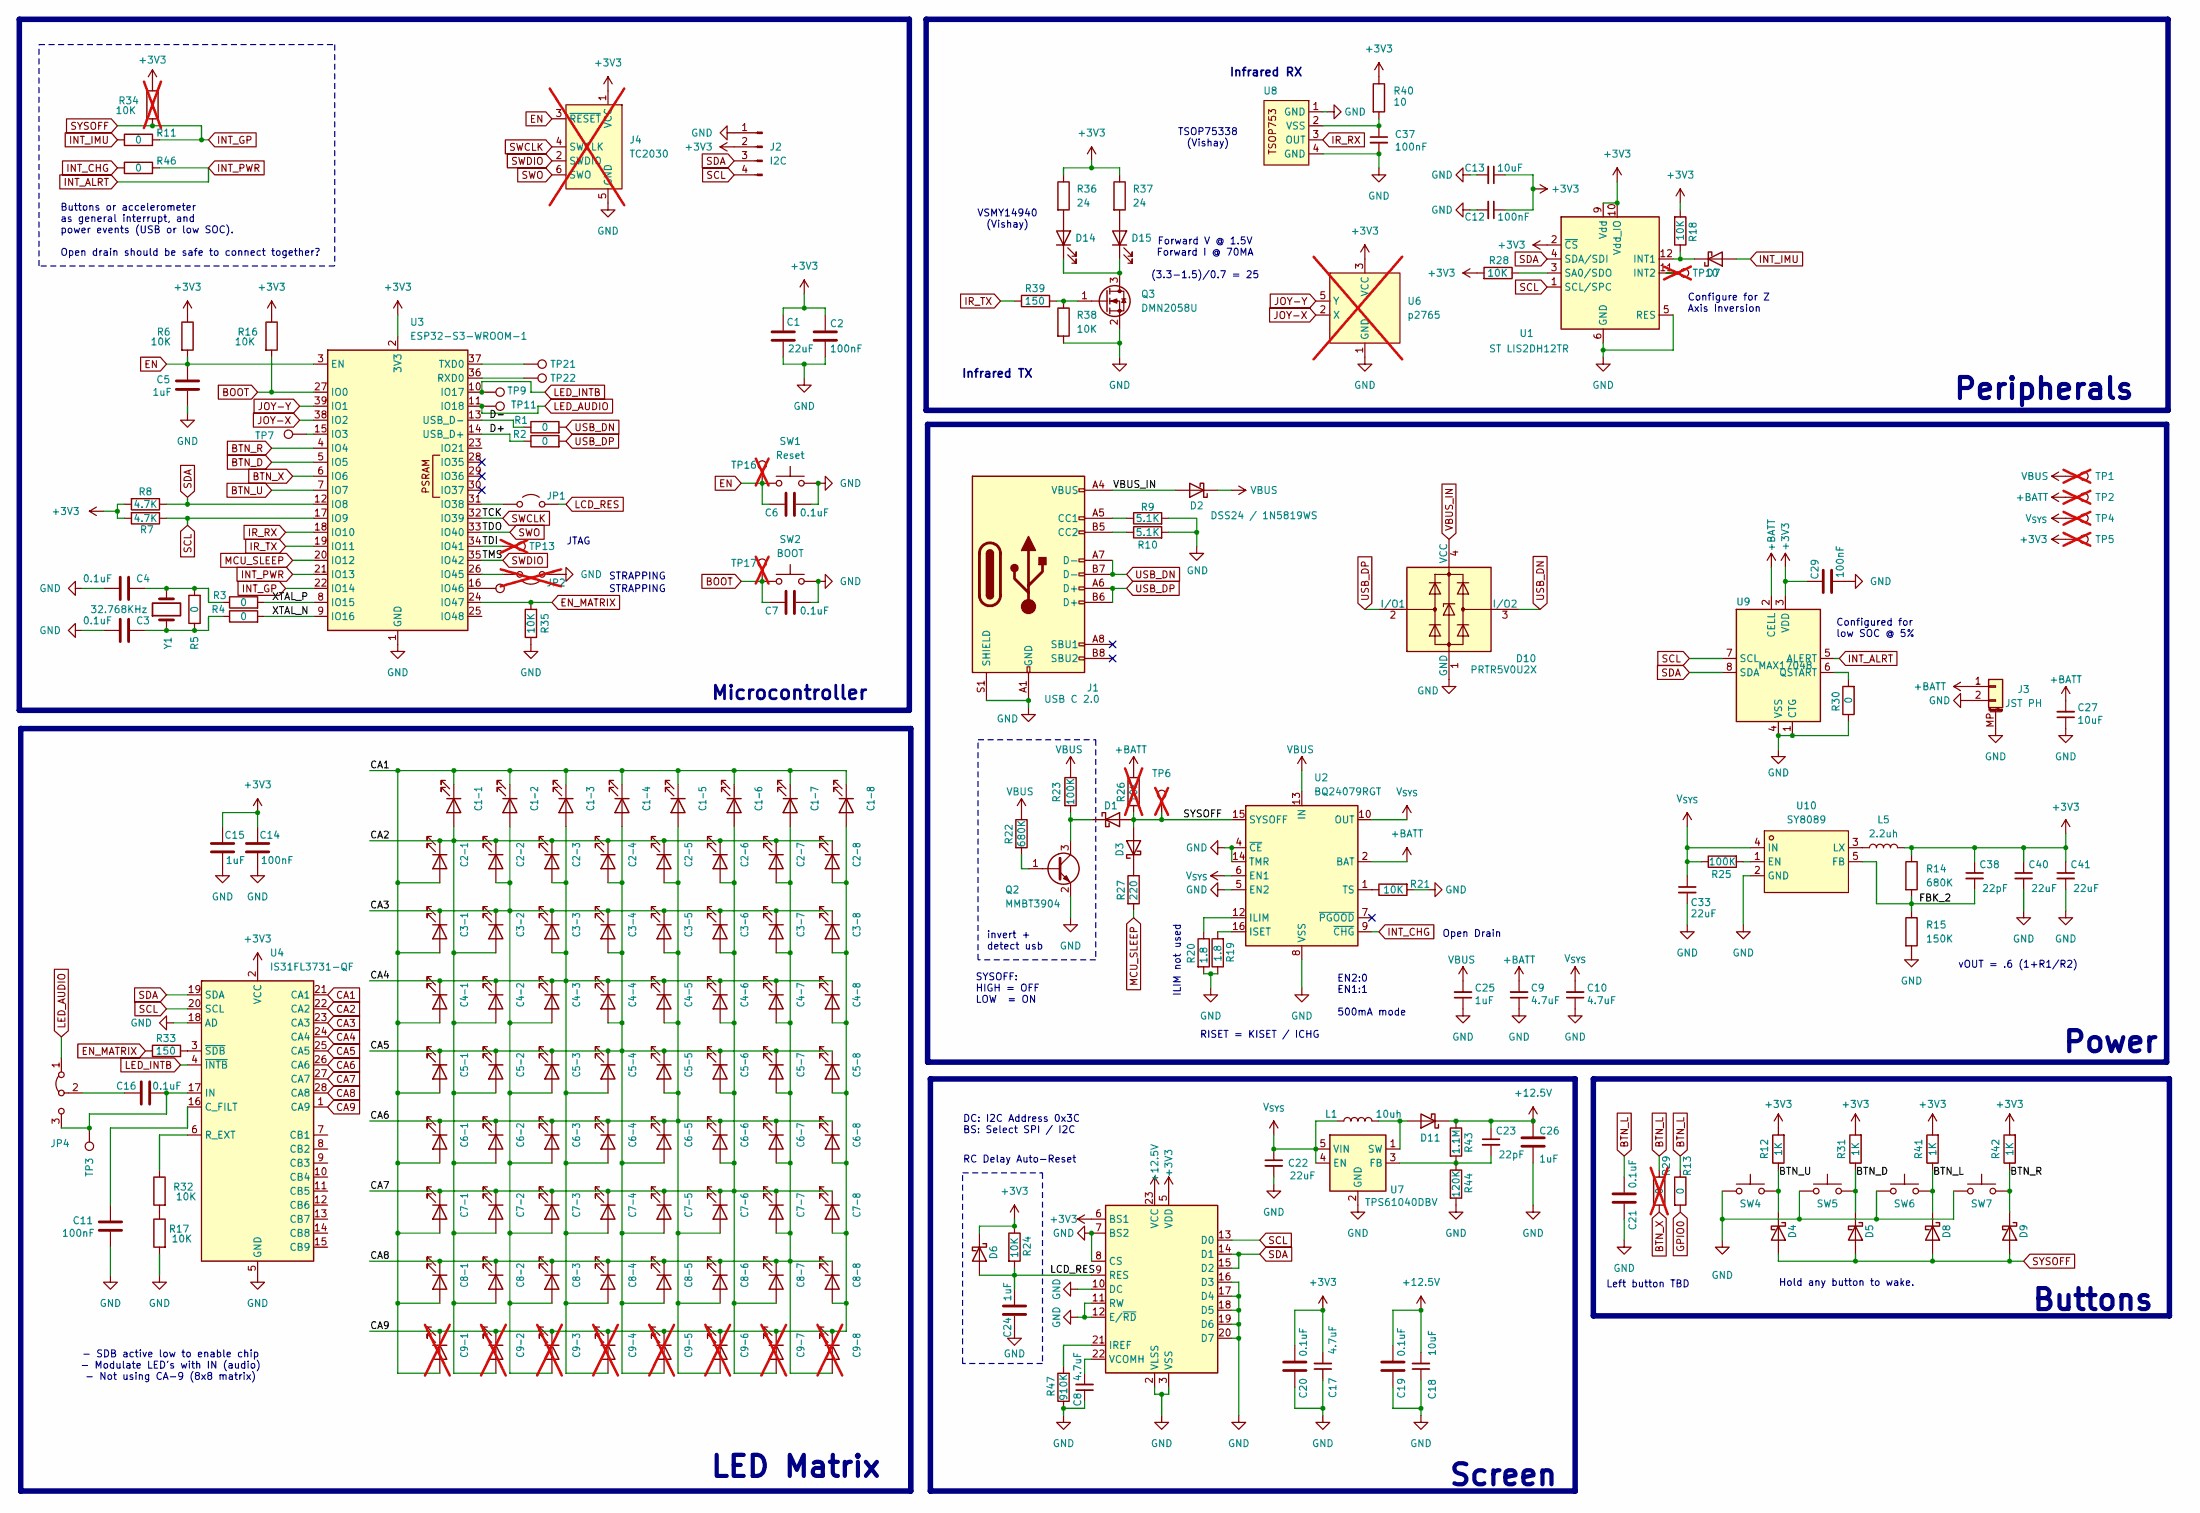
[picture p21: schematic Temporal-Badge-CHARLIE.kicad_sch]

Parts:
C1, C22, C33, C40, C41: 22uF; C_0402_1005Metric; LCSC C3845593
C1-1, C1-2, C1-3, C1-4, C1-5, C1-6, C1-7, C1-8, C2-1, C2-2, C2-3, C2-4, C2-5, C2-6, C2-7, C2-8, C3-1, C3-2, C3-3, C3-4, C3-5, C3-6, C3-7, C3-8, C4-1, C4-2, C4-3, C4-4, C4-5, C4-6, C4-7, C4-8, C5-1, C5-2, C5-3, C5-4, C5-5, C5-6, C5-7, C5-8, C6-1, C6-2, C6-3, C6-4, C6-5, C6-6, C6-7, C6-8, C7-1, C7-2, C7-3, C7-4, C7-5, C7-6, C7-7, C7-8, C8-1, C8-2, C8-3, C8-4, C8-5, C8-6, C8-7, C8-8: LED0603_NOOUTLINE; CHIPLED_0603_NOOUTLINE; LCSC C19171390
C2, C11, C12, C14, C29, C37: 100nF; C_0402_1005Metric; LCSC C1525
C3, C4, C6, C7, C16, C19, C20, C21: 0.1uF; C_0402_1005Metric; LCSC C1525
C5, C15, C24, C25: 1uF; C_0402_1005Metric; LCSC C14445
C8, C9, C10, C17: 4.7uF; C_0402_1005Metric; LCSC C315248
C9-1, C9-2, C9-3, C9-4, C9-5, C9-6, C9-7, C9-8: LED0603_NOOUTLINE; CHIPLED_0603_NOOUTLINE; not fitted
C13, C18, C27: 10uF; C_0402_1005Metric; LCSC C315248
C23, C38: 22pF; C_0402_1005Metric; LCSC C76960
C26: 1uF; C_0402_1005Metric; LCSC C1525
D1, D3, D4, D5, D6, D7, D8, D9, D11: D_Schottky; D_SOD-523; LCSC C917006
D2: DSS24 / 1N5819WS; D_SOD-123F; LCSC C511865
D10: PRTR5V0U2X; SOT-143; LCSC C5180302
D14, D15: VSMY14940; vsmy14940; LCSC C511069
J1: USB C 2.0; USB_C_Receptacle_Palconn_UTC16-G; LCSC C2765186
J2: I2C; PinSocket_1x04_P2.54mm_Vertical
J3: JST PH; JST_PH_S2B-PH-SM4-TB_1x02-1MP_P2.00mm_Horizontal; LCSC C295747
J4: TC2030; Tag-Connect_TC2030-IDC-NL_2x03_P1.27mm_Vertical; not fitted
JP1: Jumper_2_Open; SolderJumper-2_P1.3mm_Open_RoundedPad1.0x1.5mm
JP2: Jumper_2_Open; SolderJumper-2_P1.3mm_Open_RoundedPad1.0x1.5mm; not fitted
JP4: Jumper_3_Bridged12; SolderJumper-3_P1.3mm_Bridged12_Pad1.0x1.5mm
L1: 10uh; L_Coilcraft_LPS3010; LCSC C2926400
L5: 2.2uh; L_Coilcraft_LPS3010; LCSC C2926400
Q2: MMBT3904; SOT-23; LCSC C916374
Q3: DMN2058U; SOT-23; LCSC C461001
R1, R2, R3, R4, R5, R11, R13, R30, R46: 0; R_0201_0603Metric; LCSC C106228
R6, R16, R17, R18, R21, R24, R28, R32, R35, R38: 10K; R_0402_1005Metric; LCSC C60490
R7, R8: 4.7K; R_0402_1005Metric; LCSC C105871
R9, R10: 5.1K; R_0402_1005Metric; LCSC C25905
R12, R31, R41, R42: 1K; R_0402_1005Metric; LCSC C106235
R14, R22: 680K; R_0402_1005Metric; LCSC C163456
R15: 150K; R_0402_1005Metric; LCSC C93947
R19, R20: 1.8; R_0402_1005Metric; LCSC C203083
R23, R25: 100K; R_0402_1005Metric; LCSC C60491
R26: 10K; R_0402_1005Metric; LCSC C25767; not fitted
R27: 220; R_0402_1005Metric; LCSC C112291
R29: 0; R_0201_0603Metric; LCSC C106228; not fitted
R33, R39: 150; R_0402_1005Metric; LCSC C138054
R34: 10K; R_0402_1005Metric; LCSC C60490; not fitted
R36, R37: 24; R_0805_2012Metric; LCSC C270625
R40: 10; R_0402_1005Metric; LCSC C138066
R43: 1.1M; R_0402_1005Metric; LCSC C163456
R44: 120K; R_0402_1005Metric; LCSC C93947
R47: 910K; R_0402_1005Metric; LCSC C163456
SW1: Reset; SW_SPST_B3U-1000P-B; LCSC C231329
SW2: BOOT; Panasonic_EVQPUM_EVQPUD; LCSC C79174
SW4, SW5, SW6, SW7: SW_Push; SW_Push_1TS009xxxx-xxxx-xxxx_6x6x5mm; LCSC C25168849
TP1, TP2, TP4, TP5, TP6, TP10, TP13, TP16, TP17: TestPoint; TestPoint_Pad_D1.0mm; not fitted
TP3, TP7, TP8, TP9, TP11, TP21, TP22: TestPoint; TestPoint_Pad_D1.0mm
U1: ST LIS2DH12TR; LGA-12_2x2mm_P0.5mm; LCSC C110926
U2: BQ24079RGT; VQFN-16-1EP_3x3mm_P0.5mm_EP1.6x1.6mm; LCSC C2876751
U3: ESP32-S3-WROOM-1; LCSC C2913202
U4: IS31FL3731-QF; QFN-28-1EP_4x4mm_P0.4mm_EP2.3x2.3mm; LCSC C191206
U5: (no value)
U6: p2765; JOYSTICK_ANALOG_MINITHM; not fitted
U7: TPS61040DBV; SOT-23-5
U8: TSOP75338; TSOP753; LCSC C499550
U9: MAX17048; TDFN-8-1EP_2x2mm_P0.5mm_EP0.8x1.2mm; LCSC C2682616
U10: SY8089; SOT-23-5; LCSC Part C79313
Y1: 32.768KHz; Crystal_SMD_3215-2Pin_3.2x1.5mm; LCSC C97606

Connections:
+3V3: C1.1, C2.1, C12.1, C13.1, C14.1, C15.1, C17.2, C20.2, C29.1, C38.1, C40.1, C41.1, D6.1 (K), J2.2, J4.1 (VCC), L5.2, R6.1, R7.2, R8.2, R12.2, R14.1, R16.1, R18.2, R24.1, R28.2, R31.2, R34.1, R36.1, R37.1, R40.1, R41.2, R42.2, TP5.1, U1.2 (~CS), U1.9 (Vdd), U1.10 (Vdd_IO), U3.2 (3V3), U4.2 (VCC), U5.5 (VDD), U5.6 (BS1), U6.3 (VCC), U6.4 (VCC), U9.3 (VDD)
+12.5V: C18.2, C19.2, C23.1, C26.2, D11.1 (K), R43.1, U5.23 (VCC)
+BATT: C9.2, C27.2, J3.1, R26.1, TP2.1, U2.2 (BAT), U2.3 (BAT), U9.2 (CELL)
/D+: R2.1, U3.14 (USB_D+)
/D-: R1.1, U3.13 (USB_D-)
/FBK_2: C38.2, R14.2, R15.1, U10.5 (FB)
/TDI: TP13.1, U3.34 (IO41)
/XTAL_N: R4.2, U3.9 (IO16)
/XTAL_P: R3.2, U3.8 (IO15)
BOOT: C7.1, R16.2, SW2.2, TP17.1, U3.27 (IO0)
BTN_D: D5.1 (K), R31.1, SW5.2, U3.5 (IO5)
BTN_L: C21.2, D8.1 (K), R13.1, R29.1, R41.1, SW6.2
BTN_R: D9.1 (K), R42.1, SW7.2, U3.4 (IO4)
BTN_U: D4.1 (K), R12.1, SW4.2, U3.7 (IO7)
BTN_X: R29.2, U3.6 (IO6)
CA1: C1-1.1 (K), C1-2.1 (K), C1-3.1 (K), C1-4.1 (K), C1-5.1 (K), C1-6.1 (K), C1-7.1 (K), C1-8.1 (K), C2-1.2 (A), C3-1.2 (A), C4-1.2 (A), C5-1.2 (A), C6-1.2 (A), C7-1.2 (A), C8-1.2 (A), C9-1.2 (A), U4.21 (CA1)
CA2: C1-1.2 (A), C2-1.1 (K), C2-2.1 (K), C2-3.1 (K), C2-4.1 (K), C2-5.1 (K), C2-6.1 (K), C2-7.1 (K), C2-8.1 (K), C3-2.2 (A), C4-2.2 (A), C5-2.2 (A), C6-2.2 (A), C7-2.2 (A), C8-2.2 (A), C9-2.2 (A), U4.22 (CA2)
CA3: C1-2.2 (A), C2-2.2 (A), C3-1.1 (K), C3-2.1 (K), C3-3.1 (K), C3-4.1 (K), C3-5.1 (K), C3-6.1 (K), C3-7.1 (K), C3-8.1 (K), C4-3.2 (A), C5-3.2 (A), C6-3.2 (A), C7-3.2 (A), C8-3.2 (A), C9-3.2 (A), U4.23 (CA3)
CA4: C1-3.2 (A), C2-3.2 (A), C3-3.2 (A), C4-1.1 (K), C4-2.1 (K), C4-3.1 (K), C4-4.1 (K), C4-5.1 (K), C4-6.1 (K), C4-7.1 (K), C4-8.1 (K), C5-4.2 (A), C6-4.2 (A), C7-4.2 (A), C8-4.2 (A), C9-4.2 (A), U4.24 (CA4)
CA5: C1-4.2 (A), C2-4.2 (A), C3-4.2 (A), C4-4.2 (A), C5-1.1 (K), C5-2.1 (K), C5-3.1 (K), C5-4.1 (K), C5-5.1 (K), C5-6.1 (K), C5-7.1 (K), C5-8.1 (K), C6-5.2 (A), C7-5.2 (A), C8-5.2 (A), C9-5.2 (A), U4.25 (CA5)
CA6: C1-5.2 (A), C2-5.2 (A), C3-5.2 (A), C4-5.2 (A), C5-5.2 (A), C6-1.1 (K), C6-2.1 (K), C6-3.1 (K), C6-4.1 (K), C6-5.1 (K), C6-6.1 (K), C6-7.1 (K), C6-8.1 (K), C7-6.2 (A), C8-6.2 (A), C9-6.2 (A), U4.26 (CA6)
CA7: C1-6.2 (A), C2-6.2 (A), C3-6.2 (A), C4-6.2 (A), C5-6.2 (A), C6-6.2 (A), C7-1.1 (K), C7-2.1 (K), C7-3.1 (K), C7-4.1 (K), C7-5.1 (K), C7-6.1 (K), C7-7.1 (K), C7-8.1 (K), C8-7.2 (A), C9-7.2 (A), U4.27 (CA7)
CA8: C1-7.2 (A), C2-7.2 (A), C3-7.2 (A), C4-7.2 (A), C5-7.2 (A), C6-7.2 (A), C7-7.2 (A), C8-1.1 (K), C8-2.1 (K), C8-3.1 (K), C8-4.1 (K), C8-5.1 (K), C8-6.1 (K), C8-7.1 (K), C8-8.1 (K), C9-8.2 (A), U4.28 (CA8)
CA9: C1-8.2 (A), C2-8.2 (A), C3-8.2 (A), C4-8.2 (A), C5-8.2 (A), C6-8.2 (A), C7-8.2 (A), C8-8.2 (A), C9-1.1 (K), C9-2.1 (K), C9-3.1 (K), C9-4.1 (K), C9-5.1 (K), C9-6.1 (K), C9-7.1 (K), C9-8.1 (K), U4.1 (CA9)
EN: C5.1, C6.1, J4.3 (~RESET), R6.2, SW1.2, TP16.1, U3.3 (EN)
EN_MATRIX: R33.1, R35.2, U3.24 (IO47)
GND: C1.2, C2.2, C3.2, C4.2, C5.2, C6.2, C7.2, C8.1, C9.1, C10.1, C11.2, C12.2, C13.2, C14.2, C15.2, C17.1, C18.1, C19.1, C20.1, C21.1, C22.2, C24.2, C25.1, C26.1, C27.1, C29.2, C33.2, C37.2, C40.2, C41.2, D10.1 (GND), J1.A1 (GND), J1.A12 (GND), J1.B1 (GND), J1.B12 (GND), J1.S1 (SHIELD), J2.1, J3.2, J3.MP (MountPin), J4.5 (GND), JP2.2 (B), Q2.2 (E), Q3.2 (S), R9.2, R10.2, R15.2, R17.2, R19.1, R20.2, R21.2, R30.1, R35.1, R38.2, R44.2, R47.1, SW1.1, SW2.1, SW4.1, SW5.1, SW6.1, SW7.1, U1.5 (RES), U1.6 (GND), U1.7 (GND), U1.8 (GND), U2.4 (~CE), U2.5 (EN2), U2.8 (VSS), U2.14 (TMR), U2.17 (VSS), U3.1 (GND), U3.40 (GND), U3.41 (GND), U4.5 (GND), U4.18 (AD), U4.29 (GND), U5.1 (NC), U5.2 (VLSS), U5.3 (VSS), U5.4 (NC), U5.7 (BS2), U5.8 (CS), U5.10 (DC), U5.11 (RW), U5.12 (E/~RD), U5.16 (D3), U5.17 (D4), U5.18 (D5), U5.19 (D6), U5.20 (D7), U5.24 (NC), U6.1 (GND), U6.6 (GND), U7.2 (GND), U8.1 (GND), U8.4 (GND), U9.1 (CTG), U9.4 (VSS), U9.9 (VSS), U10.2 (GND)
GPIO0: R13.2
INT_ALRT: R46.2, U3.21 (IO13), U9.5 (ALERT)
INT_CHG: R46.1, U2.9 (~CHG)
INT_GP: D1.2 (A), D3.2 (A), D4.2 (A), D5.2 (A), D8.2 (A), D9.2 (A), R11.2, R26.2, R34.2, TP6.1, U2.15 (SYSOFF), U3.22 (IO14)
INT_IMU: D7.2 (A), R11.1
IR_RX: U3.18 (IO10), U8.3 (OUT)
IR_TX: R39.1, U3.19 (IO11)
JOY-X: U3.38 (IO2), U6.2 (X)
JOY-Y: U3.39 (IO1), U6.5 (Y)
LCD_RES: C24.1, D6.2 (A), JP1.2 (B), R24.2, U5.9 (RES)
LED_AUDIO: JP4.1 (A), TP11.1, U3.11 (IO18)
LED_INTB: TP9.1, U3.10 (IO17), U4.4 (~INTB)
MCU_SLEEP: R27.2, U3.20 (IO12)
unnamed: C3.1, R4.1, R5.1, Y1.1
unnamed: C4.1, R3.1, R5.2, Y1.2
unnamed: D1.1 (K), Q2.3 (C), R23.2
unnamed: D3.1 (K), R27.1
unnamed: D7.1 (K), R18.1, U1.12 (INT1)
unnamed: D11.2 (A), L1.2, U7.1 (SW)
unnamed: D14.2 (A), R36.2
unnamed: D14.1 (K), D15.1 (K), Q3.3 (D)
unnamed: D15.2 (A), R37.2
unnamed: J1.A5 (CC1), R9.1
unnamed: J1.B5 (CC2), R10.1
unnamed: JP1.1 (A), U3.31 (IO38)
unnamed: JP2.1 (A), U3.26 (IO45)
unnamed: C16.2, JP4.3 (B), TP3.1, U4.17 (IN)
unnamed: C16.1, JP4.2 (C)
unnamed: Q2.1 (B), R22.2
unnamed: Q3.1 (G), R38.1, R39.2
unnamed: R17.1, R32.2
unnamed: TP10.1, U1.11 (INT2)
unnamed: R28.1, U1.3 (SA0/SDO)
unnamed: R20.1, U2.12 (ILIM)
unnamed: R19.2, U2.16 (ISET)
unnamed: R21.1, U2.1 (TS)
unnamed: TP7.1, U3.15 (IO3)
unnamed: TP8.1, U3.16 (IO46)
unnamed: TP22.1, U3.36 (RXD0)
unnamed: TP21.1, U3.37 (TXD0)
unnamed: C11.1, U4.16 (C_FILT)
unnamed: R32.1, U4.6 (R_EXT)
unnamed: R33.2, U4.3 (~SDB)
unnamed: R47.2, U5.21 (IREF)
unnamed: C8.2, U5.22 (VCOMH)
unnamed: C23.2, R43.2, R44.1, U7.3 (FB)
unnamed: C37.1, R40.2, U8.2 (VSS)
unnamed: R30.2, U9.6 (QSTART)
unnamed: R25.2, U10.1 (EN)
unnamed: L5.1, U10.3 (LX)
SCL: J2.4, R7.1, U1.1 (SCL/SPC), U3.17 (IO9), U4.20 (SCL), U5.13 (D0), U9.7 (SCL)
SDA: J2.3, R8.1, U1.4 (SDA/SDI), U3.12 (IO8), U4.19 (SDA), U5.14 (D1), U5.15 (D2), U9.8 (SDA)
SWCLK: J4.4 (SWCLK), U3.32 (IO39)
SWDIO: J4.2 (SWDIO), U3.35 (IO42)
SWO: J4.6 (SWO), U3.33 (IO40)
USB_DN: D10.3 (I/O2), J1.A7 (D-), J1.B7 (D-), R1.2
USB_DP: D10.2 (I/O1), J1.A6 (D+), J1.B6 (D+), R2.2
VBUS: C25.2, D2.1 (K), R22.1, R23.1, TP1.1, U2.13 (IN)
VBUS_IN: D2.2 (A), D10.4 (VCC), J1.A4 (VBUS), J1.A9 (VBUS), J1.B4 (VBUS), J1.B9 (VBUS)
V_{SYS}: C10.2, C22.1, C33.1, L1.1, R25.1, TP4.1, U2.6 (EN1), U2.10 (OUT), U2.11 (OUT), U7.4 (EN), U7.5 (VIN), U10.4 (IN)

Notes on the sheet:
Power
Buttons or accelerometer as general interrupt, and power events (USB or low SOC). Open drain should be safe to connect together?
RISET = KISET / ICHG
SYSOFF: HIGH = OFF LOW = ON
Configure for Z Axis Inversion
EN2:0 EN1:1 500mA mode
DC: I2C Address 0x3C BS: Select SPI / I2C
ILIM not used
Forward V @ 1.5V Forward I @ 70MA (3.3-1.5)/0.7 = 25
LED Matrix
vOUT = .6 (1+R1/R2)
Left button TBD
Microcontroller
Configured for low SOC @ 5%
- SDB active low to enable chip - Modulate LED's with IN (audio) - Not using CA-9 (8x8 matrix)
TSOP75338 (Vishay)
Open Drain
STRAPPING
Infrared TX
RC Delay Auto-Reset
Peripherals
invert + detect usb
JTAG
Buttons
VSMY14940 (Vishay)
Infrared RX
Hold any button to wake.
Screen

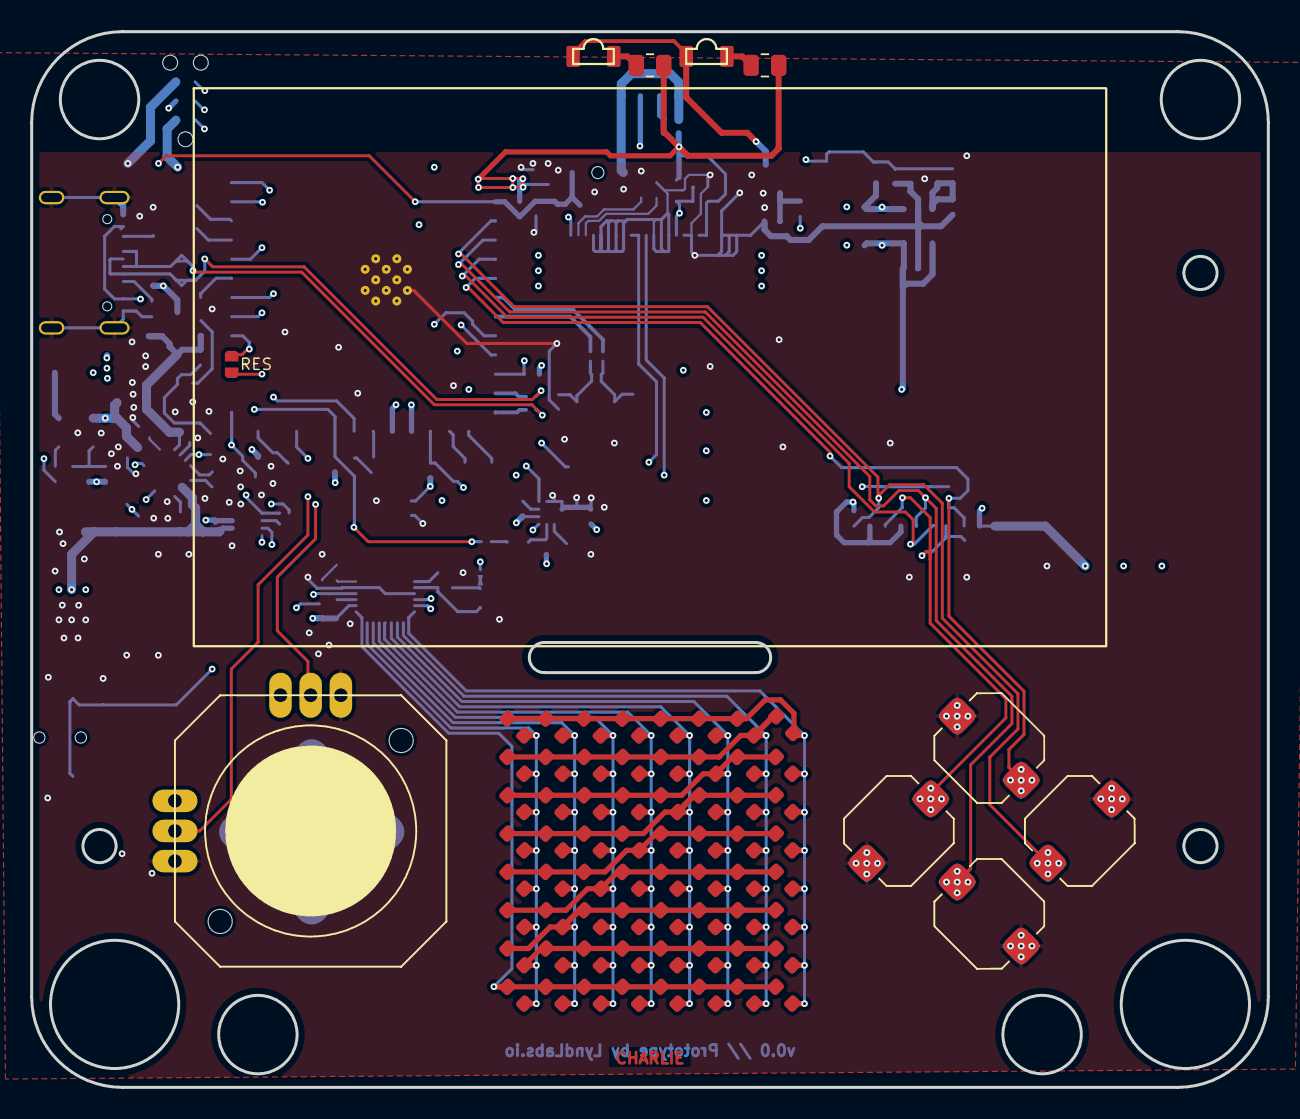
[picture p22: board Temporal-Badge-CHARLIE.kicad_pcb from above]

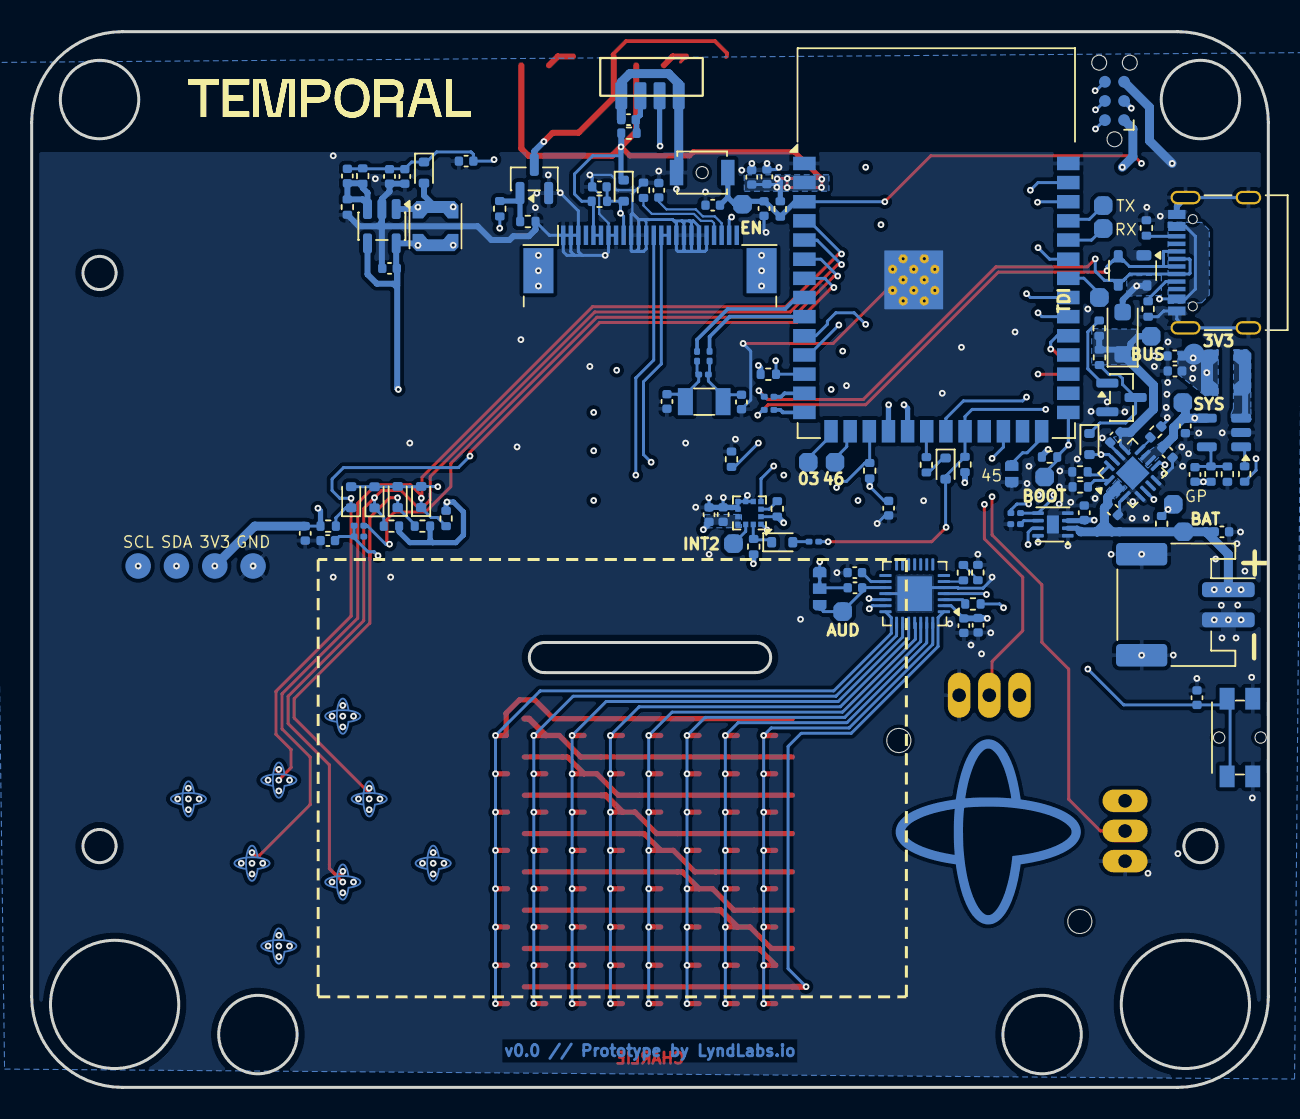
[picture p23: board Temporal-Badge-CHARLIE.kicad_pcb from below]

Board: 4 copper layers, 82.0 x 70.0 mm, 198 parts (123 on the bottom side), 86 nets.

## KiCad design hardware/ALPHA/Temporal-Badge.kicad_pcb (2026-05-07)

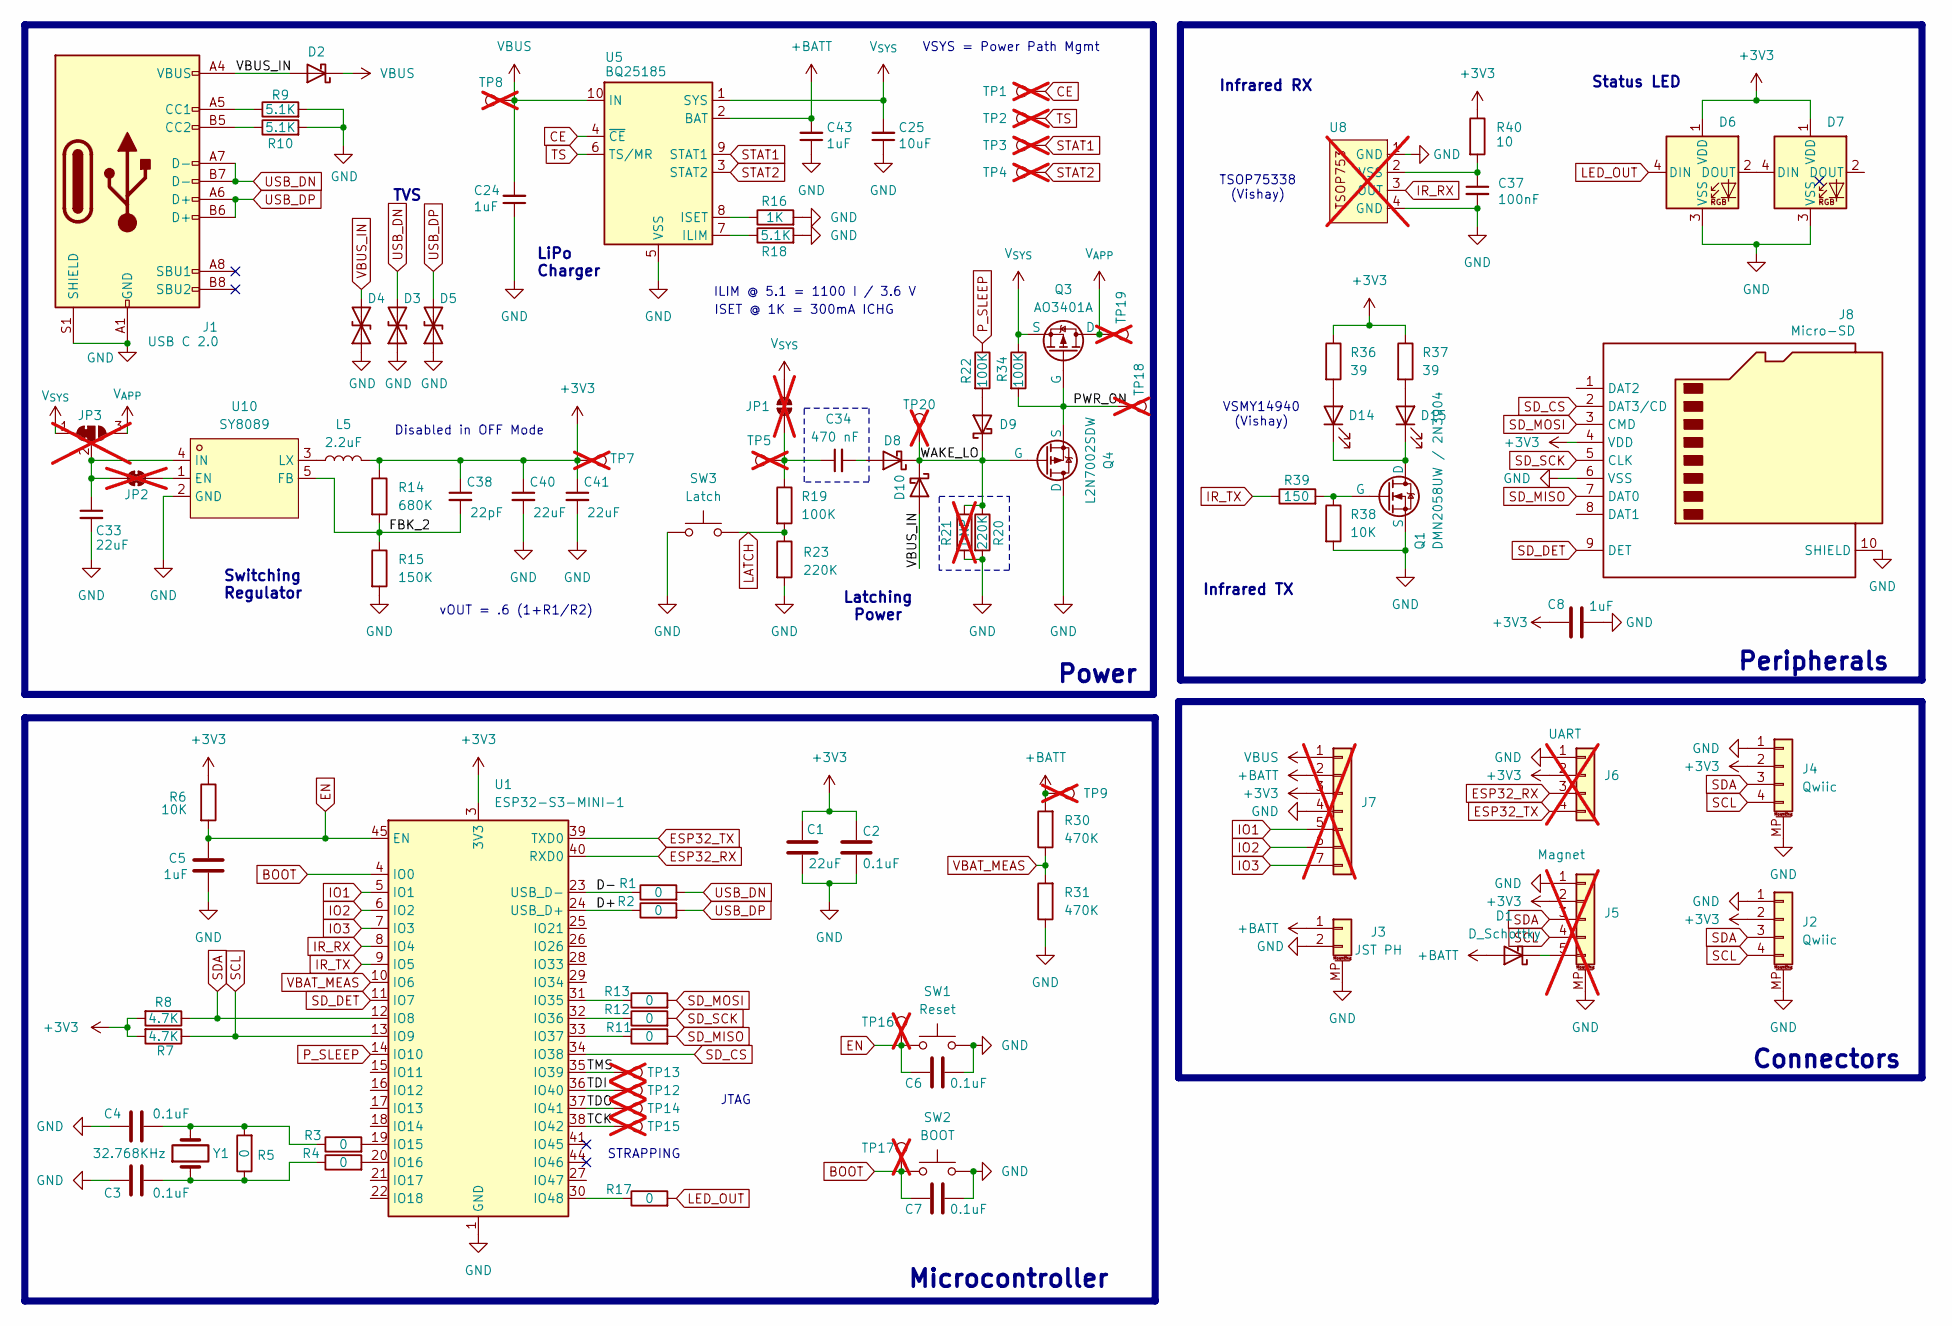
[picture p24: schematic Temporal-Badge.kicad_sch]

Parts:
C1, C33, C40, C41: 22uF; C_0402_1005Metric; LCSC C3845593
C2, C3, C4, C6, C7: 0.1uF; C_0402_1005Metric; LCSC C1525
C5, C8, C24, C43: 1uF; C_0402_1005Metric; LCSC C14445
C25: 10uF; C_0402_1005Metric; LCSC C315248
C34: 470 nF; C_0402_1005Metric; LCSC C92361
C37: 100nF; C_0402_1005Metric; LCSC C1525
C38: 22pF; C_0402_1005Metric; LCSC C76960
D1, D2: D_Schottky; D_SOD-323; LCSC C60580
D3, D4, D5: D_TVS; D_SOD-523; LCSC C3008120
D6, D7: WS2812B; LED_WS2812B_PLCC4_5.0x5.0mm_P3.2mm; LCSC C114586
D8, D9, D10: D_Schottky; D_SOD-523; LCSC C917006
D14, D15: VSMY14940; vsmy14940; LCSC C511069
J1: USB C 2.0; USB_C_Receptacle_Palconn_UTC16-G; LCSC C2765186
J2, J4: Qwiic; JST_SH_SM04B-SRSS-TB_1x04-1MP_P1.00mm_Horizontal; LCSC C51940130
J3: JST PH; JST_PH_S2B-PH-SM4-TB_1x02-1MP_P2.00mm_Horizontal; LCSC C295747
J5: Magnet; PinSocket_1x05_P2.54mm_Horizontal; not fitted
J6: UART; PinSocket_1x04_P2.54mm_Vertical; not fitted
J7: Breakout; PinSocket_1x07_P2.54mm_Vertical; not fitted
J8: Micro-SD; MicroSD; LCSC C381082
JP1: SolderJumper_2_Open; SolderJumper-2_P1.3mm_Open_RoundedPad1.0x1.5mm; not fitted
JP2: SolderJumper_2_Bridged; SolderJumper-2_P1.3mm_Bridged_RoundedPad1.0x1.5mm; not fitted
JP3: SolderJumper_3_Bridged12; SolderJumper-3_P1.3mm_Bridged12_RoundedPad1.0x1.5mm; not fitted
L5: 2.2uF; L_Coilcraft_LPS3010; LCSC C2926400
Q1: DMN2058UW / 2N3904; SOT-23; LCSC C54879
Q3: AO3401A; SOT-23; LCSC C15127
Q4: L2N7002SDW; SOT-23; LCSC C383163
R1, R2, R3, R4, R5, R11, R12, R13, R17: 0; R_0402_1005Metric; LCSC C106231
R6, R38: 10K; R_0402_1005Metric; LCSC C60490
R7, R8: 4.7K; R_0402_1005Metric; LCSC C105871
R9, R10, R18: 5.1K; R_0402_1005Metric; LCSC C25905
R14: 680K; R_0402_1005Metric; LCSC C163456
R15: 150K; R_0402_1005Metric; LCSC C93947
R16: 1K; R_0402_1005Metric; LCSC C106235
R19, R22, R34: 100K; R_0402_1005Metric; LCSC C60491
R20, R23: 220K; R_0402_1005Metric; LCSC C25767
R21: DNP; R_0402_1005Metric; not fitted
R30, R31: 470K; R_0402_1005Metric; LCSC C137976
R36, R37: 39; R_0402_1005Metric; LCSC C185420
R39: 150; R_0402_1005Metric; LCSC C138054
R40: 10; R_0402_1005Metric; LCSC C138066
SW1: Reset; Panasonic_EVQPUL_EVQPUC; LCSC C79174
SW2: BOOT; Panasonic_EVQPUL_EVQPUC; LCSC C79174
SW3: Latch; SW_SPST_B3U-1000P-B; LCSC C49234121
TP1, TP2, TP3, TP4, TP5, TP7, TP8, TP9, TP12, TP13, TP14, TP15, TP16, TP17, TP18, TP19, TP20: TestPoint; TestPoint_Pad_D1.0mm; not fitted
U1: ESP32-S3-MINI-1; ESP32-S2-MINI-1; LCSC C3013906
U5: BQ25185; WSON-10-1EP_4x3mm_P0.5mm_EP2.2x2mm; LCSC C19725033
U8: TSOP75338; TSOP753; not fitted
U10: SY8089; SOT-23-5; LCSC Part C79313
Y1: 32.768KHz; Crystal_SMD_3215-2Pin_3.2x1.5mm; LCSC C97606

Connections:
+3V3: C1.1, C2.1, C8.1, C38.1, C40.1, C41.1, D6.1 (VDD), D7.1 (VDD), J2.2, J4.2, J5.2, J6.2, J7.3, J8.4 (VDD), L5.2, R6.1, R7.2, R8.2, R14.1, R36.1, R37.1, R40.1, TP7.1, U1.3 (3V3)
+BATT: C43.2, D1.2 (A), J3.1, J7.2, R30.2, TP9.1, U5.2 (BAT)
/D+: R2.1, U1.24 (USB_D+)
/D-: R1.1, U1.23 (USB_D-)
/FBK_2: C38.2, R14.2, R15.1, U10.5 (FB)
/PWR_ON: Q3.2 (G), Q4.3 (S), R34.2, TP18.1
/TCK: TP15.1, U1.38 (IO42)
/TDI: TP12.1, U1.36 (IO40)
/TDO: TP14.1, U1.37 (IO41)
/TMS: TP13.1, U1.35 (IO39)
/WAKE: D8.1 (K), D9.1 (K), D10.1 (K), Q4.2 (G), R20.1, R21.1, TP20.1
BOOT: C7.1, SW2.2, TP17.1, U1.4 (IO0)
CE: TP1.1, U5.4 (~CE)
EN: C5.1, C6.1, R6.2, SW1.2, TP16.1, U1.45 (EN)
ESP32_RX: J6.3, U1.40 (RXD0)
ESP32_TX: J6.4, U1.39 (TXD0)
GND: C1.2, C2.2, C3.1, C4.1, C5.2, C6.2, C7.2, C8.2, C24.1, C25.1, C33.2, C37.2, C40.2, C41.2, C43.1, D3.1 (A1), D4.1 (A1), D5.1 (A1), D6.3 (VSS), D7.3 (VSS), J1.A1 (GND), J1.A12 (GND), J1.B1 (GND), J1.B12 (GND), J1.S1 (SHIELD), J2.1, J2.MP (MountPin), J3.2, J3.MP (MountPin), J4.1, J4.MP (MountPin), J5.1, J5.MP (MountPin), J6.1, J7.4, J8.6 (VSS), J8.10 (SHIELD), J8.11 (SHIELD), Q1.3 (S), Q4.1 (D), R9.2, R10.2, R15.2, R16.2, R18.2, R20.2, R21.2, R23.2, R31.1, R38.2, SW1.1, SW2.1, SW3.2, U1.1 (GND), U1.2 (GND), U1.42 (GND), U1.43 (GND), U1.46 (GND), U1.47 (GND), U1.48 (GND), U1.49 (GND), U1.50 (GND), U1.51 (GND), U1.52 (GND), U1.53 (GND), U1.54 (GND), U1.55 (GND), U1.56 (GND), U1.57 (GND), U1.58 (GND), U1.59 (GND), U1.60 (GND), U1.61 (GND), U1.62 (GND), U1.63 (GND), U1.64 (GND), U1.65 (GND), U5.5 (VSS), U5.11 (VSS), U8.1 (GND), U8.4 (GND), U10.2 (GND)
IO1: J7.5, U1.5 (IO1)
IO2: J7.6, U1.6 (IO2)
IO3: J7.7, U1.7 (IO3)
IR_RX: U1.8 (IO4), U8.3 (OUT)
IR_TX: R39.1, U1.9 (IO5)
LATCH: R19.2, R23.1, SW3.1
LED_OUT: D6.4 (DIN), R17.2
unnamed: C3.2, R4.1, R5.1, Y1.1
unnamed: C4.2, R3.1, R5.2, Y1.2
unnamed: D1.1 (K), J5.5
unnamed: D6.2 (DOUT), D7.4 (DIN)
unnamed: C34.2, D8.2 (A)
unnamed: D9.2 (A), R22.2
unnamed: D14.2 (A), R36.2
unnamed: D14.1 (K), D15.1 (K), Q1.1 (D)
unnamed: D15.2 (A), R37.2
unnamed: J1.A5 (CC1), R9.1
unnamed: J1.B5 (CC2), R10.1
unnamed: C34.1, JP1.2 (B), R19.1, TP5.1
unnamed: C33.1, JP2.1 (A), JP3.2 (C), U10.4 (IN)
unnamed: JP2.2 (B), U10.1 (EN)
unnamed: Q1.2 (G), R38.1, R39.2
unnamed: R3.2, U1.19 (IO15)
unnamed: R4.2, U1.20 (IO16)
unnamed: R13.1, U1.31 (IO35)
unnamed: R12.1, U1.32 (IO36)
unnamed: R11.1, U1.33 (IO37)
unnamed: R17.1, U1.30 (IO48)
unnamed: R18.1, U5.7 (ILIM)
unnamed: R16.1, U5.8 (ISET)
unnamed: C37.1, R40.2, U8.2 (VSS)
unnamed: L5.1, U10.3 (LX)
P_SLEEP: R22.1, U1.14 (IO10)
SCL: J2.4, J4.4, J5.4, R7.1, U1.13 (IO9)
SDA: J2.3, J4.3, J5.3, R8.1, U1.12 (IO8)
SD_CS: J8.2 (DAT3/CD), U1.34 (IO38)
SD_DET: J8.9 (DET), U1.11 (IO7)
SD_MISO: J8.7 (DAT0), R11.2
SD_MOSI: J8.3 (CMD), R13.2
SD_SCK: J8.5 (CLK), R12.2
STAT1: TP3.1, U5.9 (STAT1)
STAT2: TP4.1, U5.3 (STAT2)
TS: TP2.1, U5.6 (TS/MR)
USB_DN: D3.2 (A2), J1.A7 (D-), J1.B7 (D-), R1.2
USB_DP: D5.2 (A2), J1.A6 (D+), J1.B6 (D+), R2.2
VBAT_MEAS: R30.1, R31.2, U1.10 (IO6)
VBUS: C24.2, D2.1 (K), J7.1, TP8.1, U5.10 (IN)
VBUS_IN: D2.2 (A), D4.2 (A2), D10.2 (A), J1.A4 (VBUS), J1.A9 (VBUS), J1.B4 (VBUS), J1.B9 (VBUS)
V_{APP}: JP3.3 (B), Q3.1 (D), TP19.1
V_{SYS}: C25.2, JP1.1 (A), JP3.1 (A), Q3.3 (S), R34.1, U5.1 (SYS)

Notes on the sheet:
Power
Status LED
ISET @ 1K = 300mA ICHG
VSYS = Power Path Mgmt
vOUT = .6 (1+R1/R2)
Microcontroller
Disabled in OFF Mode
TSOP75338 (Vishay)
ILIM @ 5.1 = 1100 I / 3.6 V
LiPo Charger
Infrared TX
Latching Power
STRAPPING
TVS
Switching Regulator
JTAG
Peripherals
Connectors
VSMY14940 (Vishay)
Infrared RX

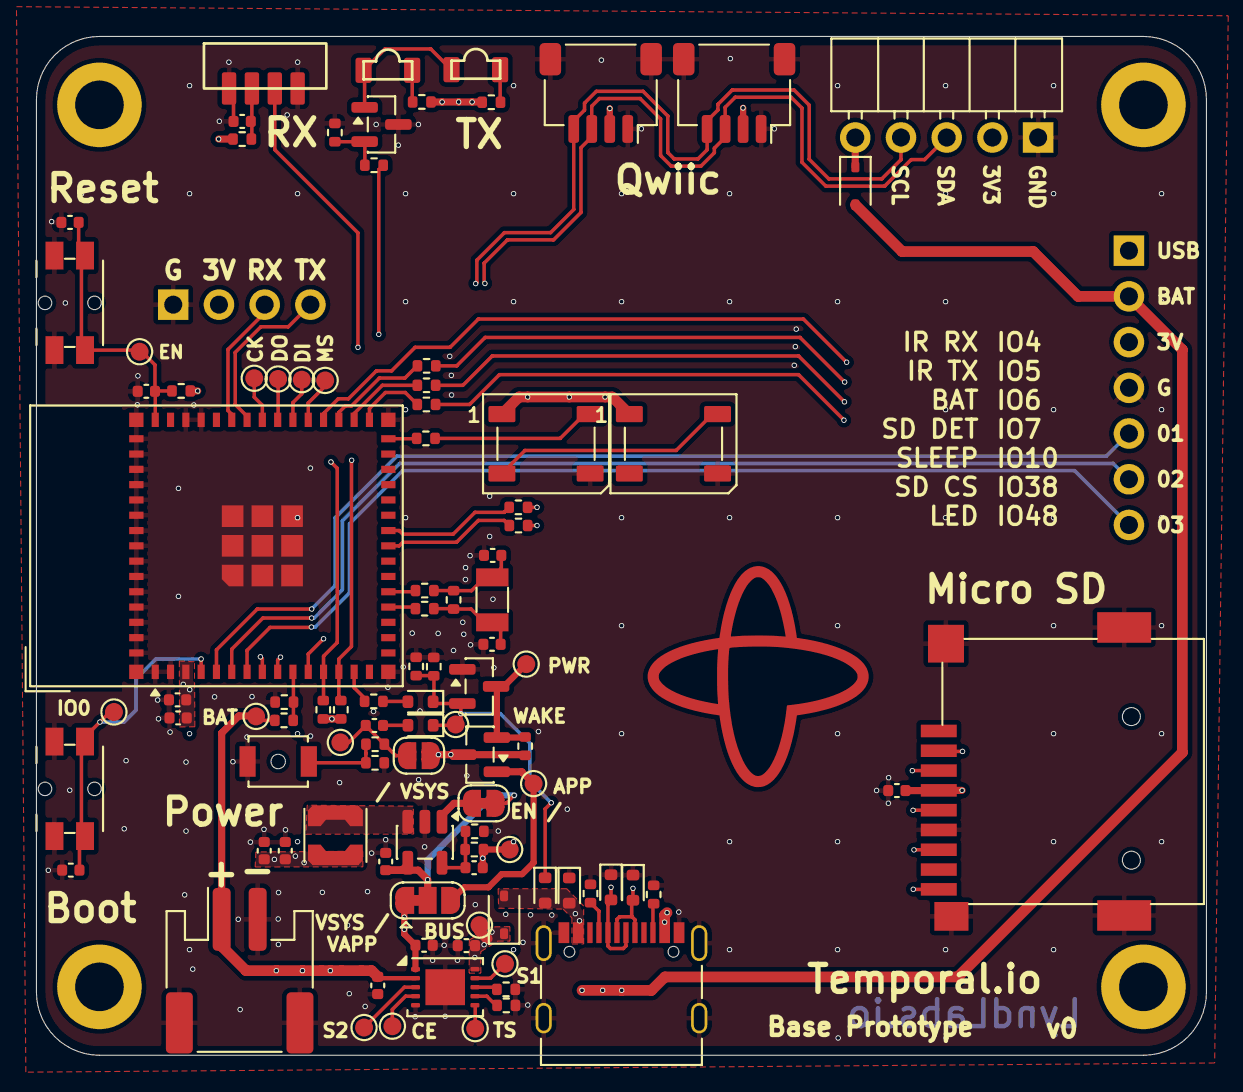
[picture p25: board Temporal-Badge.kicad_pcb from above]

Board: 4 copper layers, 65.0 x 56.6 mm, 100 parts (0 on the bottom side), 67 nets.

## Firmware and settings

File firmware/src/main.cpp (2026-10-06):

#include <Arduino.h>

#include "hardware/HardwareConfig.h"

#include "infra/BadgeConfig.h"
#include "infra/Filesystem.h"
#include "micropython/StartupFiles.h"
#include "ui/GUI.h"
#include "ui/BootSplash.h"
#include "hardware/Haptics.h"
#include "hardware/IMU.h"
#include "hardware/Inputs.h"
#include "hardware/LEDmatrix.h"
#include "hardware/Power.h"
#include "emotion/EmotionGlobals.h"
#include "emotion/EmotionBleService.h"
#include "drive/DriveBleService.h"
#include "infra/Scheduler.h"
#include "esp32-hal-gpio.h"
#include "hardware/oled.h"
#include <Wire.h>
#include "esp_log.h"
#include "esp_heap_caps.h"
#include "esp_sleep.h"
#include "esp_netif.h"
#include "esp_event.h"
#include "nvs_flash.h"

#include "identity/BadgeUID.h"
#include "ui/BadgeDisplay.h"
#include "ir/BadgeIR.h"
#include "boops/BadgeBoops.h"
#include "identity/BadgeInfo.h"
#include "api/DataCache.h"
#include "api/WiFiService.h"
#ifdef BADGE_ENABLE_BLE_PROXIMITY
#include "ble/BadgeBeaconAdv.h"
#include "ble/BleBeaconScanner.h"
#endif
#include "led/LEDAppRuntime.h"
#include "micropython/MicroPythonMatrixService.h"
#include "ota/AssetRegistry.h"
#include "ota/BadgeOTA.h"
#include "ota/OTAService.h"

#ifdef BADGE_HAS_DOOM
#include "doom/doom_app.h"
#include "doom/doom_resources.h"
#endif

#include "hardware/PanicReset.h"

// Loop task stack: MicroPython, OLED composition, and optional hacker HTTP
// calls can still be stack-hungry, so keep the historical 24 KB headroom.
SET_LOOP_TASK_STACK_SIZE(24 * 1024);

// ── Global hardware instances ─────────────────────────────────────────────────
// All peripheral globals are always declared. On hardware that lacks a
// peripheral, its class is a no-op stub (see HardwareConfig.h feature flags).
oled badgeDisplay;
Inputs inputs;
Scheduler scheduler;
SleepService sleepService;
IMU imu;
LEDmatrix badgeMatrix;
BatteryGauge batteryGauge;
HapticsService hapticsService;
FileBrowser fileBrowser;
GUIManager guiManager;
MicroPythonMatrixService microPythonMatrix;
EmotionConsumer g_emotion;
TaskHandle_t gIrTaskHandle = NULL;

bool gWakeOnlyMode = false;

static constexpr size_t kMallocPreferInternalBelowBytes = 1024;
static constexpr size_t kSerialRxBufferBytes = 4096;
static size_t sBootPsramBytes = 0;
static bool sBootPsramPolicyApplied = false;

static void configureBootHeapPolicy() {
    sBootPsramBytes = heap_caps_get_total_size(MALLOC_CAP_SPIRAM | MALLOC_CAP_8BIT);
    if ( sBootPsramBytes == 0 ) return;

    heap_caps_malloc_extmem_enable( kMallocPreferInternalBelowBytes );
    sBootPsramPolicyApplied = true;
}

#ifdef BADGE_HAS_IMU
static void applyBadgeOrientation(BadgeOrientation orient) {
    if ( orient == BadgeOrientation::kUnknown ) {
        return;
    }

    // Keep interactive UI controls in the badge's normal orientation. An
    // inverted badge posture is only a passive display mode (nametag or other
    // asset), so it must not leak into joystick/button semantics when the
    // overlay is dismissed.
    badgeDisplay.setFlipped( false );
    inputs.setOrientation( BadgeOrientation::kUpright );
#ifdef BADGE_HAS_LED_MATRIX
    // The LED matrix still has its own physical mounting transform.
    const bool matrixNeedsRotation = ( orient == BadgeOrientation::kUpright );
    badgeMatrix.setFlipped( matrixNeedsRotation );
#endif
}
#endif

extern "C" void mpy_start( Stream* stream ) __attribute__( ( weak ) );
extern "C" void mpy_poll( void ) __attribute__( ( weak ) );
extern "C" void mpy_pump_set_ready( void ) __attribute__( ( weak ) );

static void printReplayBootMarker(const char* phase) {
    Serial.printf("[boot] Temporal Replay 2026 - %s %s - phase=%s - boot_ms=%lu\n",
                  __DATE__, __TIME__, phase ? phase : "boot",
                  (unsigned long)millis());
}

void setup( ) {
    configureBootHeapPolicy();
    Serial.setRxBufferSize( kSerialRxBufferBytes );
    Serial.begin( 115200 );
    printReplayBootMarker("serial");
    Serial.println( "Starting..." );
    if ( sBootPsramPolicyApplied ) {
        Serial.printf( "[boot] PSRAM heap=%u bytes; malloc prefers internal below %u bytes\n",
                       (unsigned)sBootPsramBytes,
                       (unsigned)kMallocPreferInternalBelowBytes );
    } else {
        Serial.println( "[boot] PSRAM heap unavailable; using default malloc policy" );
    }
    // Diagnostic: print prior reset reason so a silent reset on the
    // previous boot identifies itself (panic / task WDT / brownout / etc).
    Serial.printf( "[boot] reset_reason=%d (1=PWR 3=SW 4=PANIC 5=INT_WDT 6=TASK_WDT 7=WDT 11=RTC 15=BROWNOUT)\n",
                   (int)esp_reset_reason() );
    const esp_sleep_wakeup_cause_t wakeCause = esp_sleep_get_wakeup_cause( );
    gWakeOnlyMode = ( wakeCause == ESP_SLEEP_WAKEUP_TIMER );
    Serial.printf( "Wake cause: %d, wake-only mode: %d\n", (int)wakeCause, gWakeOnlyMode ? 1 : 0 );

    Power::applyBootRadioDefaults( );
    Power::initCpuGovernor( );

    // Single, authoritative I2C master init. All on-bus drivers (IMU, OLED,
    // LED matrix, battery gauge) share Wire — they must not call Wire.begin
    // themselves, and nothing downstream should call Wire.end()/Wire.begin()
    // once drivers are live. The Arduino wrapper silences IDF i2c.master
    // logs inside i2cInit(); re-enable them so a real NACK / timeout is
    // visible instead of the generic ESP_ERR_INVALID_STATE(259).
    Wire.begin( SDA_PIN, SCL_PIN, 400000 );
    Wire.setTimeOut( 200 );
    esp_log_level_set( "i2c.master", ESP_LOG_ERROR );

#ifdef BADGE_HAS_SLEEP_SERVICE
    // SYSOFF is active-high on the charger path; never enable a pull-up on it.
#if defined(SYSOFF_PIN)
    digitalWrite(SYSOFF_PIN, LOW);
    pinMode(SYSOFF_PIN, OUTPUT);
#endif
#if !defined(SYSOFF_PIN) || (MCU_SLEEP_PIN != SYSOFF_PIN)
    pinMode(MCU_SLEEP_PIN, INPUT_PULLUP);
#endif
#if !defined(SYSOFF_PIN) || (INT_GP_PIN != SYSOFF_PIN)
    pinMode(INT_GP_PIN, INPUT_PULLUP);
#endif
#endif

// pinMode(IR_TX_PIN, OUTPUT);
// pinMode(IR_RX_PIN, INPUT);

// for (int i = 0; i < 500; i++) {
//     Serial.printf("Sending IR frame %d\n", i);
//     digitalWrite(IR_TX_PIN, HIGH);
//     Serial.printf("IR RX: %d\n", digitalRead(IR_RX_PIN));
//     delay(100);
//     digitalWrite(IR_TX_PIN, LOW);
//     Serial.printf("IR RX: %d\n", digitalRead(IR_RX_PIN));
//     delay(100);
// }

    // UID must be populated before badgeConfig.load() because
    // loadStringsFromNvs() unscrambles the WiFi password using a key
    // derived from `uid[]`. Loading first would XOR the saved blob
    // against zero-uid garbage, producing an unusable password and
    // making auto-connect fail silently on every cold boot.
    read_uid();
    Serial.printf( "  UID: %s\n", uid_hex );
    badgeConfig.load();
    displayInit();
#ifdef BADGE_ENABLE_BLE_PROXIMITY
    BleBeaconScanner::reserveMemoryAnchor();
#endif

    // Brownout-sensitive peripherals (haptics motor, IMU, LED matrix
    // power-on inrush, IR transmitter) come up later from
    // initDeferredPeripherals(), called the first time the home
    // screen is entered. Pre-home rendering only needs the OLED.

    // if ( gWakeOnlyMode ) {
    //     scheduler.setExecutionDivisors( 1, 1, 1 );
    //     Serial.println( "Wake-only mode active" );
    //     return;
    // }

    // ── ESP-IDF networking prerequisites ────────────────────────────────────
    // MicroPython's network.WLAN, socket, ssl, espnow and bluetooth modules
    // all expect the IDF event loop, NVS, and esp_netif to be initialised
    // before the runtime starts. arduino-esp32's WiFi.begin() does this
    // lazily, but MicroPython users expect to be able to instantiate
    // network.WLAN() directly from the REPL. Initialise here so the surface
    // is available unconditionally — these calls are idempotent and cheap.
    {
        esp_err_t nvsRc = nvs_flash_init();
        if ( nvsRc == ESP_ERR_NVS_NO_FREE_PAGES ||
             nvsRc == ESP_ERR_NVS_NEW_VERSION_FOUND ) {
            nvs_flash_erase();
            nvs_flash_init();
        }
        esp_netif_init();
        esp_event_loop_create_default();
    }

    // ── MicroPython + FAT mount ───────────────────────────────────────────────
    if ( mpy_start != nullptr ) {
        mpy_start( &Serial );
    } else {
        Serial.println( "MicroPython not linked" );
    }

    provisionStartupFiles(); // set to true to force filesystem rebuild
    BadgeBoops::begin();

    // Schedule / speakers / floors content cache. Synchronous: tries
    // /data.bin from FatFS, falls back to the bundle linked via embed_files.
    DataCache::init(nullptr);

    {
        BadgeInfo::Fields info;
        if (!BadgeInfo::loadFromFile(info)) {
            BadgeInfo::populateDefaults(info, uid);
            BadgeInfo::saveToFile(info);
            Serial.println("BadgeInfo: created /badgeInfo.json");
        }
        BadgeInfo::applyToGlobals(info);
    }


    if ( badgeConfig.loadFromFile( ) ) {
        badgeConfig.applyAll( );
    }

    extern BadgeState badgeState;
    badgeState = BADGE_PAIRED;
    Serial.println( "[boot] offline mode active — pairing gate disabled" );

    // ── OLED init ─────────────────────────────────────────────────────────────
    const bool oled_ok = ( badgeDisplay.init( ) == 0 );
    if ( oled_ok ) {
        // Clamp boot-screen contrast to 150 to keep the OLED's load
        // off the 3V3 rail before the haptics/LED-matrix/IMU/IR
        // peripherals come up. initDeferredPeripherals() restores the
        // user's preferred contrast (via badgeConfig.applyAll) once
        // the home screen is reached.
        badgeDisplay.setContrast( 80 );
        badgeDisplay.clearDisplay( );
        badgeDisplay.setCursor( 0, 0 );
#ifdef BADGE_HAS_SLEEP_SERVICE
        badgeDisplay.bindPin("int_gp", INT_GP_PIN);
#endif
        Serial.println( "OLED init OK (contrast clamped to 150 for boot)" );
    } else {
        Serial.println( "OLED init failed — continuing without display" );
    }

    PanicReset::begin(oled_ok ? &badgeDisplay : nullptr);

    // Pre-splash screen is intentionally blank — BootSplash is the only
    // boot visual. Keeping the panel cleared (and contrast clamped to
    // 80 from the init block above) so the splash's hardware fade-in
    // starts from true black.
    badgeDisplay.clearBuffer();
    badgeDisplay.sendBuffer();
    Serial.println( "=== BADGE MERGE CODE RUNNING ===" );
    Serial.println( "  Network:   explicit-only MicroPython helpers" );

    // Boot splash — temporal-logo starfield. Blocks setup() for the duration;
    // ends with transitionOut(300) so the panel is dark when GUIManager
    // pushes the home screen. Bring up just the LED matrix's I2C controller
    // first so the splash can drive its sparkle animation; full service
    // registration stays in initDeferredPeripherals().
#ifdef BADGE_HAS_LED_MATRIX
    if ( badgeMatrix.init( LED_MATRIX_I2C_ADDRESS ) == 0 ) {
        badgeMatrix.setBrightness( Power::Policy::kLedMatrixDefaultBrightness );
        badgeMatrix.clear( 0 );
        Serial.println( "LED matrix init OK (early, for splash sparkles)" );
    } else {
        Serial.println( "LED matrix init failed (early); splash sparkles disabled" );
    }
#endif

    if ( oled_ok ) {
        BootSplash::playStarfield(4000, 60);
    }

    #ifndef BADGE_HAS_IMU
    badgeDisplay.setFlipped( false );
#endif

    badgeDisplayActive = true;
    screenDirty = true;
    printReplayBootMarker("ready");
    Serial.println( "=== offline boot complete ===" );

    // LED matrix init deferred to initDeferredPeripherals() — the
    // power-on inrush is the worst single brownout offender.

    inputs.begin( );
    Serial.println( "Input handler init OK" );

#ifdef BADGE_HAS_BATTERY_GAUGE
    const bool gauge_ok = batteryGauge.begin( );
    if ( gauge_ok ) {
        Serial.printf( "Battery: %.1f%%  %.3f V\n",
                       batteryGauge.stateOfChargePercent( ),
                       batteryGauge.cellVoltage( ) );
    } else {
        Serial.println( "Battery gauge init failed" );
    }
#endif

    // LED matrix / IMU bindings deferred — they reference peripherals
    // that initDeferredPeripherals() will bring up.
    badgeDisplay.bindInputs( &inputs );
#ifdef BADGE_HAS_BATTERY_GAUGE
    badgeDisplay.bindBatteryGauge( &batteryGauge );
#endif
#ifdef BADGE_HAS_HAPTICS
    hapticsService.bindDisplay( &badgeDisplay );
    hapticsService.bindInputs( &inputs );
#endif

    badgeConfig.applyAll();
    // applyAll may have written the user's preferred contrast — re-
    // clamp to 150 so we ride out the rest of boot at the safer level.
    if ( oled_ok ) {
        badgeDisplay.setContrast( 150 );
    }

    // IMU orientation detection deferred — it depends on imu.begin().




    if ( mpy_pump_set_ready != nullptr ) {
        mpy_pump_set_ready( );
    }

    fileBrowser.begin( &badgeDisplay, &inputs, &badgeConfig );

    scheduler.registerService( &inputs, ServicePriority::kHigh );

#ifdef BADGE_HAS_HAPTICS
    scheduler.registerService( &hapticsService, ServicePriority::kHigh );
#endif

    // LED-matrix services deferred — they're registered from
    // initDeferredPeripherals() once the matrix is powered on.

    scheduler.registerService( &fileBrowser, ServicePriority::kNormal );
    scheduler.registerService( &badgeDisplay, ServicePriority::kNormal );

#ifdef BADGE_HAS_BATTERY_GAUGE
    if ( gauge_ok ) {
        scheduler.registerService( &batteryGauge, ServicePriority::kLow );
    }
#endif

    // Boot/pairing rendering is complete. From here, GUIManager owns OLED
    // rendering and disables the legacy OLED scheduler service in begin().
    badgeDisplayActive = false;
    renderMode = MODE_MENU;
    screenDirty = false;
    guiManager.begin( &badgeDisplay, &inputs );
    // Nametag-mode set deferred — needs imu.getOrientation().
    scheduler.registerService( &guiManager, ServicePriority::kHigh );

    wifiService.begin();
    scheduler.registerService( &wifiService, ServicePriority::kLow );

    // OTA + asset registry. begin() loads NVS caches and detects
    // ESP_OTA_IMG_PENDING_VERIFY (first boot after a fresh install).
    // OTAService runs at low priority and forwards a daily-cadence
    // tick to BadgeOTA + AssetRegistry.
    ota::begin();
    ota::registry::begin();
    scheduler.registerService( &ota::otaService, ServicePriority::kLow );

    // IR task creation deferred — initDeferredPeripherals() spawns it
    // after the home screen is reached, so the IR transmitter pulses
    // can't brown out the rail during boot.

    scheduler.setExecutionDivisors( Power::Policy::schedulerHighDivisor,
                                    Power::Policy::schedulerNormalDivisor,
                                    Power::Policy::schedulerLowDivisor );


    configWatcher.begin( &badgeConfig );
    scheduler.registerService( &configWatcher, ServicePriority::kLow );

#ifdef BADGE_ENABLE_BLE_PROXIMITY
    BadgeBeaconAdv::begin();
#endif
}

// Brings up the brownout-sensitive peripherals deferred from setup():
// haptics motor, IMU, LED matrix, IR task. Called the first time the
// home grid menu is entered (see GridMenuScreen::onEnter), guarded by
// a static flag so re-entries are no-ops. Once everything is online,
// re-applies badgeConfig so the user's preferred OLED contrast (which
// boot clamped to 150) is restored.
extern "C" void initDeferredPeripherals() {
    static bool done = false;
    if ( done ) return;
    done = true;

    Serial.println( "=== initDeferredPeripherals: bringing peripherals online ===" );

#ifdef BADGE_HAS_HAPTICS
    Haptics::begin();
#endif

#ifdef BADGE_HAS_IMU
    const bool imu_ok = imu.begin( );
    Serial.println( imu_ok ? "IMU init OK (deferred)"
                           : "IMU init failed (deferred)" );
    if ( imu_ok ) {
        scheduler.registerService( &imu, ServicePriority::kHigh );
        sleepService.begin( &imu, gWakeOnlyMode ? nullptr : &badgeMatrix,
                            gWakeOnlyMode ? nullptr : &badgeDisplay,
                            INT_GP_PIN,
                            Power::Policy::kLightSleepAfterNoMotionMs,
                            Power::Policy::kDeepSleepAfterNoMotionMs );
        scheduler.registerService( &sleepService, ServicePriority::kLow );
#ifdef BADGE_HAS_SLEEP_SERVICE
        sleepService.bindInputs( &inputs );
#endif
        badgeDisplay.bindAccel( &imu );

        imu.checkInitialOrientation( );
        if ( imu.flipChanged( ) ) {
            applyBadgeOrientation( imu.getOrientation( ) );
            imu.clearFlipChanged( );
        }
        if ( imu.getOrientation( ) != BadgeOrientation::kUnknown ) {
            guiManager.setNametagMode(
                imu.getOrientation( ) == BadgeOrientation::kInverted );
        }
    }
#endif
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
void loop( ) {
#ifdef BADGE_HAS_DOOM
    const bool doomOwnsBadge = !gWakeOnlyMode && doom_resources_active();
    if ( !doomOwnsBadge ) {
        scheduler.runOnce( );
    }
#else
    scheduler.runOnce( );
#endif

    if ( !gWakeOnlyMode ) {
#ifdef BADGE_HAS_DOOM
        if ( doom_resources_active() ) {
            if ( !doom_app_is_running() ) {
                doom_app_exit();
                doom_app_deinit();
                doom_resources_exit();

                Haptics::off();

                // Wait for the user to release all buttons (they were
                // holding L+R for the exit combo) before restarting input.
                // Doom detaches input interrupts while it runs, so first
                // resync the logical state with the physical pins before
                // waiting; otherwise a launch/exit button can stay logically
                // held and repeat into the restored menu.
                inputs.resyncButtons();
                Serial.println("[doom] waiting for input release before GUI restore");

                // Spin until all buttons are released so the exit combo
                // doesn't leak into the GUI as spurious presses.
                {
                    uint32_t releaseDeadline = millis() + 2000;
                    bool allUp = false;
                    while ( !allUp && millis() < releaseDeadline ) {
                        inputs.update();
                        inputs.clearEdges();
                        const Inputs::ButtonStates& b = inputs.buttons();
                        allUp = !b.up && !b.down && !b.left && !b.right;
                        inputs.service();
                        delay(20);
                    }
                    if (!allUp) {
                        Serial.println("[doom] input release wait timed out");
                    }
                    // One final flush after release
                    uint32_t quietUntil = millis() + 250;
                    while (millis() < quietUntil) {
                        inputs.update();
                        inputs.clearEdges();
                        delay(20);
                    }
                }

                guiManager.activate();
                Serial.println("[doom] teardown complete, GUI restored");
            } else {
                Power::noteActivity();
                delay(1);
            }
            return;
        }
#endif

        if ( guiManager.isActive() ) {
            guiManager.handleInputIfActive();
        }
#ifdef BADGE_HAS_DOOM
        if ( doom_resources_active() ) {
            Power::noteActivity();
            delay(1);
            return;
        }
#endif
        inputs.clearEdges();
    }

#ifdef BADGE_HAS_IMU
    if ( imu.flipChanged( ) ) {
        const auto orient = imu.getOrientation( );
        Serial.printf("imu.tiltXMag: %f, imu.tiltYMag: %f\n", imu.tiltXMg(), imu.tiltYMg());
        
        applyBadgeOrientation( orient );
        guiManager.setNametagMode( orient == BadgeOrientation::kInverted );
        imu.clearFlipChanged( );
    }
#endif

#ifdef BADGE_HAS_LED_MATRIX
    if ( !gWakeOnlyMode && LEDmatrixAnimator::isUserActive( inputs ) ) {
        Power::noteActivity( );
    }
#endif
#ifdef BADGE_HAS_SLEEP_SERVICE
    sleepService.processDeferredWake( );
#endif

    Power::updateCpuGovernor( );

#ifdef BADGE_ENABLE_BLE_PROXIMITY
    if ( !gWakeOnlyMode ) {
        BleBeaconScanner::serviceScanCache();
    }
#endif

    if ( !gWakeOnlyMode && mpy_poll != nullptr ) {
         mpy_poll( );
    }

#ifdef BADGE_ENABLE_EMOTION_BLE
    {
        static uint32_t lastEmoPubMs = 0;
        if ( millis() - lastEmoPubMs >= 1000 ) {
            lastEmoPubMs = millis();
            emotionBleStatePublish( g_emotion,
                                    (uint8_t)batteryGauge.stateOfChargePercent() );
        }
        // A mood written over BLE counts as activity, so a battery badge an
        // AI is driving doesn't deep-sleep from lack of motion.
        if ( g_emotion.takeActivity() ) {
            sleepService.caffeine = true;
        }
        // "Show face" waits while the GUI is handed off (Doom); a Python
        // app blocks this loop, so the request is taken after it exits.
        if ( guiManager.isActive() && g_emotion.takeFaceRequest()
             && !g_emotion.faceOnScreen() ) {
            guiManager.pushScreen( kScreenRobotFace );
        }
    }
#ifdef BADGE_ENABLE_DRIVE_BLE
    driveBleTick( (uint8_t)batteryGauge.stateOfChargePercent() );
    if ( driveBleConnected() || driveLocalActive() ) sleepService.caffeine = true;   // stay awake while driven
#ifdef BADGE_DRIVE_STATUS_SCREEN
    {
        static bool shown = false;
        if ( guiManager.isActive() && driveBleConnected() && !shown ) {
            guiManager.pushScreen( kScreenDriveStatus ); shown = true;
        } else if ( !driveBleConnected() && shown ) {
            if ( guiManager.currentScreen()
                 && guiManager.currentScreen()->id() == kScreenDriveStatus ) {
                guiManager.popScreen();
            }
            shown = false;
        }
    }
#endif
#endif
#endif

    Power::applyLoopPacing( );
}

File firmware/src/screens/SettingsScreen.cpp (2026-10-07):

#include "SettingsScreen.h"

#include <cstdio>
#include <cstdlib>
#include <cstring>
#include <ctime>

#include "../api/WiFiService.h"
#include "../apps/MenuOrderStore.h"
#include "../hardware/Inputs.h"
#include "../hardware/LEDmatrix.h"
#include "../hardware/oled.h"
#include "../infra/BadgeConfig.h"
#include "../led/LEDAppRuntime.h"
#include "../micropython/StartupFiles.h"
#include "../ui/ButtonGlyphs.h"
#include "../ui/GUI.h"
#include "../ui/OLEDLayout.h"
#include "../ui/UIFonts.h"
#include "ScreenRefs.h"
#include "TextInputScreen.h"

extern "C" void rebuildMainMenuFromRegistry(void);

extern LEDmatrix badgeMatrix;

namespace {

constexpr uint8_t kRowHeight = 11;
constexpr int     kValueRightX = 119;  // pulled in 5 px so right-aligned values clear the scrollbar (122..127)

// ── Compile-time scroll cadence (matches GridMenuScreen / home menu) ─────
constexpr uint32_t kSettingsRampStartMs = 350;
constexpr uint32_t kSettingsRampMinMs   = 100;
constexpr uint32_t kSettingsRampStepMs  = 50;

// ── Chevron bitmap (downward triangle) ──────────────────────────────────
// Right-arrow geometry rotated 90° clockwise about the X axis so the
// dropdown indicator points down regardless of expansion state. 5 wide ×
// 3 tall.
constexpr uint8_t kChevronW = 5;
constexpr uint8_t kChevronH = 5;
// Down-arrow chevron — drawn when the group is expanded (active).
static const uint8_t kChevronDownBits[] PROGMEM = {
    0x00, 0x1F, 0x0E, 0x04, 0x00,
};
// Right-arrow chevron — drawn when the group is collapsed.
static const uint8_t kChevronRightBits[] PROGMEM = {
    0x01, 0x03, 0x07, 0x03, 0x01,
};
constexpr int kSettingIndent = 10;  // dropdown items indent under the chevron (+5 deeper than before)

// Tiny adjustability arrows shown on the right side of each setting
// row, flanking the value. Right-pointing 3×5 arrow + its left-
// pointing mirror (mirror generated at draw time so we ship one
// bitmap). Indicates the value is joystick-L/R adjustable.
constexpr uint8_t kSettingArrowW = 3;
constexpr uint8_t kSettingArrowH = 5;
static const uint8_t kSettingArrowRightBits[] PROGMEM = {
    0x01, 0x03, 0x07, 0x03, 0x01,
};
static const uint8_t kSettingArrowLeftBits[] PROGMEM = {
    0x04, 0x06, 0x07, 0x06, 0x04,
};

// ── Setting groups ───────────────────────────────────────────────────────
//
// User-facing categories surface only the values most users would want
// to tweak. Every other ("nuanced") setting goes under the Admin
// dropdown, which is compiled in only when BADGE_DEV_MENU is defined —
// the underlying values still load and apply in production builds, the
// dropdown just isn't reachable from the UI.

// ── Group row model ──────────────────────────────────────────────────────
//
// A group row is either a numeric/toggle SettingIndex (handled by the
// existing edit-mode flow) or an "action" — a one-shot row that fires a
// callback on confirm and renders a static label + optional value on the
// right. Used for "Set Time", "WiFi SSID", etc. where the row launches a
// sub-screen rather than cycling a value in place.
// WiFi-related actions used to live here too (kActionSetSsid /
// kActionSetPassword / kActionWifiConnect). They moved to the
// dedicated `WifiScreen` once we got per-network slots — keep the
// enum tight so the action-row dispatch only carries the actions
// that still ship in this screen.
enum ActionId : uint8_t {
  kActionSetTime,
  kActionReorderMenu,
  kActionResetMenuOrder,
  kActionResyncStartupFiles,
  kActionReformatFFat,
};

struct GroupItem {
  bool        isAction;
  SettingIndex setting;   // valid when !isAction
  ActionId     action;    // valid when isAction
  const char*  label;     // for action rows; setting rows resolve label themselves
};

#define SI(s)   {false, s, kActionSetTime, nullptr}
#define ACT(a, l) {true, kLedBrightness, a, l}

static const GroupItem kDisplayItems[] = {
    SI(kAutoFlipEnable),
    SI(kFlipUpThreshold),
    SI(kFlipDownThreshold),
    SI(kFlipDelayMs),
    SI(kFlipButtons),
    SI(kFlipJoystick),
    SI(kNametagSameWayUp),
    SI(kOledContrast),
    SI(kOledOsc),
    SI(kOledDiv),
    SI(kOledMux),
    SI(kOledPrecharge1),
    SI(kOledPrecharge2),
    SI(kOledRefreshMs),
};
static const GroupItem kHapticItems[] = {
    SI(kHapticEnabled), SI(kHapticStrength), SI(kHapticFreqHz), SI(kHapticPulseMs),
};
static const GroupItem kLedItems[] = {
    SI(kLedBrightness),
    SI(kLedServiceMs),
  
};
static const GroupItem kInputItems[] = {
    SI(kSwapConfirmCancel),
    SI(kJoySensitivity),
    SI(kJoyDeadzone),
    SI(kJoyPollMs),
    SI(kBtnDebounceMs),
    SI(kRptInitialDelayMs),
    SI(kRptFirstIntervalMs),
    SI(kRptSecondDelayMs),
    SI(kRptSecondIntervalMs),
};
static const GroupItem kSleepItems[] = {
    SI(kLightSleepSec), SI(kDeepSleepSec),
};
static const GroupItem kClockItems[] = {
    SI(kHorizonClock),
    ACT(kActionSetTime, "Set Time"),
};
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

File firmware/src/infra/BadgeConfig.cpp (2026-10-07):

#include "BadgeConfig.h"

#include <Preferences.h>
#include <cstdlib>
#include <cstring>
#include <sys/time.h>
#include <time.h>

#include "BuildWifiConfig.h"
#include "../api/WiFiService.h"
#include "../identity/BadgeUID.h"
#include "hardware/Haptics.h"
#include "hardware/IMU.h"
#include "hardware/Inputs.h"
#include "hardware/LEDmatrix.h"
#include "hardware/Power.h"
#include "ir/BadgeIR.h"
#include "Filesystem.h"
#include "hardware/oled.h"
#include "../BadgeGlobals.h"
#include "../screens/draw/AnimDoc.h"

extern "C" {
#include "lib/oofatfs/ff.h"
FATFS* replay_get_fatfs(void);
}

extern oled badgeDisplay;
extern LEDmatrix badgeMatrix;
extern Inputs inputs;
extern SleepService sleepService;
extern IMU imu;
extern Scheduler scheduler;

// ═══════════════════════════════════════════════════════════════════════════════
//  Font-family constants (shared with FileBrowser via BadgeConfig.h)
// ═══════════════════════════════════════════════════════════════════════════════

const uint8_t kFontFamilyCount = 10;
const char* const kFontFamilyNames[] = {
    "Default", "Profont", "Fixed", "Courier",
    "Helvetica", "NCenR", "Boutique", "Terminus",
    "Spleen", "Times"
};

int8_t fontFamilyFromName(const char* name) {
  for (uint8_t i = 0; i < kFontFamilyCount; ++i) {
    if (strcasecmp(name, kFontFamilyNames[i]) == 0) return static_cast<int8_t>(i);
  }
  return -1;
}

// ═══════════════════════════════════════════════════════════════════════════════
//  Config — file-backed settings (INI format on FAT filesystem)
// ═══════════════════════════════════════════════════════════════════════════════

  const Config::SettingDef Config::kDefs[] = {
      {"led_bright",  "LED Bright",  10,   1,   254,  1},
      {"haptic_en",   "Haptics",     1,    0,     1,  1},
      {"haptic_str",  "Haptic Str",  110,  0,   255,  5},
      {"haptic_freq", "Haptic Hz",   80,   10,  1000, 10},
      {"haptic_ms",   "Pulse ms",    35,   5,   500,  5},
      {"joy_sens",    "Joy Sens %",  80,   5,   100,  5},
      {"joy_dead",  "Joy Dead %",    12,    1,    254,   1},
      {"font_fam",    "Font",        8,    0,   9,    1},
      {"font_size",   "Font Size",   4,    0,   9,    1},
      {"lsleep_s",    "LightSlp s",  300,  0,  6000,  30},
      {"dsleep_s",    "DeepSlp s",   1200, 30, 36000, 60},
      {"flip_en",     "Auto Flip",   1,    0,      1,     1},
      {"flip_up",     "Flip Up mG",  -100, -950,   950,     50},
      {"flip_dn",     "Flip Dn mG",  750,  -950,      950,   50},
      {"flip_ms",     "Flip Delay",  0,  0,      30000,  50},
      {"flip_btn",    "Flip Btns",   1,    0,      1,     1},
      {"flip_joy",    "Flip Joy",    1,    0,      1,     1},
      {"name_flip",   "Name Flip",   0,    0,      1,     1},
      {"oled_osc",    "OLED Osc",    15,    0,     15,     1},
      {"oled_div",    "OLED Div",    1,    1,     16,     1},
      {"oled_mux",    "OLED Mux",   64,   16,     64,     1},
      {"oled_pre1",   "PreChg P1",   1,    1,     15,     1},
      {"oled_pre2",   "PreChg P2",   15,    1,     15,     1},
      {"oled_ctr",    "Contrast",  255,    0,    255,     5},

      // Dev-tuning settings
      {"imu_smooth",  "IMU Smooth%", 18,   0,    99,    1},
      {"imu_thr",     "IMU Thr",     10,   0,    127,   1},
      {"imu_dur",     "IMU Dur",     0,    0,    127,   1},
      {"btn_dbnc",    "Debounce ms", 20,   5,    100,   5},
      {"rpt_init",    "RptInit ms",  325,  50,   1000,  25},
      {"rpt_int1",    "RptInt1 ms",  110,  20,   500,   10},
      {"rpt_dly2",    "RptDly2 ms",  900,  100,  3000,  50},
      {"rpt_int2",    "RptInt2 ms",  55,   10,   250,   5},
      {"led_intv",    "LED Intv ms", 25,   5,    200,   5},
      {"oled_rfsh",   "OLED Rfsh ms",100,  16,   500,   5},
      {"joy_poll",    "Joy Poll ms", 20,   5,    100,   5},
      {"sch_high",    "Sch High",    1,    1,    10,    1},
      {"sch_norm",    "Sch Normal",  4,    1,    30,    1},
      {"sch_low",     "Sch Low",     30,   1,    100,   1},
      {"loop_ms",     "Loop ms",     8,    1,    50,    1},
      // CPU freqs snap to kCpuValidMhz[]; step is unused for these indices.
      {"cpu_idle",    "CPU Idle",    80,   20,   240,   1},
      {"cpu_actv",    "CPU Active",  160,  20,   240,   1},
      {"wifi_chk",    "WiFi Chk ms", 30000,1000, 600000, 1000},

     // Boop / IR settings
     {"boop_ir_info","Boop Info",    1,    0,      1,     1},
     {"boop_fields", "Info Fields",  0x1FF,0,   0x1FF,    1},
     {"ir_tx_pw",    "IR TxPow %",  10,    1,     50,     1},

     // Notifications
     {"notify_ir",   "NotifIR",      1,    0,        1,      1},

     {"swap_ok",     "Confirm Btn",  1,    0,        1,      1},
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

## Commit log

2026-05-07 Boot splash + battery alternation + shutdown hold + factory flash tooling
    - BootSplash: temporal-logo starfield played in setup() with hardware
    contrast fade-in/out and per-star scintillation; LED matrix mirrors
    with bounded sparkles. Bottom-right corner shows FIRMWARE_VERSION.
    - BadgeVersion.h: tagged baseline v0.0.0 for shipping.
    - OLEDLayout: battery glyph alternates with the two-digit percent on a
    shared ~1.6s cadence so charging / full / critical states still show
    the actual level.
    - GUI/main: skip the BootScreen Replay-bitmap animation and the pre-
    splash text screen — splash is now the only boot visual.
    - GridMenuScreen: hold DOWN 3s on the home menu to deep-sleep the chip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
    [main.cpp]
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2026-05-08 artificial horizon clock thing, return background LED matrix apps, add tardagotchi to the led matrix when exited
2026-05-08 power: batch probe ADC reads via Policy::probeSamplesPerTick (default 3)
    Cuts BQ24079 CE-high time per probe from ~scheduler-cadence × samples to
    ~probe-burst duration, reclaiming charging duty cycle lost to inter-tick yields.
2026-05-08 power: convert to esp_logi format.
    should make it easy to silence messages depending on the log level now
2026-05-09 buncha fixes, added help, QR codes to all the links, auto recover startup files, comment out other build envs, new icons,
    [BadgeConfig.cpp, SettingsScreen.cpp]
2026-05-09 add wifi support for multiple networks to check, OTA firmware updates, opt in repartitioning (to claim that unused 2MB), fix config loading, idk like a billion little ui fixes
    [partitions_replay_16MB_doom.csv]
2026-05-10 file viewer / editor, gh actions to put doom in releases, online registry to download doom, fixin' stuff
    [partitions_replay_16MB_doom.csv, partitions_replay_16MB_ver2.csv]
2026-05-10 fix some keyboard weirdness, fix doomload failures
    [BadgeOTA.cpp, WiFiService.cpp]
2026-05-11 feat(scanner): phase-1 demo app exercising joystick, buttons, tilt, OLED, matrix
    Adds /apps/scanner/main.py — a self-registering MicroPython app (__title__,
    __description__, __order__) that exercises every I/O channel on the badge:
    joystick moves an 8x8 LED matrix cursor, UP/DOWN/LEFT/RIGHT buttons also move
    it, CONFIRM cycles brightness, IMU face-down dims LEDs, and OLED shows live
    joystick XY, cursor position, and tilt readings. BACK exits cleanly.
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2026-05-12 feat(ble): C-side BLE scanner exposed as badge.ble_scan_* in MicroPython
    Adds a lightweight BLE central scanner (Arduino-ESP32 BLEDevice/BLEScan)
    distinct from the iBeacon-only BleBeaconScanner. The MicroPython bluetooth
    extmod is stripped from this build (NimBLE headers not vendored), so this
    provides BLE access through the badge module instead.
    - src/ble/BleScan.{h,cpp}: 32-entry device table keyed by MAC, mux-protected
    callback, lazy controller init, never deinits (Arduino-BLE has known UAF
    hazards in deinit/reinit cycles).
    - src/micropython/badge_mp_api/mp_api_ble.cpp: temporalbadge_runtime_ble_scan_*
    - HAL + usermod bindings + 5 new MP_QSTR_ble_scan_*. Re-run
    micropython/setup_ar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
    [modtemporalbadge.c, temporalbadge_hal.c]
2026-05-12 feat(flappy_asteroids): mode picker — Both / Asteroids / Flappy
    The dual-screen design was confusing: focusing on the OLED asteroid game
    let the LED-matrix bird game time-out and force a shared game-over even
    though the ship was fine. Splits play_loop into three:
    - play_asteroids: only OLED, matrix dark, only ship-vs-rock ends the run
    - play_flappy: only matrix; OLED shows pipes/score readout
    - play_both: original dual-screen behavior, preserved
    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
2026-05-12 fix(flappy_asteroids): pick_mode reads joystick + settles to ignore held buttons
2026-05-12 feat(leddemos): three ambient LED matrix effects (Fire, Plasma, Matrix Rain)
    New /apps/leddemos with a launcher menu and three full-screen effects on the
    8x8 matrix, each running until BACK:
    - fire.py: cellular-automaton flame with brightness gradient (~30 LOC)
    - plasma.py: dual sine field via 256-entry lookup table (~25 LOC)
    - rain.py: per-column random-speed drops with fading trails (~50 LOC)
    All three exploit the per-pixel brightness range to fake antialiasing/depth
    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
2026-05-12 feat(billboard): rave-style name tag display with 6 effect modes
    New /apps/billboard/ — full-bleed name display with file-loaded name and
    multiple animated effects on both displays.
    - name.txt: first non-empty line is the name (default fallback: 'BADGE')
    - Effects: Scroll, Strobe, Pulse, Marquee, Sparkle, Cycle (auto-rotate every 5s)
    - Mode picker on entry; CONFIRM in single-mode advances to next effect
    - Each effect uses both OLED (big text) and LED matrix (synced eye-candy)
    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
2026-05-12 fix(billboard): real big fonts (up to Spleen 32x64) + reliable BACK exit
    Two fixes:
    - Replaced text_size scaling with the badge's u8g2 font catalog. pick_biggest_font
    walks Spleen 32x64 → 16x32 → 12x24 → ... and uses the largest that fits the
    OLED width via oled_text_width measurement.
    - Fixed the BACK-doesn't-exit bug. button_pressed is edge-triggered, so the
    outer loop's re-check after an effect returned was always False, causing
    BACK in single-mode to advance instead of exit. Effects now return a sentinel
    (EXIT_BACK/EXIT_NEXT/EXIT_TIMEOUT) so the caller dispatches without re-querying.
2026-10-04 docs: correct Echo pin table, add speaker and Tailscale notes
2026-10-05 docs: emotion channel design spec (BLE bridge, approved)
    AI-injectable emotions onto the badge robot face. Transport: BLE GATT
    on the badge + a host-side bridge ("emotion API" with an API key),
    with direct BLE (no bridge) supported by the same code. Covers the
    message schema (mood + intensity + duration), override-then-expire
    semantics, agent feedback (ack + readable state), Raspberry Pi
    gateway deployment, and a host-side voice (BT speaker/mic) extension
    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
2026-10-05 docs: emotion channel implementation plan
    11 tasks across the shared wire-format contract, firmware (NimBLE GATT
    service + host-tested EmotionConsumer + RobotFaceScreen override),
    the Python client (BLE + HTTP backends), the API-key bridge, a Claude
    skill, and coderef library registration. TDD where the logic is pure;
    on-device smoke tests for the BLE/hardware integration.
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2026-10-05 fix(emotion): reject out-of-range mood at point of use (OOB read)
    Security review flagged the BLE-supplied mood byte flowing into
    kMouths[] without a point-of-use bound. The wire decoder already
    rejects mood>=8, but harden chooseOverride() to return false for an
    out-of-range mood and add a defensive bucket guard in updateMatrixMouth.
    Covered by a new host test (frame mood=9 -> no override).
2026-10-05 build(emotion): BADGE_ENABLE_EMOTION_BLE flag + emotion src filter
    Stub EmotionBleService links as a no-op. Baseline (flag on, NimBLE not
    yet linked): RAM 41.3% (135252 B), Flash 66.1% (2684634 B) — unchanged
    from the pre-feature image; the real delta comes in Task 6.
2026-10-05 feat(emotion): NimBLE GATT emotion service (write+state, auth)
    Arduino BLE* API (NimBLE-backed, matches ble/). Write char takes
    [8B secret][6B frame]; bad/unauth writes are ignored (onWrite cannot
    return a GATT error) and the client confirms via the state read. State
    char is the 7-byte struct incl. face_on_screen + autonomous mood.
    Events-notify deferred to phase 2. Flash +124 B only (BLE stack already
    linked via BleScan.cpp); RAM unchanged.
2026-10-05 feat(emotion): wire consumer + BLE service into the app
    g_emotion global bound to RobotFaceScreen; emotionBleBegin started in
    initDeferredPeripherals (dev shared secret, adv name TemporalBadge);
    1 Hz emotionBleStatePublish in loop(). Builds + flashes. On-device
    acceptance follows with the Python BLE client.
2026-10-05 fix(emotion): re-advertise on disconnect; refresh state on write
    A BLE peripheral stops advertising while connected and the Arduino API
    does not resume on its own, so the badge went invisible after the first
    client disconnected — restart advertising in a disconnect callback. And
    recompute the state characteristic the instant a write applies, so a
    client reading state right after an inject sees the new mood instead of
    the value from the last 1 Hz tick.
2026-10-05 feat(emotion): clear/escape — wire clear bit, firmware path, badge gesture
    Add flags bit1 = clear to the 6-byte frame (both codecs together).
    onWrite calls EmotionConsumer::clear() on a clear frame instead of apply.
    On the robot face, confirm clears an active injected emotion (otherwise
    nudges as before), so there's a local escape too.
    Claude-Session: https://claude.ai/code/session_01NU7CQ6Hr8x6XBUcY9gLYwZ
2026-10-05 feat(emotion): clear + host-side sequencing in client/backends/bridge
    EmotionClient.clear()/sequence(); BleBackend and HttpBackend gain clear()
    and sequence(). Bridge adds DELETE /emotion (clear) and POST /sequence
    (plays steps server-side as a per-target task). Any new emotion/clear/
    sequence cancels a running sequence, so context changes switch instantly.
    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
2026-10-05 fix(emotion): confirm-clear gesture unreachable on swapped badges
    The robot face exited on the raw B button (|| e.bPressed) before the
    confirm handler ran. On a badge with kSwapConfirmCancel set, confirm is
    the B pad, so every face-button press popped the screen and the
    clear-on-confirm gesture could never fire. Exit on semantic cancel only;
    confirm (whichever pad it maps to) now reaches the clear. Verified
    on-device: inject happy -> press confirm -> state override returns to None.
    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
2026-10-05 fix(emotion): commit robot-face draw primitive and screen id
    RobotFaceScreen.cpp calls oled::drawDisc and GUI.cpp references the
    kScreenRobotFace ScreenId, but their definitions were left uncommitted
    during the original plan run — the branch did not build from a clean
    checkout; it only ran because the badge was flashed from the dirty
    working tree. Commit the three so HEAD builds.
    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
    [oled.cpp]
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2026-10-05 docs: fix headline MCU description (ECHO/WROOM-1, not MINI-1/XIAO)
    The README and CLAUDE.md headlines described the whole badge as an
    ESP32-S3-MINI-1 (XIAO form factor), but that's the older DELTA revision.
    The current/default build is ECHO (EchoDefines.h) on an ESP32-S3-WROOM-1
    (N16R8) custom board with a 128x64 SSD1309 OLED -- the badge in hand.
    Scoped to the two headline descriptions only; the Hardware Targets table
    and DeltaDefines.h remain correct for DELTA.
    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
2026-10-05 docs: correct OLED size to 2.42in from measured glass (not 1.8in)
    Measured module glass is ~60x38mm (2 3/8in x 1 1/2in), the standard
    2.42in 128x64 OLED footprint (SSD1309, active ~55x27.5mm). The earlier
    1.8in was an unmeasured guess from pixel size; corrected to the measured
    value.
    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
2026-10-05 feat(emotion): show-face flag and BLE writes keep the badge awake
    Frame flag bit2 (kFlagShowFace) asks the badge to bring the robot face
    screen up. EmotionConsumer records the request; the main loop pushes
    kScreenRobotFace when the GUI is free and the face isn't already up. A
    running Python app blocks the loop, and Doom deactivates the GUI, so the
    request waits for either to finish instead of interrupting it.
    Every accepted emotion write (apply or clear) now also counts as
    activity: the main loop sets sleepService.caffeine, so a battery badge
    being driven over BLE (Rocky's face) doesn't deep-sleep after 20 min
    without motion. Keep-alive state reads don't count.
    Host tests: test_emotion_fra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
    [main.cpp]
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2026-10-06 firmware: tread drive review fixes (stale commands, IR lease, smaller TX buffer, script pacing)
    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
    [BadgeIR.cpp]
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2026-10-06 docs: rocky-pi tread drive design rev 2, corrections from the stage 1 build
    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
2026-10-07 firmware: Name Flip setting keeps the name screen the same way up as the menus
    A badge mounted so that it senses itself turned over drew its name
    screen upside down for the person looking at it. With name_flip on, the
    name screen is no longer turned. Off by default.
    The settings file buffer grows to 6144 bytes; the helicopter settings
    and this one had brought the file close to the old limit.
    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
    [BadgeConfig.cpp, SettingsScreen.cpp]
2026-10-07 docs: rocky body feedback design rev 4, switch-on delay test skipped
2026-10-07 docs: rocky body feedback design rev 4, decision to retry a failed legs mood
